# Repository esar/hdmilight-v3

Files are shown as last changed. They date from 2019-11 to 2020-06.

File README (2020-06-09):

This is a still-in-progress update to my hdmilight-v2 project.

Differences in this version:
 * Everything is on a standalone board, no longer needs a Papilio FPGA board
 * AVR CPU removed from FPGA design and replaced by a separate ARM Cortex MCU.
   The main reason for this change was to get more program memory. The FPGA
   had no more spare block RAMs. It also has the advantage of being a much
   more capable CPU and having live debugging via JTAG.
 * Power supply switching for the LEDs. This version can power down the 
   LED strips when not in use.
 * Extra pins added to each LED output port, now have +5V, DAT, GND, CLK
   Currently it still only support 3-wire LED strips, but in the future
   it should be able to support 4-wire clocked strips
 * Magical mystery connectors (vivepos / papix). The real reason I made
   this revision... a platform to experiment with my crazy ideas

Build instructions:

 1) Manufacture the HDMI receiver board that can be found in 
    the 'board' directory (KiCad format).
 2) Open the 'fpga/hdmilight.xise' project in Xilinx ISE and
    generate a bit file.
 3) Edit the files under the config directory to configure
    the LEDs.
 5) Run 'make' in the top level directory, which will do the following:
      * Build the firmware image
      * Convert the text config file to binary format
      * Append the config to the end of the FPGA bit file
      * Flash the ARM microcontroller with the firmware
      * Flash the FPGA config flash with the bit file
 8) Connect LED strips to output pins
 9) Open a serial terminal to the board 
    (running "dmesg" is useful to see names of recently added serial ports)
 10) Connect HDMI source to receiver board
 11) It should now be working. 

This version should now have feature parity with version 2, however
it has not been tested very well yet.

Useful build targets:
 * make firmware: build the firmware without flashing
 * make firmware_flash: flash the last build to the ARM
 * make fpga_program: reprogram FPGA without programming flash
                      will be lost on thxt power-cycle
 * make fpga_flash: reprogram the FPGA flash
 * make fpga_flash_config: reprogram just the configuration part of the FPGA flash

Debugging the firmware:
 1) start openocd: openocd -f hdmilight-v3-openocd.cfg
 2) start gdb: arm-none-eabi-gdb
 3) in gdb, load firmware: file firmware/main.elf
 4) in gdb, connect to board: target remote :3333

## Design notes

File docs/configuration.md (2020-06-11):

Configuration
=============

The configuration is controlled by the files in the config directory.
During the build these text files get converted to binary format by the python
scripts in the tools directory, and then they get merged together into one big
binary blob which is then written to the FPGA's flash chip.

There can be up to 64 different configurations and the HDMI Light can switch
between them automatically based on the incoming video resolution and aspect ratio.

Each of the configurations is controlled by the files in the `config/config_x`
directory, where _x_ is a number starting from 0. Each directory contains the
following config files:
* area.conf: Defines rectangular areas of the screen that should be averaged
             together to produce a colour.
* `output_x.conf`: One file for each LED output port. Defines which area and
                   colour correction data should be used to set the colour
                   of each LED connected to that port
* `colour_x.conf`: Defines each of the 8 colour correction matrices
* `gamma_r_x.conf`: Defines each of the 8 gamma curves for the red channel
* `gamma_g_x.conf`: Defines each of the 8 gamma curves for the green channel
* `gamma_b_x.conf`: Defines each of the 8 gamma curves for the blue channel
* delay.conf: Controls how much delay there is between the incoming video changing 
              and the LED colours changing

In addition to the files above, there are two global configuration files in the 
top level config directory:
* format.conf: Controls which configuration is loaded for a particular resolution
               and aspect ratio
* keys.conf: Defines the key mapping for CEC remote control actions.

The following sections describe each configuration file in detail. 

format.conf
-----------

The format configuration file contains one line for each known resolution and
aspect ratio. Each line has four columns:
* X Resolution
* Y Resolution
* Aspect ratio, which must be one of 1.33, 1.77, 2.44
* Index of the configuration to use for this resolution and aspect ratio

For example, this file defines three known formats for the three different aspect
ratios for 1920x1080
```
# width  height  ratio  config
  1920   1080    1.77   0
  1920   1080    2.40   1
  1920   1080    1.33   2
```

With this format config file the HDMI Light will use `config_0` for full screen
content, `config_1` for wide-screen content, and `config_2` for old narrow content.

When the incoming video format changes the HDMI Light will look for a matching
entry in the format config file and if it finds one then it will switch to the
specified configuration. If no matching entry is found then it will continue
to use the current configuration.

area.conf
---------

The area configuration file defines rectangular areas of the screen. The colour of
each pixel within the rectangles is averaged together to generate the colour to be
used for the LEDs.

Each line in the file contains five columns:
* xmin: The X coordinate of the left edge of the rectangle
* xmax: The X coordinate of the right edge of the rectangle
* ymin: The Y coordinate of the bottom of the rectangle
* ymax: The Y coordinate of the top of the rectangle
* divshift: How to divide the result after summing the pixels

The first four columns should be fairly self explanatory, they just define the 
coordinates of the rectangle. These coordinates use a reduced resolution compared
to the incoming video. The incoming video is scaled by 32, so for 1920x1080 the
coordinates in this are 0-59 for X, and 0-32 for Y.
The origin is the top left of the screen.

The last parameter is harder to explain. Especially if you're not familiar with how 
binary numbers operate. The averaging of the pixel colours in the rectangle is done
by summing all of the R, G and B values together and then dividing the result by the
number of pixels in the rectangle. However, a true division is a _very_ expensive
operation to perform in an FPGA, so instead we take advantage of the fact that each 
time we shift the digits of a binary number to the right, we divide the value by 2.
This last parameter defines how many places to shift the result to the right to 
perform the required division.

The following values are valid:
* 0: don't divide
* 1: divide by 2
* 2: divide by 4
* 3: divide by 8
* 4: divide by 16
* 5: divide by 32
* 6: divide by 64
* 7: divide by 128
* 8: divide by 256
* 9: divide by 512
* 10: divide by 1024
* 11: divide by 2048
* 12: divide by 4096
* 13: divide by 8192
* 14: divide by 16382
* 15: divide by 32768

As can be seen in this list, we can only divide by powers of two, so we are limited
to rectangles whose area is also a power of two, otherwise we can't get the correct 
result.

output.conf
-----------

There is one output configuration file for each of the eight LED strips that can be
connected. Each file contains one line for each LED that is connected to that port.
Each line contains five columns:
* index: The LED number. It's not actually used by anything, it's just there to make 
         life easier when manually editing the file
* area:  The index of the area to use for this LED
* colour: The index of the colour matrix that should be used for this LED
* gamma: The index of the gamma curve that should be used for this LED
* enable: Whether the LED is enabled (0=disabled, 1=enabled)

If colour correction is not being used then there are really only two important
columns: area and enable. For each LED, simply select which area from area.conf should
be used to select the colour for the LED. Then set enable to 1. 
The colour and gamma columns can be set to 0 (assuming the related config files have
been left on their default do-nothing values).

The first line in the file is the LED nearest the HDMI Light.

If colour correction is desired then the colour and gamma indices can be set to the 
relevant colour matrix and gamma curve that should be used for each LED.

One important thing to note is that the enable column cannot be used to disable individual
LEDs in the middle of a run, the column should be all 1's. If there are excess LEDs in the 
file then they can be set to 0, but there must be a continuous run of 1's followed by a 
continuous run of 0's. It is not valid to switch back and forth between 1 and 0.

If you want to switch off LEDs in the middle of a run, then a good way to do it is to
change one of the colour configurations to have brightness set to 0 for all channels.
Then simply select that colour matrix for the LEDs that you want disabled and they will
always be set to black and will not light up.

colour.conf
-----------

The colour configuration files define a colour matrix that can be used to colour correct
individual LEDs. A default do-nothing configuration file looks like this:

```
matrixR = 1.000 0.000 0.000
matrixG = 0.000 1.000 0.000
matrixB = 0.000 0.000 1.000
matrixC = 0.000 0.000 0.000

brightR = 1.0
brightG = 1.0
brightB = 1.0

contrast = 1.0

saturation = 1.0
```

The first section defines a raw matrix, in the example above it is the identity matrix
where the red output comes 100% from the red input, green 100% from green, and blue
100% from blue. The last line `matrixC` is for adding constant values to the channels
and in this case it is adding 0 to each channel.

The second section controls relative brightness of each channel. In the example above
it does nothing, each channel is 100%. This value can be increased as well as decreased.
For example setting a channel to 2.0 will multiply the brightness by 2, and setting a 
channel to 0.5 would cut the brightness in half.

Next is a contrast adjustment, and then a saturation adjustment.

The brightness, contrast, and saturation values are all converted to matrices. Then all
of these matrices are multiplied together and with the raw matrix at the top of the file
to produce a final colour correction matrix that is used to adjust the LED colours.

gamma.conf
----------

There can be 8 sets of gamma correction curves, and each set has a separate curves for 
each channel. The configuration file simply contains a single value which defines the
gamma curve. A default do-nothing file would contain the value 1.0 which defines a
straight line so that each input value results in the same value being output.

delay.conf
----------

The delay configuration file allows the output of the HDMI Light to be precisely
synchronised with the TV. By default the HDMI Light will update the LEDs immediately
when the incoming video frame ends, but modern TVs generally lag a few frames as they
do a lot of internal processing on the video.

The configuration file contains three values:
* frames: how many whole frames to delay
* ticks: how many extra microseconds to delay after the frame count
* smooth: temporal smoothing factor. 

The frames parameter should be self explanatory, it simply delays the output by the
specified number of frames. Valid values are from 0 to 8.

The ticks parameter should be ignored. There is no point in trying to set the delay
that accurately as it takes so long to clock the data out to the LED strips that the
accuracy is lost.

The final parameter is the temporal smoothing factor. It defines how much of the colour
for an LED comes from the new colour and how much comes from the previous colour.
Setting this to 0.0 will disable temporal smoothing and the colour of an LED will come
entirely from the new colour from the area on the screen.
Setting this to 0.5 will use 50% of the previous colour and 50% of the new colour.

My TV delays its output by 2 frames. I find that the following settings all give 
perfect synchronisation:
* frames = 2, smooth = 0.0
* frames = 1, smooth = 0.6
* frames = 0, smooth = 0.75

Personally I prefer the last option which makes it fade between sudden colour changes.

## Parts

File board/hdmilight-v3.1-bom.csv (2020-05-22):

Designator | Package | Quantity | Designation | Part # | Farnell # | Unit GBP | Total GBP
C116,C114,C112,C110,C108,C106,C104,C102,C100,C98,C72,C83,C82,C79 | C_0805_2012Metric | 14 | 4.7uF |  |  |  | 0
C117,C115,C113,C111,C109,C107,C105,C103,C101,C99,C86,C85,C84,C81,C80,C78,C77,C76,C75,C74,C73 | C_0402_1005Metric | 21 | 0.47uF |  |  |  | 0
C19,C20,C21 | C_0603_1608Metric | 3 | 1nF |  |  |  | 0
C22,C23,C24,C28,C29,C30 | C_0603_1608Metric | 6 | DNI |  |  |  | 0
C25,C26,C27 | C_0603_1608Metric | 3 | 0.047uF |  |  |  | 0
C3,C4 | C_0603_1608Metric | 2 | 12pF |  |  |  | 0
C36 | C_0603_1608Metric | 1 | 2.2uF |  |  |  | 0
C37 | C_0805_2012Metric | 1 | DNI |  |  |  | 0
C38,C39,C42,C44,C46,C48,C52,C54 | CP_EIA-3528-21_Kemet-B | 8 | 33uF | Kemet: T491B336K006AT | 2408593 | 0.396 | 3.168
C50,C2,C10,C11,C12,C13,C14,C15,C40,C41,C43,C45,C47,C49,C53,C55 | C_0603_1608Metric | 16 | 0.1uF |  |  |  | 0
C51,C16,C17,C18,C31,C32,C33,C34,C35 | C_0805_2012Metric | 9 | 22uF | TDK: C2012X5R1A226M085AC | 2526256 | 0.493 | 4.437
C57,C56 | C_0603_1608Metric | 2 | 18pF |  |  |  | 0
C58 | C_0603_1608Metric | 1 | 0.01uF |  |  |  | 0
C9,C118,C1,C97,C96,C95,C94,C8,C6,C93,C91,C7,C5,C92,C90,C89,C88,C87,C71,C70,C69,C68,C67,C66,C65,C64,C63,C62,C61,C60,C59 | C_0402_1005Metric | 31 | 0.1uF |  |  |  | 0
D2 | LED_0603_1608Metric | 1 | LED Green | Kingbright: KPH-1608SGC | 2426215 | 0.09 | 0.09
D5,D4 | D_SOD-323 | 2 | 2A | NXP: PMEG3020EJ,115 | 1757772 | 0.332 | 0.664
D6,D1 | LED_0603_1608Metric | 2 | LED Red | Kingbright: KPT-1608EC | 2099221 | 0.107 | 0.214
D7 | D_SOD-323 | 1 | 5V1 | On Semi: MM3Z5V1ST1G | 2317476 | 0.098 | 0.098
D8,D3 | LED_0603_1608Metric | 2 | LED Side Red | Kingbright: KPA-1606SURCK | 2290358 | 0.16 | 0.32
D9 | LED_0603_1608Metric | 1 | LED Side Green | Kingbright: KPA-1606CGCK | 2290360 | 0.17 | 0.17
F2,F1 | Fuse_1206_3216Metric | 2 | 1206L050 | Littelfuse: 1206L050YR | 1596993 | 0.285 | 0.57
FB7,FB1,FB2,FB3,FB4,FB5,FB6,FB8,FB9 | L_0805_2012Metric | 9 | 22ohm@100MHz | Murata: BLM21PG220SN1D | 1515659 | 0.055 | 0.495
J1 | USB_Micro-B_Amphenol_10103594-0001LF_Horizontal | 1 | USB_B_Micro | Amphenol: 10103594-0001LF | 2293752 | 0.44 | 0.44
J10,J6,J5,J4 | PinSocket_1x08_P2.54mm_Vertical | 4 | Conn_01x08 | Multicomp: 2212S-08SG-85 | 1593463 | 0.17 | 0.68
J11 | TerminalBlock_Phoenix_MKDS-1,5-2_1x02_P5.00mm_Horizontal | 1 | Screw_Terminal_01x02 | Phoenix: MKDS 1,5/2 | 3714240 | 1.05 | 1.05
J12,J3 | PinHeader_1x02_P2.54mm_Vertical | 2 | Conn_01x02_Male | Multicomp: MC34745 | 1593426 | 0.017 | 0.017
J13 | PinSocket_1x09_P2.54mm_Vertical | 1 | Conn_01x09 | Multicomp: 2212S-09SG-85 | 2847198 | 0.2 | 0.2
J14 | PinHeader_2x10_P2.54mm_Horizontal | 1 | Conn_02x10_Odd_Even | Amp: 1-826634-0 | 3418649 | 2.2 | 2.2
J2 | HDMI_SOCKET_FCI_10029449 | 1 | HDMI_A | Amphenol/FCI: 10029449-001RLF | 2112524 | 1.22 | 1.22
J7 | IDC-Header_2x05_P2.54mm_Horizontal | 1 | Conn_02x05_Odd_Even | Amp: 5103310-1 | 2452436 | 0.89 | 0.89
J8,J9 | RJ12_Amphenol_54601 | 2 | 6P6C | Amphenol: 54601-906WPLF | 2135977 | 0.265 | 0.53
L1,L2 | L_Bourns-SRN4018 | 2 | 4.7uH/2.1A | TDK: SPM4020T-4R7M-LR | 2564035 | 1.52 | 3.04
L3 | L_Bourns-SRN4018 | 1 | 2.2uH/3.5A | TDK: SPM4015T-2R2M-LR | 2564023 | 0.342 | 0.342
Q1 | TO-252-2 | 1 | IPD90P03P4L04 | Vishay: SUD50P04-08-GE3 | 1794811 | 1.38 | 1.38
Q5,Q2,Q4,Q3 | SOT-23 | 4 | BSS123 | On Semi: BSS123 | 9845321 | 0.254 | 0.762
R13 | R_0603_1608Metric | 1 | 27K |  |  |  | 0
R14,R15,R18,R19,R20,R48,R51 | R_0603_1608Metric | 7 | 47K |  |  |  | 0
R2,R3 | R_0603_1608Metric | 2 | 27R |  |  |  | 0
R39 | R_0603_1608Metric | 1 | 15K |  |  |  | 0
R40 | R_0603_1608Metric | 1 | 33K |  |  |  | 0
R42 | R_0603_1608Metric | 1 | 150R |  |  |  | 0
R43 | R_0603_1608Metric | 1 | 18K |  |  |  | 0
R49 | R_0603_1608Metric | 1 | 20K |  |  |  | 0
R5 | R_0603_1608Metric | 1 | 1K5 |  |  |  | 0
R55,R54,R53 | R_0603_1608Metric | 3 | 4K7 |  |  |  | 0
R57,R56,R69,R44,R41,R4,R16,R45,R46,R47,R50,R22 | R_0603_1608Metric | 12 | 10K |  |  |  | 0
R58,R60,R21,R1,R52 | R_0603_1608Metric | 5 | 2K2 |  |  |  | 0
R59,R17 | R_0603_1608Metric | 2 | 100K |  |  |  | 0
R6 | R_0603_1608Metric | 1 | 470R |  |  |  | 0
R68,R67,R66,R65,R64,R63,R62,R61,R23,R24,R25,R26,R27,R28,R29,R30,R31,R32,R33,R34,R35,R36,R37,R38 | R_0603_1608Metric | 24 | 82R |  |  |  | 0
R7,R8,R9 | R_0603_1608Metric | 3 | 68R |  |  |  | 0
R70 | R_0603_1608Metric | 1 | 330R |  |  |  | 0
R71,R10,R11,R12 | R_0603_1608Metric | 4 | 1K |  |  |  | 0
RV1 | R_0603_1608Metric | 1 | V5.5MLA0603H | Littelfuse: V5.5MLA0603H | 1757273 | 0.36 | 0.36
SW1 | SW_SPST_EVQP0 | 1 | SW_Push |  |  |  | 0
SW2 | SW_Tactile_SPST_Angled_PTS645Vx31-2LFS | 1 | SW_Push | C&K: PTS645VH58-2LFS | 2320088 | 0.201 | 0.201
U1 | LQFP-64_10x10mm_P0.5mm | 1 | STM32F303RETx | ST Micro: STM32F303RET6 | 2466939 | 6.56 | 6.56
U12 | QFN-32-1EP_5x5mm_P0.5mm_EP3.1x3.1mm_ThermalVias | 1 | TPS65266 | Texas: TPS65266RHBT | 2471151 | 3.92 | 3.92
U2 | SOIC-8_3.9x4.9mm_P1.27mm | 1 | DNI | Microchip: 93C46BT-I/SN | 1607557 | 0.18 | 0.18
U3 | LQFP-48_7x7mm_P0.5mm | 1 | FT2232D | FTDI: FT2232D | 1615843 | 5.7 | 5.7
U4 | LQFP-64-1EP_10x10mm_P0.5mm_EP6.5x6.5mm_ThermalVias | 1 | ADV7611 | Analog: ADV7611 |  | 6.5 | 6.5
U5 | TQFP-144_20x20mm_P0.5mm | 1 | XC6SLX9-TQG144 | Xilinx: XC6SLX9-2TQG144C | 2763358 | 14.91 | 14.91
U6 | TSSOP-38_4.4x9.7mm_P0.5mm | 1 | TPD12S520 | Texas: TPD12S520DBTR | 3116492 | 1.19 | 1.19
U7 | SOIC-8_5.23x5.23mm_P1.27mm | 1 | S25FL064L | Cypress: S25FL064LABMFI010 | 2768034 | 1.68 | 1.68
U8,U9,U10,U11 | TSSOP-20_4.4x6.5mm_P0.65mm | 4 | 74LVC245 | Texas: SN74LVC245APW | 2342392 | 0.626 | 2.504
X1 | Oscillator_SMD_Abracon_ASE-4Pin_3.2x2.5mm | 1 | SG-310SCF-32MHz | Multicomp: MCSJK-3N-32.00-3.3-25-B | 2425493 | 0.639 | 0.639
Y1 | Crystal_SMD_7050-4Pin_7.0x5.0mm | 1 | 6MHz / 12pF | Euroquartz: 6.000MHZ MQ/30/30/-40+90/12PF | 1640909 | 1.73 | 1.73
Y2 | Crystal_SMD_5032-2Pin_5.0x3.2mm | 1 | 28.63636MHz / 18pF | TXC: 7A-28.63636MAAJ-T | 1841958 | 0.665 | 0.665
TOTAL |  | 249 |  |  |  |  | 69.716

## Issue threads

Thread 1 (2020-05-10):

Need some readme file like hdmilight-v2

xfce, 2020-05-10:
Hi @esar ,
    So i think I can fellow the v3 hdmilight.
Now for FPGA I can use xilinx ise got the fpga/HdmilightTop.bit
and what is the next steps?
When got the v3 hardware, Plug into  PC usb and In the top level directory, type
make fpga_program
fpga_flash
make v2_all

esar, 2020-05-10:
I've updated the makefiles to make them a bit more user friendly and updated the README with the current instructions.

xfce, 2020-05-11:
@esar OK, Thanks.
I will use your board, Does the v3.1 gerber file good for manufacture.

esar, 2020-05-11:
I don't know yet, I'm waiting for boards to arrive so that I can test it. Hopefully they won't take too long to arrive.

xfce, 2020-05-14:
OK, thanks. I have order 5pcs boards use v3.1 gerber, and will fellow with you^-^

esar, 2020-05-19:
@xfce My boards arrived and I spent the weekend populating and testing one. It looks like the PCB design is ok, I've not found any issues with that yet.
In case you find it useful, I've added a wiki page detailing the steps that I took to test the board:
https://github.com/esar/hdmilight-v3/wiki/V3.1-Board-Testing-Notes

xfce, 2020-05-20:
@esar  OK , Thanks. Actually , My have also arrived, and waiting for your wiki ^-^
Bellow is the PCB, left is HDMILIGHT V3.1, right is my other PCB
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

xfce, 2020-05-27:
@esar Hi, I have solder most of the components.
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

And also I still want to try the HDMILIGHT V2.0, as it seems much simple , so I have draw the schematics , could you please help me to review it, thanks. bellow is the schematic file.

https://www.dropbox.com/s/ve5g6pb5ufv5kbx/HDMILIGHT_V2.pdf?dl=0

esar, 2020-05-27:
@xfce Cool, looking good!

I've only had time to take a quick look at your schematic, so I've not checked all the connections, but what I have checked looks good. I just have a couple of things to mention:
1) Xilinx recommend a strong pull up on the DONE pin. I can't remember for sure and don't have the Papilio Pro schematic to hand, but I'm guessing that you're copying what was done there, in which case it should be fine. I had no problem using the Papilio board. Here's where Xilinx recommend it: https://www.xilinx.com/support/answers/35002.html

2) The data and clock pairs on the in and out side of the ESD protection chip need to be connected together. There needs to be traces under the chip as the chip doesn't pass them through, it just clamps them. Maybe the software you're using allows you to route them without them connected in the schematic?

3) You don't need the eeprom attached to the FTDI chip. At least JTAG and serial both work without it when using openocd. I've not tried without it when using the Papilio loader software that I used with v2 though.

4) I don't know how familiar you are with FPGAs... keep in mind that you can be quite flexible with the FPGA pins used to connect to the ADV7611. You can change the mapping in the .ucf file in the fpga directory. It's nice to be able to swap them around sometimes when it makes routing the board easier. The only pin that is really restricted is the LLC pin from the ADV7611. This is the video clock and it should be kept on one of the FPGA pins that is connected to a global clock network within the FPGA (the ones with GCLK in their pin name).

Closed 2020-05-14.

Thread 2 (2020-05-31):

make error

xfce, 2020-05-31:
Hi @esar,
    I have finished the V3 board, seems STM32F303 and FTDI are OK, spart6 partly OK .
When I type make, got some error, as bellow, please give some advise, thanks

bi4wms@bi4wms-ThinkPad-X230:~/projects/hdmilight-v3$  make
make -C firmware size
make[1]: Entering directory '/home/bi4wms/projects/hdmilight-v3/firmware'
arm-none-eabi-gcc -c -fno-common -Os -g3 -mcpu=cortex-m4 -mthumb -mfpu=fpv4-sp-d16 -mfloat-abi=hard -std=gnu99 -Wall -ffunction-sections -fdata-sections -fno-builtin -Wno-unused-function -ffreestanding -DSTM32F303xE -I../../STM32Cube_FW_F3_V1.10.0/Drivers/CMSIS//Include/ -I../../STM32Cube_FW_F3_V1.10.0/Drivers/CMSIS//Device/ST/STM32F3xx/Include/ -I./   -c -o main.o main.c
arm-none-eabi-gcc -c -fno-common -Os -g3 -mcpu=cortex-m4 -mthumb -mfpu=fpv4-sp-d16 -mfloat-abi=hard -std=gnu99 -Wall -ffunction-sections -fdata-sections -fno-builtin -Wno-unused-function -ffreestanding -DSTM32F303xE -I../../STM32Cube_FW_F3_V1.10.0/Drivers/CMSIS//Include/ -I../../STM32Cube_FW_F3_V1.10.0/Drivers/CMSIS//Device/ST/STM32F3xx/Include/ -I./   -c -o clock.o clock.c
arm-none-eabi-gcc -c -fno-common -Os -g3 -mcpu=cortex-m4 -mthumb -mfpu=fpv4-sp-d16 -mfloat-abi=hard -std=gnu99 -Wall -ffunction-sections -fdata-sections -fno-builtin -Wno-unused-function -ffreestanding -DSTM32F303xE -I../../STM32Cube_FW_F3_V1.10.0/Drivers/CMSIS//Include/ -I../../STM32Cube_FW_F3_V1.10.0/Drivers/CMSIS//Device/ST/STM32F3xx/Include/ -I./   -c -o power.o power.c
arm-none-eabi-gcc -c -fno-common -Os -g3 -mcpu=cortex-m4 -mthumb -mfpu=fpv4-sp-d16 -mfloat-abi=hard -std=gnu99 -Wall -ffunction-sections -fdata-sections -fno-builtin -Wno-unused-function -ffreestanding -DSTM32F303xE -I../../STM32Cube_FW_F3_V1.10.0/Drivers/CMSIS//Include/ -I../../STM32Cube_FW_F3_V1.10.0/Drivers/CMSIS//Device/ST/STM32F3xx/Include/ -I./   -c -o standby.o standby.c
arm-none-eabi-gcc -c -fno-common -Os -g3 -mcpu=cortex-m4 -mthumb -mfpu=fpv4-sp-d16 -mfloat-abi=hard -std=gnu99 -Wall -ffunction-sections -fdata-sections -fno-builtin -Wno-unused-function -ffreestanding -DSTM32F303xE -I../../STM32Cube_FW_F3_V1.10.0/Drivers/CMSIS//Include/ -I../../STM32Cube_FW_F3_V1.10.0/Drivers/CMSIS//Device/ST/STM32F3xx/Include/ -I./   -c -o uart.o uart.c
arm-none-eabi-gcc -c -fno-common -Os -g3 -mcpu=cortex-m4 -mthumb -mfpu=fpv4-sp-d16 -mfloat-abi=hard -std=gnu99 -Wall -ffunction-sections -fdata-sections -fno-builtin -Wno-unused-function -ffreestanding -DSTM32F303xE -I../../STM32Cube_FW_F3_V1.10.0/Drivers/CMSIS//Include/ -I../../STM32Cube_FW_F3_V1.10.0/Drivers/CMSIS//Device/ST/STM32F3xx/Include/ -I./   -c -o printf.o printf.c
arm-none-eabi-gcc -c -fno-common -Os -g3 -mcpu=cortex-m4 -mthumb -mfpu=fpv4-sp-d16 -mfloat-abi=hard -std=gnu99 -Wall -ffunction-sections -fdata-sections -fno-builtin -Wno-unused-function -ffreestanding -DSTM32F303xE -I../../STM32Cube_FW_F3_V1.10.0/Drivers/CMSIS//Include/ -I../../STM32Cube_FW_F3_V1.10.0/Drivers/CMSIS//Device/ST/STM32F3xx/Include/ -I./   -c -o adv7611.o adv7611.c
arm-none-eabi-gcc -c -fno-common -Os -g3 -mcpu=cortex-m4 -mthumb -mfpu=fpv4-sp-d16 -mfloat-abi=hard -std=gnu99 -Wall -ffunction-sections -fdata-sections -fno-builtin -Wno-unused-function -ffreestanding -DSTM32F303xE -I../../STM32Cube_FW_F3_V1.10.0/Drivers/CMSIS//Include/ -I../../STM32Cube_FW_F3_V1.10.0/Drivers/CMSIS//Device/ST/STM32F3xx/Include/ -I./   -c -o fpga.o fpga.c
arm-none-eabi-gcc -c -fno-common -Os -g3 -mcpu=cortex-m4 -mthumb -mfpu=fpv4-sp-d16 -mfloat-abi=hard -std=gnu99 -Wall -ffunction-sections -fdata-sections -fno-builtin -Wno-unused-function -ffreestanding -DSTM32F303xE -I../../STM32Cube_FW_F3_V1.10.0/Drivers/CMSIS//Include/ -I../../STM32Cube_FW_F3_V1.10.0/Drivers/CMSIS//Device/ST/STM32F3xx/Include/ -I./   -c -o fixed_point.o fixed_point.c
arm-none-eabi-gcc -c -fno-common -Os -g3 -mcpu=cortex-m4 -mthumb -mfpu=fpv4-sp-d16 -mfloat-abi=hard -std=gnu99 -Wall -ffunction-sections -fdata-sections -fno-builtin -Wno-unused-function -ffreestanding -DSTM32F303xE -I../../STM32Cube_FW_F3_V1.10.0/Drivers/CMSIS//Include/ -I../../STM32Cube_FW_F3_V1.10.0/Drivers/CMSIS//Device/ST/STM32F3xx/Include/ -I./   -c -o format.o format.c
arm-none-eabi-gcc -c -fno-common -Os -g3 -mcpu=cortex-m4 -mthumb -mfpu=fpv4-sp-d16 -mfloat-abi=hard -std=gnu99 -Wall -ffunction-sections -fdata-sections -fno-builtin -Wno-unused-function -ffreestanding -DSTM32F303xE -I../../STM32Cube_FW_F3_V1.10.0/Drivers/CMSIS//Include/ -I../../STM32Cube_FW_F3_V1.10.0/Drivers/CMSIS//Device/ST/STM32F3xx/Include/ -I./   -c -o cmd_area.o cmd_area.c
arm-none-eabi-gcc -c -fno-common -Os -g3 -mcpu=cortex-m4 -mthumb -mfpu=fpv4-sp-d16 -mfloat-abi=hard -std=gnu99 -Wall -ffunction-sections -fdata-sections -fno-builtin -Wno-unused-function -ffreestanding -DSTM32F303xE -I../../STM32Cube_FW_F3_V1.10.0/Drivers/CMSIS//Include/ -I../../STM32Cube_FW_F3_V1.10.0/Drivers/CMSIS//Device/ST/STM32F3xx/Include/ -I./   -c -o cmd_colour.o cmd_colour.c
arm-none-eabi-gcc -c -fno-common -Os -g3 -mcpu=cortex-m4 -mthumb -mfpu=fpv4-sp-d16 -mfloat-abi=hard -std=gnu99 -Wall -ffunction-sections -fdata-sections -fno-builtin -Wno-unused-function -ffreestanding -DSTM32F303xE -I../../STM32Cube_FW_F3_V1.10.0/Drivers/CMSIS//Include/ -I../../STM32Cube_FW_F3_V1.10.0/Drivers/CMSIS//Device/ST/STM32F3xx/Include/ -I./   -c -o cmd_delay.o cmd_delay.c
arm-none-eabi-gcc -c -fno-common -Os -g3 -mcpu=cortex-m4 -mthumb -mfpu=fpv4-sp-d16 -mfloat-abi=hard -std=gnu99 -Wall -ffunction-sections -fdata-sections -fno-builtin -Wno-unused-function -ffreestanding -DSTM32F303xE -I../../STM32Cube_FW_F3_V1.10.0/Drivers/CMSIS//Include/ -I../../STM32Cube_FW_F3_V1.10.0/Drivers/CMSIS//Device/ST/STM32F3xx/Include/ -I./   -c -o cmd_format.o cmd_format.c
arm-none-eabi-gcc -c -fno-common -Os -g3 -mcpu=cortex-m4 -mthumb -mfpu=fpv4-sp-d16 -mfloat-abi=hard -std=gnu99 -Wall -ffunction-sections -fdata-sections -fno-builtin -Wno-unused-function -ffreestanding -DSTM32F303xE -I../../STM32Cube_FW_F3_V1.10.0/Drivers/CMSIS//Include/ -I../../STM32Cube_FW_F3_V1.10.0/Drivers/CMSIS//Device/ST/STM32F3xx/Include/ -I./   -c -o cmd_gamma.o cmd_gamma.c
arm-none-eabi-gcc -c -fno-common -Os -g3 -mcpu=cortex-m4 -mthumb -mfpu=fpv4-sp-d16 -mfloat-abi=hard -std=gnu99 -Wall -ffunction-sections -fdata-sections -fno-builtin -Wno-unused-function -ffreestanding -DSTM32F303xE -I../../STM32Cube_FW_F3_V1.10.0/Drivers/CMSIS//Include/ -I../../STM32Cube_FW_F3_V1.10.0/Drivers/CMSIS//Device/ST/STM32F3xx/Include/ -I./   -c -o cmd_i2c.o cmd_i2c.c
arm-none-eabi-gcc -c -fno-common -Os -g3 -mcpu=cortex-m4 -mthumb -mfpu=fpv4-sp-d16 -mfloat-abi=hard -std=gnu99 -Wall -ffunction-sections -fdata-sections -fno-builtin -Wno-unused-function -ffreestanding -DSTM32F303xE -I../../STM32Cube_FW_F3_V1.10.0/Drivers/CMSIS//Include/ -I../../STM32Cube_FW_F3_V1.10.0/Drivers/CMSIS//Device/ST/STM32F3xx/Include/ -I./   -c -o cmd_keys.o cmd_keys.c
arm-none-eabi-gcc -c -fno-common -Os -g3 -mcpu=cortex-m4 -mthumb -mfpu=fpv4-sp-d16 -mfloat-abi=hard -std=gnu99 -Wall -ffunction-sections -fdata-sections -fno-builtin -Wno-unused-function -ffreestanding -DSTM32F303xE -I../../STM32Cube_FW_F3_V1.10.0/Drivers/CMSIS//Include/ -I../../STM32Cube_FW_F3_V1.10.0/Drivers/CMSIS//Device/ST/STM32F3xx/Include/ -I./   -c -o cmd_output.o cmd_output.c
arm-none-eabi-gcc -c -fno-common -Os -g3 -mcpu=cortex-m4 -mthumb -mfpu=fpv4-sp-d16 -mfloat-abi=hard -std=gnu99 -Wall -ffunction-sections -fdata-sections -fno-builtin -Wno-unused-function -ffreestanding -DSTM32F303xE -I../../STM32Cube_FW_F3_V1.10.0/Drivers/CMSIS//Include/ -I../../STM32Cube_FW_F3_V1.10.0/Drivers/CMSIS//Device/ST/STM32F3xx/Include/ -I./   -c -o cmd_mem.o cmd_mem.c
arm-none-eabi-gcc -c -fno-common -Os -g3 -mcpu=cortex-m4 -mthumb -mfpu=fpv4-sp-d16 -mfloat-abi=hard -std=gnu99 -Wall -ffunction-sections -fdata-sections -fno-builtin -Wno-unused-function -ffreestanding -DSTM32F303xE -I../../STM32Cube_FW_F3_V1.10.0/Drivers/CMSIS//Include/ -I../../STM32Cube_FW_F3_V1.10.0/Drivers/CMSIS//Device/ST/STM32F3xx/Include/ -I./   -c -o cmd_addr.o cmd_addr.c
arm-none-eabi-gcc -c -fno-common -Os -g3 -mcpu=cortex-m4 -mthumb -mfpu=fpv4-sp-d16 -mfloat-abi=hard -std=gnu99 -Wall -ffunction-sections -fdata-sections -fno-builtin -Wno-unused-function -ffreestanding -DSTM32F303xE -I../../STM32Cube_FW_F3_V1.10.0/Drivers/CMSIS//Include/ -I../../STM32Cube_FW_F3_V1.10.0/Drivers/CMSIS//Device/ST/STM32F3xx/Include/ -I./   -c -o cmd_result.o cmd_result.c
arm-none-eabi-gcc -c -fno-common -Os -g3 -mcpu=cortex-m4 -mthumb -mfpu=fpv4-sp-d16 -mfloat-abi=hard -std=gnu99 -Wall -ffunction-sections -fdata-sections -fno-builtin -Wno-unused-function -ffreestanding -DSTM32F303xE -I../../STM32Cube_FW_F3_V1.10.0/Drivers/CMSIS//Include/ -I../../STM32Cube_FW_F3_V1.10.0/Drivers/CMSIS//Device/ST/STM32F3xx/Include/ -I./   -c -o cmd_status.o cmd_status.c
arm-none-eabi-gcc -c -fno-common -Os -g3 -mcpu=cortex-m4 -mthumb -mfpu=fpv4-sp-d16 -mfloat-abi=hard -std=gnu99 -Wall -ffunction-sections -fdata-sections -fno-builtin -Wno-unused-function -ffreestanding -DSTM32F303xE -I../../STM32Cube_FW_F3_V1.10.0/Drivers/CMSIS//Include/ -I../../STM32Cube_FW_F3_V1.10.0/Drivers/CMSIS//Device/ST/STM32F3xx/Include/ -I./   -c -o papix/pos_sensors.o papix/pos_sensors.c
papix/pos_sensors.c: In function 'sensorIrqHandler':
papix/pos_sensors.c:185:14: warning: passing argument 1 of 'ootxAddBit' discards 'volatile' qualifier from pointer target type [-Wdiscarded-qualifiers]
   ootxAddBit(&sensor->ootx[lighthouse], PULSE_DATA_DATA(data));
              ^
papix/pos_sensors.c:76:6: note: expected 'ootx_t * {aka struct <anonymous> *}' but argument is of type 'volatile ootx_t * {aka volatile struct <anonymous> *}'
 void ootxAddBit(ootx_t* ootx, uint8_t bit)
      ^~~~~~~~~~
papix/pos_sensors.c: In function 'posSensorsPoll':
papix/pos_sensors.c:237:19: warning: initialization discards 'volatile' qualifier from pointer target type [-Wdiscarded-qualifiers]
    ootx_t* ootx = &g_sensors[sensorIndex].ootx[lighthouseIndex];
                   ^
papix/pos_sensors.c:242:5: warning: implicit declaration of function 'memcpy' [-Wimplicit-function-declaration]
     memcpy(g_lighthouseOotx[lighthouseIndex].data,
     ^~~~~~
papix/pos_sensors.c:216:13: warning: unused variable 'call' [-Wunused-variable]
  static int call = 0;
             ^~~~
At top level:
papix/pos_sensors.c:216:13: warning: 'call' defined but not used [-Wunused-variable]
arm-none-eabi-gcc -c -fno-common -Os -g3 -mcpu=cortex-m4 -mthumb -mfpu=fpv4-sp-d16 -mfloat-abi=hard -std=gnu99 -Wall -ffunction-sections -fdata-sections -fno-builtin -Wno-unused-function -ffreestanding -DSTM32F303xE -I../../STM32Cube_FW_F3_V1.10.0/Drivers/CMSIS//Include/ -I../../STM32Cube_FW_F3_V1.10.0/Drivers/CMSIS//Device/ST/STM32F3xx/Include/ -I./   -c -o papix/position.o papix/position.c
arm-none-eabi-gcc -c -fno-common -Os -g3 -mcpu=cortex-m4 -mthumb -mfpu=fpv4-sp-d16 -mfloat-abi=hard -std=gnu99 -Wall -ffunction-sections -fdata-sections -fno-builtin -Wno-unused-function -ffreestanding -DSTM32F303xE -I../../STM32Cube_FW_F3_V1.10.0/Drivers/CMSIS//Include/ -I../../STM32Cube_FW_F3_V1.10.0/Drivers/CMSIS//Device/ST/STM32F3xx/Include/ -I./   -c -o system_stm32f3xx.o system_stm32f3xx.c
arm-none-eabi-as   -o startup_stm32f303xe.o startup_stm32f303xe.s
arm-none-eabi-gcc -Tstm32f303ret.ld -Wl,--gc-sections -mcpu=cortex-m4 -mthumb -mfpu=fpv4-sp-d16 -mfloat-abi=hard -o main.elf main.o clock.o power.o standby.o uart.o printf.o adv7611.o fpga.o fixed_point.o format.o cmd_area.o cmd_colour.o cmd_delay.o cmd_format.o cmd_gamma.o cmd_i2c.o cmd_keys.o cmd_output.o cmd_mem.o cmd_addr.o cmd_result.o cmd_status.o papix/pos_sensors.o papix/position.o system_stm32f3xx.o startup_stm32f303xe.o
arm-none-eabi-size main.elf
   text	   data	    bss	    dec	    hex	filename
  20976	   1132	   3664	  25772	   64ac	main.elf
make[1]: Leaving directory '/home/bi4wms/projects/hdmilight-v3/firmware'
make -C config
make[1]: Entering directory '/home/bi4wms/projects/hdmilight-v3/config'
../tools/format2bin.py format.conf > format.bin
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

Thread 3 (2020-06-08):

LED strips connection order

xfce, 2020-06-08:
Hi @esar
    If I want to change the LED strips connection order, for example from left(bottom to top)->top(left to right)->right(top to bottom)->bottom(right to left), how can I use the configgenerate? Thanks

esar, 2020-06-08:
@xfce I've never used the ConfigGenerate script. It was written by someone else and I added it to the repo in case anyone else found it useful.

I've always written the config files by hand. I can describe how the configuration files work if that would be useful.

xfce, 2020-06-09:
OK, right now， I am use the ConfigGenerate script, it works well, but I can't understand the detail, also it says the script can't handle LEDs more than 512, and have the fixed connect order.
So, could you please explain how to write arer.conf and output_n.conf, thanks @esar

esar, 2020-06-09:
@xfce I've added a new file describing how the configuration files work:
https://github.com/esar/hdmilight-v3/blob/master/docs/configuration.md

Let me know if anything doesn't make sense or needs clarifying

xfce, 2020-06-11:
Hi @esar ,
 I have read the configuration.md, and write my area.conf and output, please help to review, thanks
LED strip from top(left-right:32 LED)-right(top-bottom:19 LED)-bottom(right-left:32 LED)-left(bottom-top:19 LED)

### **area.conf**
# LED strip start：Top Row running left to right： 32 LEDs
# xmin  xmax  ymin  ymax  divshift
  0     0     27    34    3
  0     1     27    34    3 
  2     3     27    34    3
  4     5     27    34    3
  6     7     27    34    3
  8     9     27    34    3
  10    11    27    34    3
  12    13    27    34    3
  14    15    27    34    3
  16    17    27    34    3
  18    19    27    34    3
  20    21    27    34    3
  22    23    27    34    3
  24    25    27    34    3
  26    27    27    34    3
  28    29    27    34    3
  30    31    27    34    3
  32    33    27    34    3
  34    35    27    34    3
  36    37    27    34    3
  38    39    27    34    3
  40    41    27    34    3
  42    43    27    34    3
  44    45    27    34    3
  46    47    27    34    3
  48    49    27    34    3
  50    51    27    34    3
  52    53    27    34    3
  54    55    27    34    3
  56    57    27    34    3
  58    58    27    34    3
  59    59    27    34    3
# Right Column running top to bottom ： 19 LEDS
# xmin  xmax  ymin  ymax  divshift
  52    59    33    33    3
  52    59    32    33    3
  52    59    30    31    3
  52    59    28    29    3
  52    59    26    27    3
  52    59    24    25    3
  52    59    22    23    3
  52    59    20    21    3
  52    59    18    19    3
  52    59    16    17    3
  52    59    14    15    3
  52    59    12    13    3
  52    59    10    11    3
  52    59    8     9     3
  52    59    6     7     3
  52    59    4     5     3
  52    59    2     3     3
  52    59    0     1     3
  52    59    0     0     3
# Bottom Row running right to left : 32 LEDS
# xmin  xmax  ymin  ymax  divshift
  59    59    27    34    3
  58    59    27    34    3
  56    57    27    34    3
  54    55    27    34    3
  52    53    27    34    3
  50    51    27    34    3
  48    49    27    34    3
  46    47    27    34    3
  44    45    27    34    3
  42    43    27    34    3
  40    41    27    34    3
  38    39    27    34    3
  36    37    27    34    3
  34    35    27    34    3
  32    33    27    34    3
  30    31    27    34    3
  28    29    27    34    3
  26    27    27    34    3
  24    25    27    34    3
  22    23    27    34    3
  20    21    27    34    3
  18    19    27    34    3
  16    17    27    34    3
  14    15    27    34    3
  12    13    27    34    3
  10    11    27    34    3
  8     9     27    34    3
  6     7     27    34    3
  4     5     27    34    3
  2     3     27    34    3
  0     1     27    34    3
  0     0     27    34    3
# Left Column running bottom to top :19 LEDS
# xmin  xmax  ymin  ymax  divshift
  0     7     0     0     3
  0     7     0     1     3
  0     7     2     3     3
  0     7     4     5     3
  0     7     6     7     3
  0     7     8     9     3
  0     7     10    11    3
  0     7     12    13    3
  0     7     14    15    3
  0     7     16    17    3
  0     7     18    19    3
  0     7     20    21    3
  0     7     22    23    3
  0     7     24    25    3
  0     7     26    27    3
  0     7     28    29    3
  0     7     30    31    3
  0     7     32    33    3
  0     7     34    34    3

###    **output.conf**
# index    area    colour    gamma    enable
      0       0         1        1         1
      1       1         1        1         1
      2       2         1        1         1
      3       3         1        1         1
      4       4         1        1         1
      5       5         1        1         1
      6       6         1        1         1
      7       7         1        1         1
      8       8         1        1         1
      9       9         1        1         1
     10      10         1        1         1
     11      11         1        1         1
     12      12         1        1         1
     13      13         1        1         1
     14      14         1        1         1
     15      15         1        1         1
     16      16         1        1         1
     17      17         1        1         1
     18      18         1        1         1
     19      19         1        1         1
     20      20         1        1         1
     21      21         1        1         1
     22      22         1        1         1
     23      23         1        1         1
     24      24         1        1         1
     25      25         1        1         1
     26      26         1        1         1
     27      27         1        1         1
     28      28         1        1         1
     29      29         1        1         1
     30      30         1        1         1
     31      31         1        1         1
     32      32         1        1         1
     33      33         1        1         1
     34      34         1        1         1
     35      35         1        1         1
     36      36         1        1         1
     37      37         1        1         1
     38      38         1        1         1
     39      39         1        1         1
     40      40         1        1         1
     41      41         1        1         1
     42      42         1        1         1
     43      43         1        1         1
     44      44         1        1         1
     45      45         1        1         1
     46      46         1        1         1
     47      47         1        1         1
     48      48         1        1         1
     49      49         1        1         1
     50      50         1        1         1
     51      51         1        1         1
     52      52         1        1         1
     53      53         1        1         1
     54      54         1        1         1
     55      55         1        1         1
     56      56         1        1         1
     57      57         1        1         1
     58      58         1        1         1
     59      59         1        1         1
     60      60         1        1         1
     61      61         1        1         1
     62      62         1        1         1
     63      63         1        1         1
     64      64         1        1         1
     65      65         1        1         1
     66      66         1        1         1
     67      67         1        1         1
     68      68         1        1         1
     69      69         1        1         1
     70      70         1        1         1
     71      71         1        1         1
     72      72         1        1         1
     73      73         1        1         1
     74      74         1        1         1
     75      75         1        1         1
     76      76         1        1         1
     77      77         1        1         1
     78      78         1        1         1
     79      79         1        1         1
     80      80         1        1         1
     81      81         1        1         1
     82      82         1        1         1
     83      83         1        1         1
     84      84         1        1         1
     85      85         1        1         1
     86      86         1        1         1
     87      87         1        1         1
     88      88         1        1         1
     89      89         1        1         1
     90      90         1        1         1
     91      91         1        1         1
     92      92         1        1         1
     93      93         1        1         1
     94      94         1        1         1
     95      95         1        1         1
     96      96         1        1         1
     97      97         1        1         1
     98      98         1        1         1
     99      99         1        1         1
    100     100         1        1         1
    101     101         1        1         1
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
esar, 2020-06-11:
@xfce I made a mistake in the doc, the origin is at the top left of the screen, not at the bottom left as I wrote in the doc.

Other than the coordinates being wrong because of the bad doc, I can see a couple of minor issues:
1) With the rectangles that you have defined in area.conf you need to increase the divshift parameter from 3 to 4. For example, you have this rectangle:
0 1 27 34 3
This rectangle contains 16 scaled pixels, so you need divshift set to 4 so that it divides the summed pixel values by 16.

2) You can leave out the extra unused pixels from the output.conf file. This would be the same as setting the enabled column to 0 and the HDMI Light will not try to send data for them.
How you have it now will still work, but it will be sending more data than it needs to.

When I created my config I found it useful to switch between 2 test images, one with horizontal coloured
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

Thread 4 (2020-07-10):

4K support

xfce, 2020-07-10:
Hi @esar ,do you have the plan to support 4K signal, If you have the plan, i would like to help with the PCBA design，and give the demo hardware for you😊

esar, 2020-07-11:
Hi @xfce, no I don't currently have any plans to support 4k. I don't have a 4k TV. Maybe I might add support if I get a new TV in the future, but it won't be any time soon.

wyntrblue, 2023-11-30:
Hi @xfce  this is a truely brilliant project. Don’t suppose you have moved to 4K since 2020?

Closed 2021-09-21.

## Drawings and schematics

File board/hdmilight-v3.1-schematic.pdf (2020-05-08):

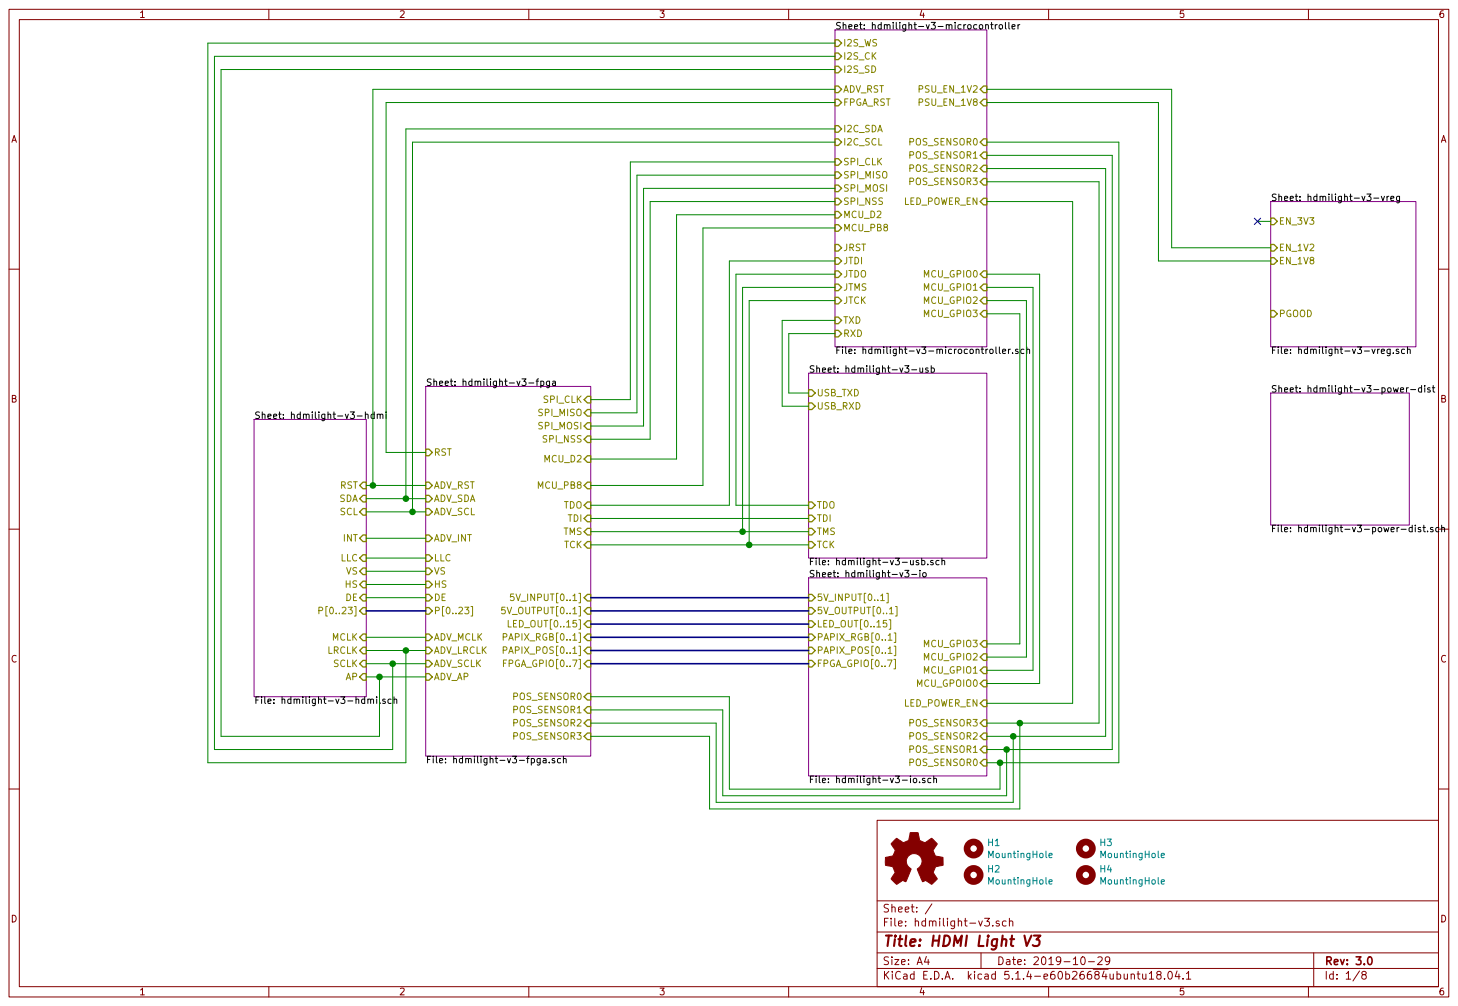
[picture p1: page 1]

File: hdmilight-v3-vreg.sch EN_1V2 PGOOD

USB_TXD
File: hdmilight-v3-usb.sch USB_RXD

File: hdmilight-v3-power-dist.sch

File: hdmilight-v3-hdmi.sch

File: hdmilight-v3-fpga.sch

File: hdmilight-v3-io.sch

File: hdmilight-v3.sch Sheet: /
Id: 1/8 Title: HDMI Light V3

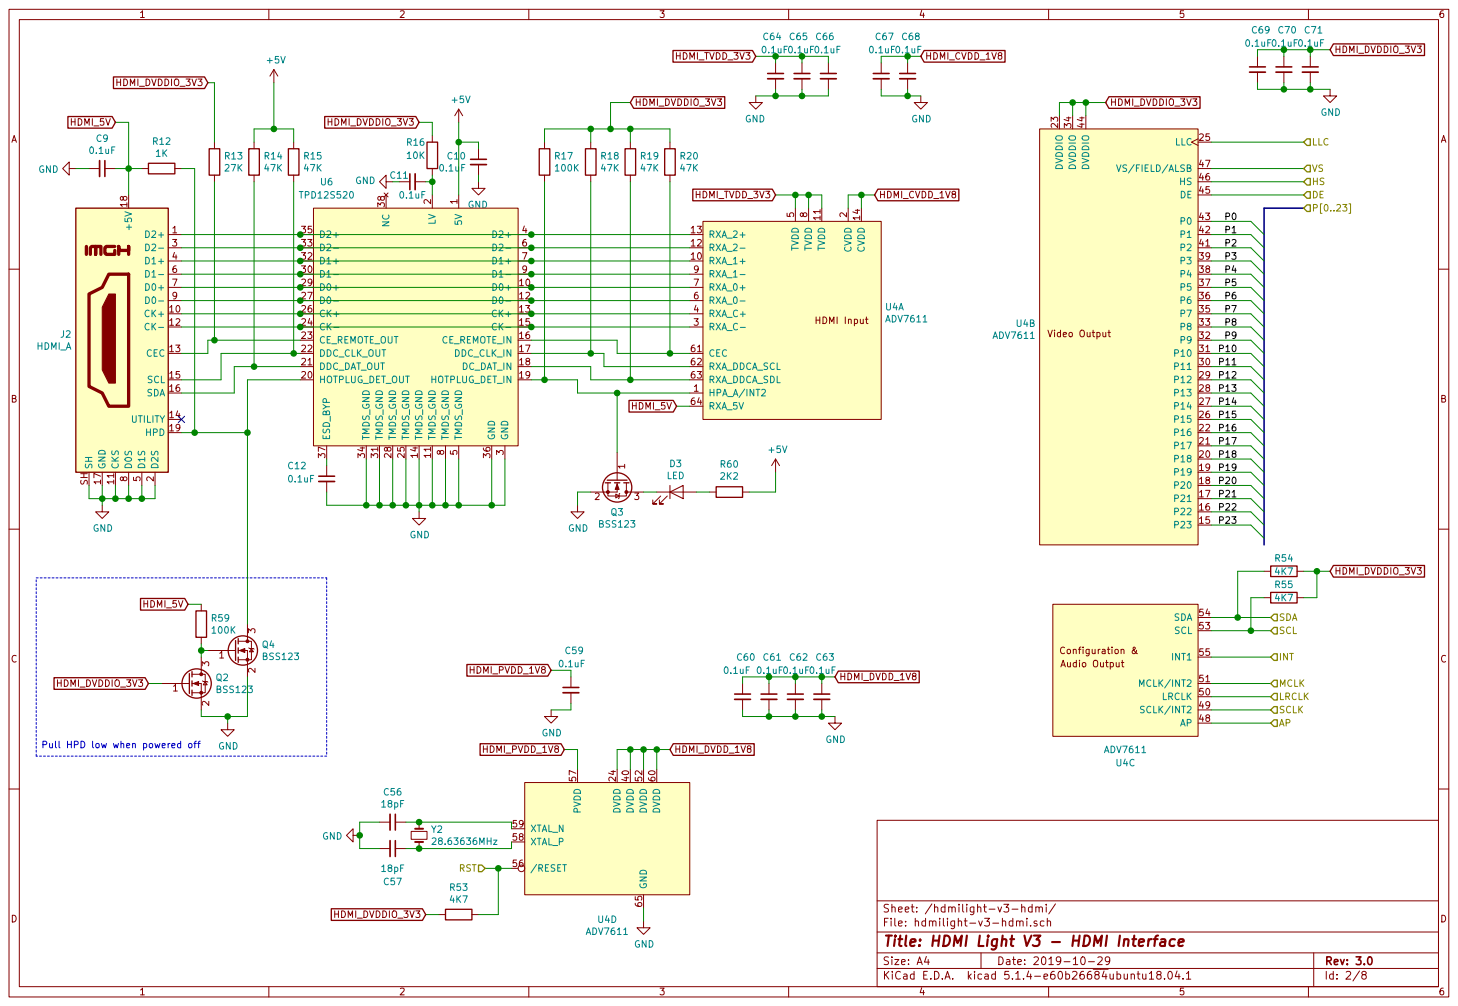
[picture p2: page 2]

Sheet: /hdmilight-v3-hdmi/ GND

File: hdmilight-v3-hdmi.sch
Id: 2/8 Title: HDMI Light V3 - HDMI Interface

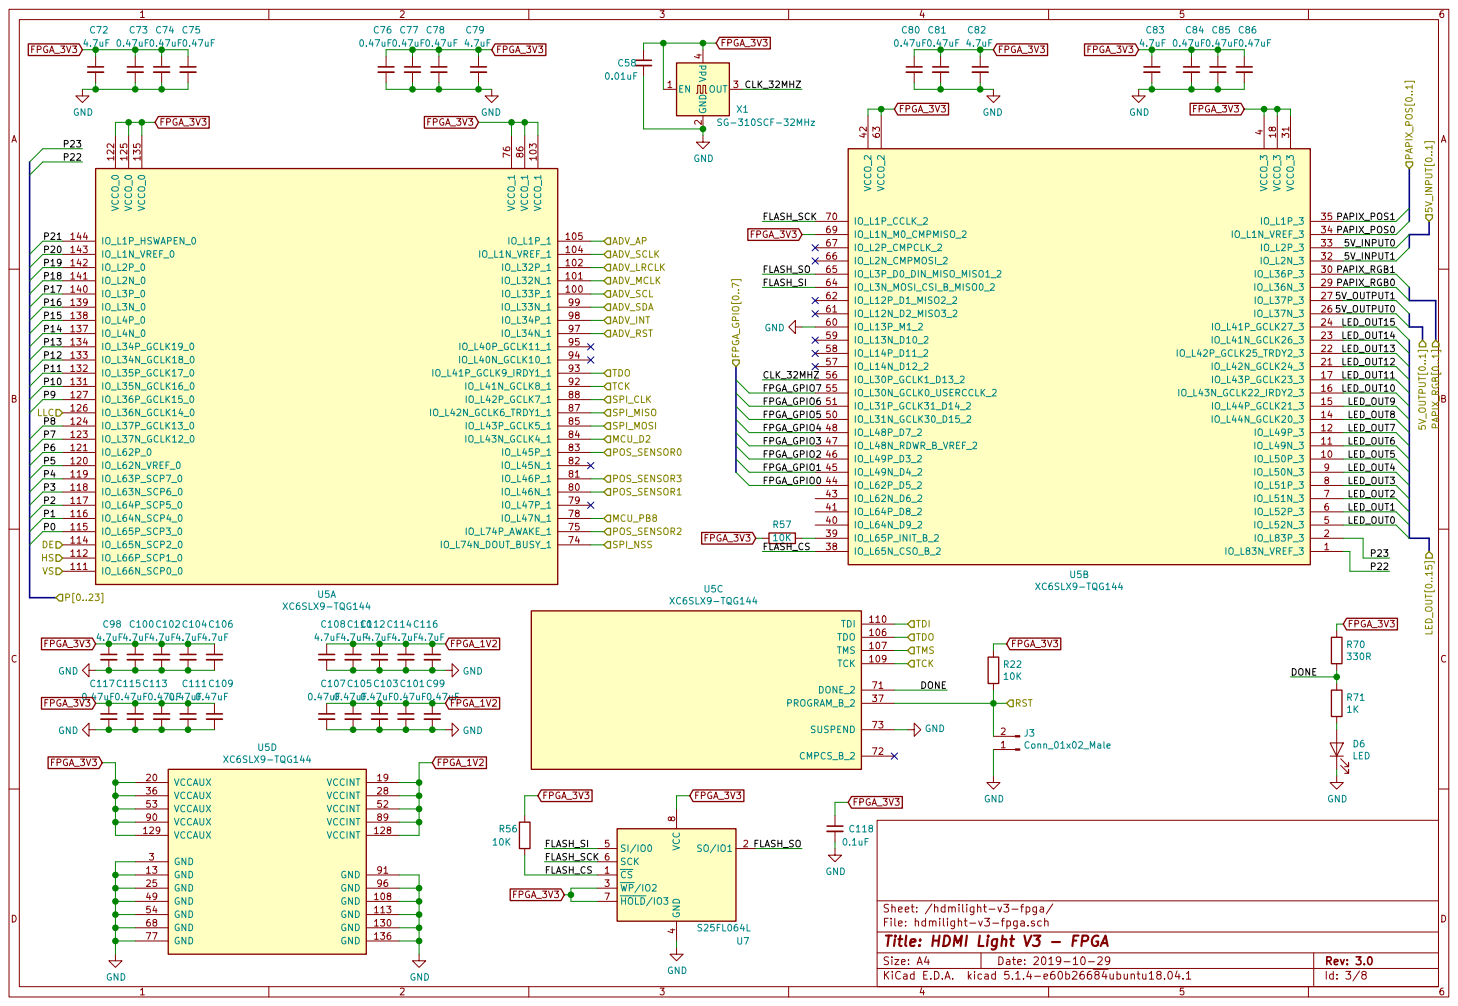
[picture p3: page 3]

4 SI/IO0 5 SCK 6 HOLD/IO3 7 VCC

Sheet: /hdmilight-v3-fpga/
File: hdmilight-v3-fpga.sch
Id: 3/8 Title: HDMI Light V3 - FPGA

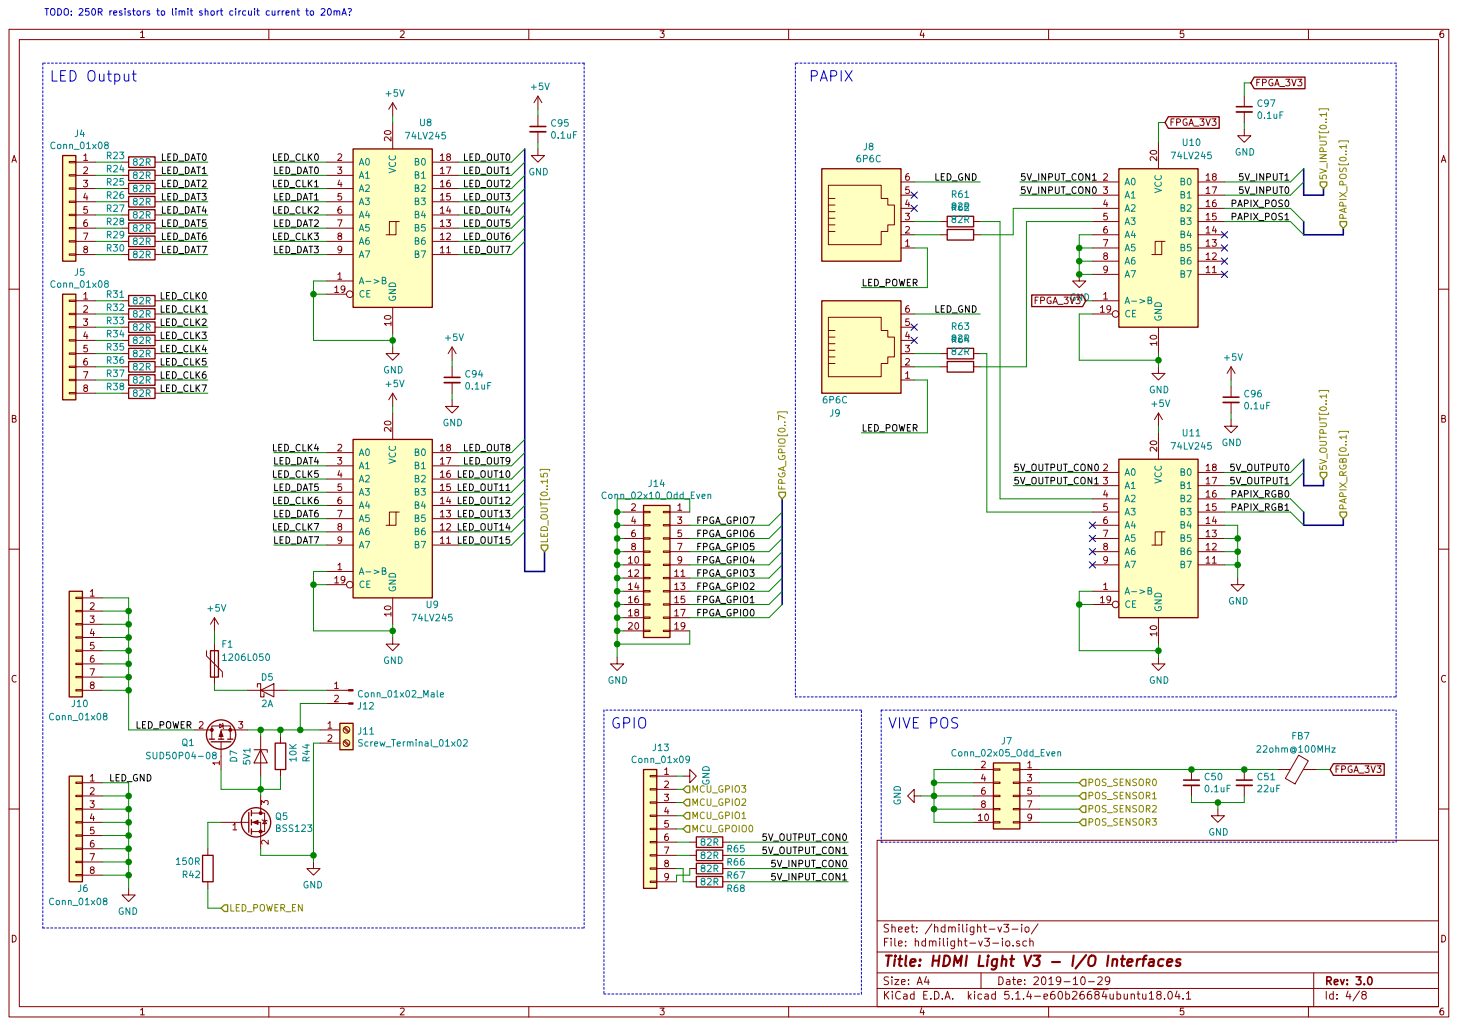
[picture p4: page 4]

TODO: 250R resistors to limit short circuit current to 20mA?

File: hdmilight-v3-io.sch
Id: 4/8 Title: HDMI Light V3 - I/O Interfaces

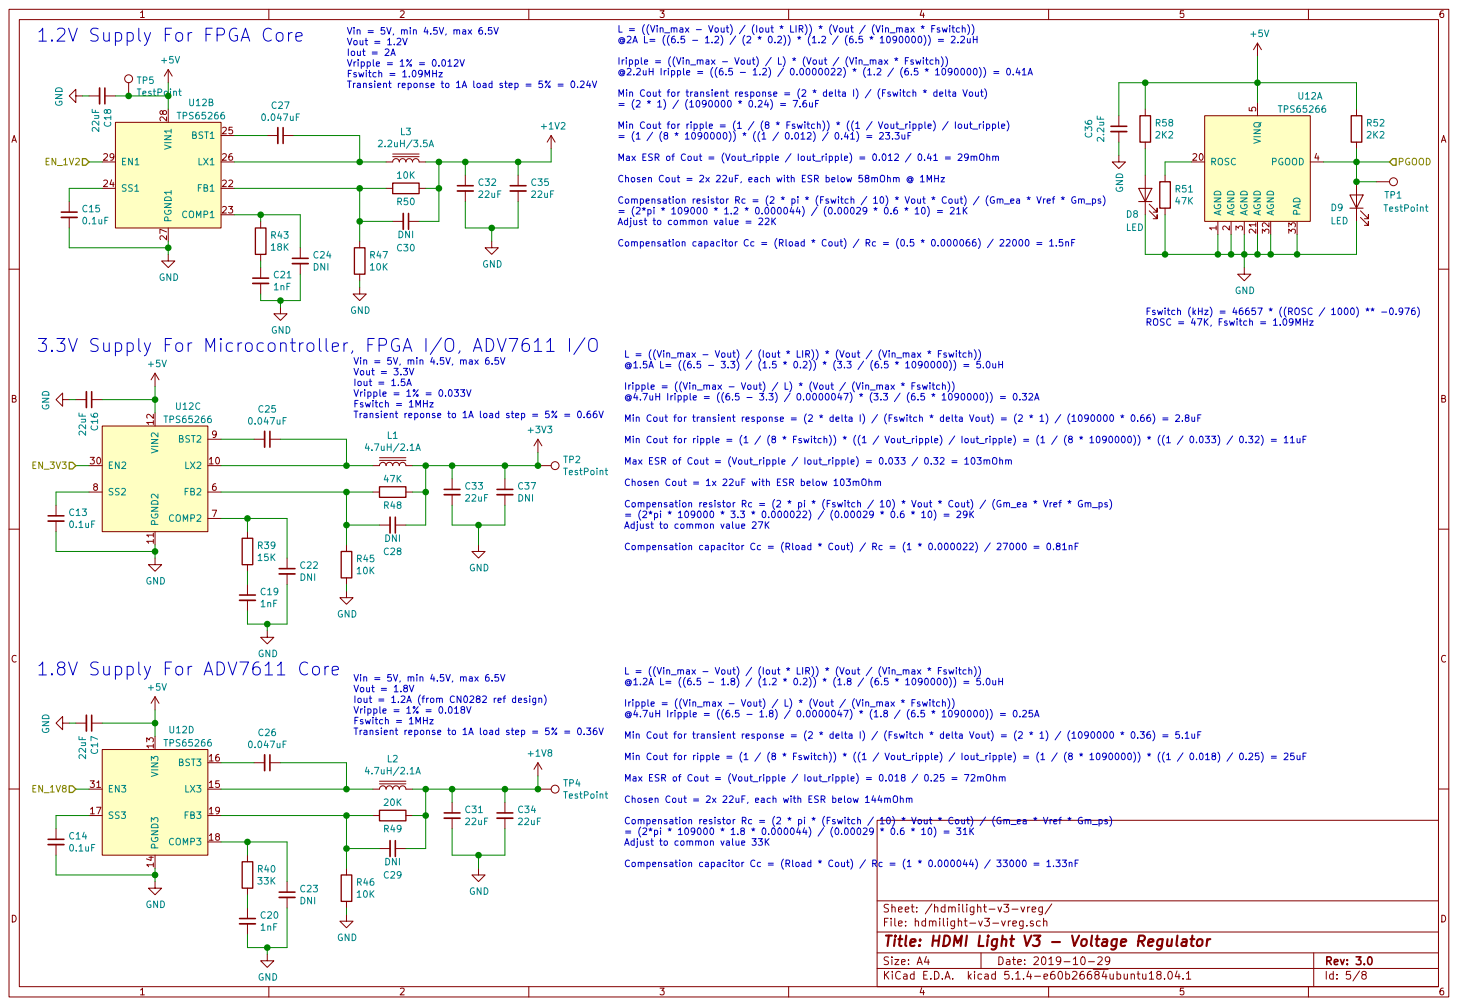
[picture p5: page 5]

1.2V Supply For FPGA Core

Vin = 5V, min 4.5V, max 6.5V
Vout = 1.2V
Iout = 2A
Vripple = 1% = 0.012V
Fswitch = 1.09MHz Transient reponse to 1A load step = 5% = 0.24V

L = ((Vin_max - Vout) / (Iout * LIR)) * (Vout / (Vin_max * Fswitch))

Iripple = ((Vin_max - Vout) / L) * (Vout / (Vin_max * Fswitch))
@2.2uH Iripple = ((6.5 - 1.2) / 0.0000022) * (1.2 / (6.5 * 1090000)) = 0.41A

Min Cout for transient response = (2 * delta I) / (Fswitch * delta Vout)

Min Cout for ripple = (1 / (8 * Fswitch)) * ((1 / Vout_ripple) / Iout_ripple)

3 AGND 32 PAD 33 PGOOD 4 VINQ

Max ESR of Cout = (Vout_ripple / Iout_ripple) = 0.012 / 0.41 = 29mOhm

Chosen Cout = 2x 22uF, each with ESR below 58mOhm @ 1MHz

Compensation resistor Rc = (2 * pi * (Fswitch / 10) * Vout * Cout) / (Gm_ea * Vref * Gm_ps)
Adjust to common value = 22K

Compensation capacitor Cc = (Rload * Cout) / Rc = (0.5 * 0.000066) / 22000 = 1.5nF

Fswitch (kHz) = 46657 * ((ROSC / 1000) ** -0.976) ROSC = 47K, Fswitch = 1.09MHz L = ((Vin_max - Vout) / (Iout * LIR)) * (Vout / (Vin_max * Fswitch))

3.3V Supply For Microcontroller, FPGA I/O, ADV7611 I/O

Compensation capacitor Cc = (Rload * Cout) / Rc = (1 * 0.000022) / 27000 = 0.81nF Vin = 5V, min 4.5V, max 6.5V
Vout = 3.3V
Iout = 1.5A
Vripple = 1% = 0.033V
Fswitch = 1MHz Transient reponse to 1A load step = 5% = 0.66V

@4.7uH Iripple = ((6.5 - 3.3) / 0.0000047) * (3.3 / (6.5 * 1090000)) = 0.32A

Min Cout for transient response = (2 * delta I) / (Fswitch * delta Vout) = (2 * 1) / (1090000 * 0.66) = 2.8uF

Min Cout for ripple = (1 / (8 * Fswitch)) * ((1 / Vout_ripple) / Iout_ripple) = (1 / (8 * 1090000)) * ((1 / 0.033) / 0.32) = 11uF

Max ESR of Cout = (Vout_ripple / Iout_ripple) = 0.033 / 0.32 = 103mOhm

Chosen Cout = 1x 22uF with ESR below 103mOhm

Adjust to common value 27K

Compensation capacitor Cc = (Rload * Cout) / Rc = (1 * 0.000044) / 33000 = 1.33nF Vin = 5V, min 4.5V, max 6.5V
Vout = 1.8V
Iout = 1.2A (from CN0282 ref design)
Vripple = 1% = 0.018V
Fswitch = 1MHz Transient reponse to 1A load step = 5% = 0.36V

@4.7uH Iripple = ((6.5 - 1.8) / 0.0000047) * (1.8 / (6.5 * 1090000)) = 0.25A

Min Cout for transient response = (2 * delta I) / (Fswitch * delta Vout) = (2 * 1) / (1090000 * 0.36) = 5.1uF

Min Cout for ripple = (1 / (8 * Fswitch)) * ((1 / Vout_ripple) / Iout_ripple) = (1 / (8 * 1090000)) * ((1 / 0.018) / 0.25) = 25uF

Max ESR of Cout = (Vout_ripple / Iout_ripple) = 0.018 / 0.25 = 72mOhm

Chosen Cout = 2x 22uF, each with ESR below 144mOhm

Adjust to common value 33K

File: hdmilight-v3-vreg.sch
Id: 5/8 Title: HDMI Light V3 - Voltage Regulator

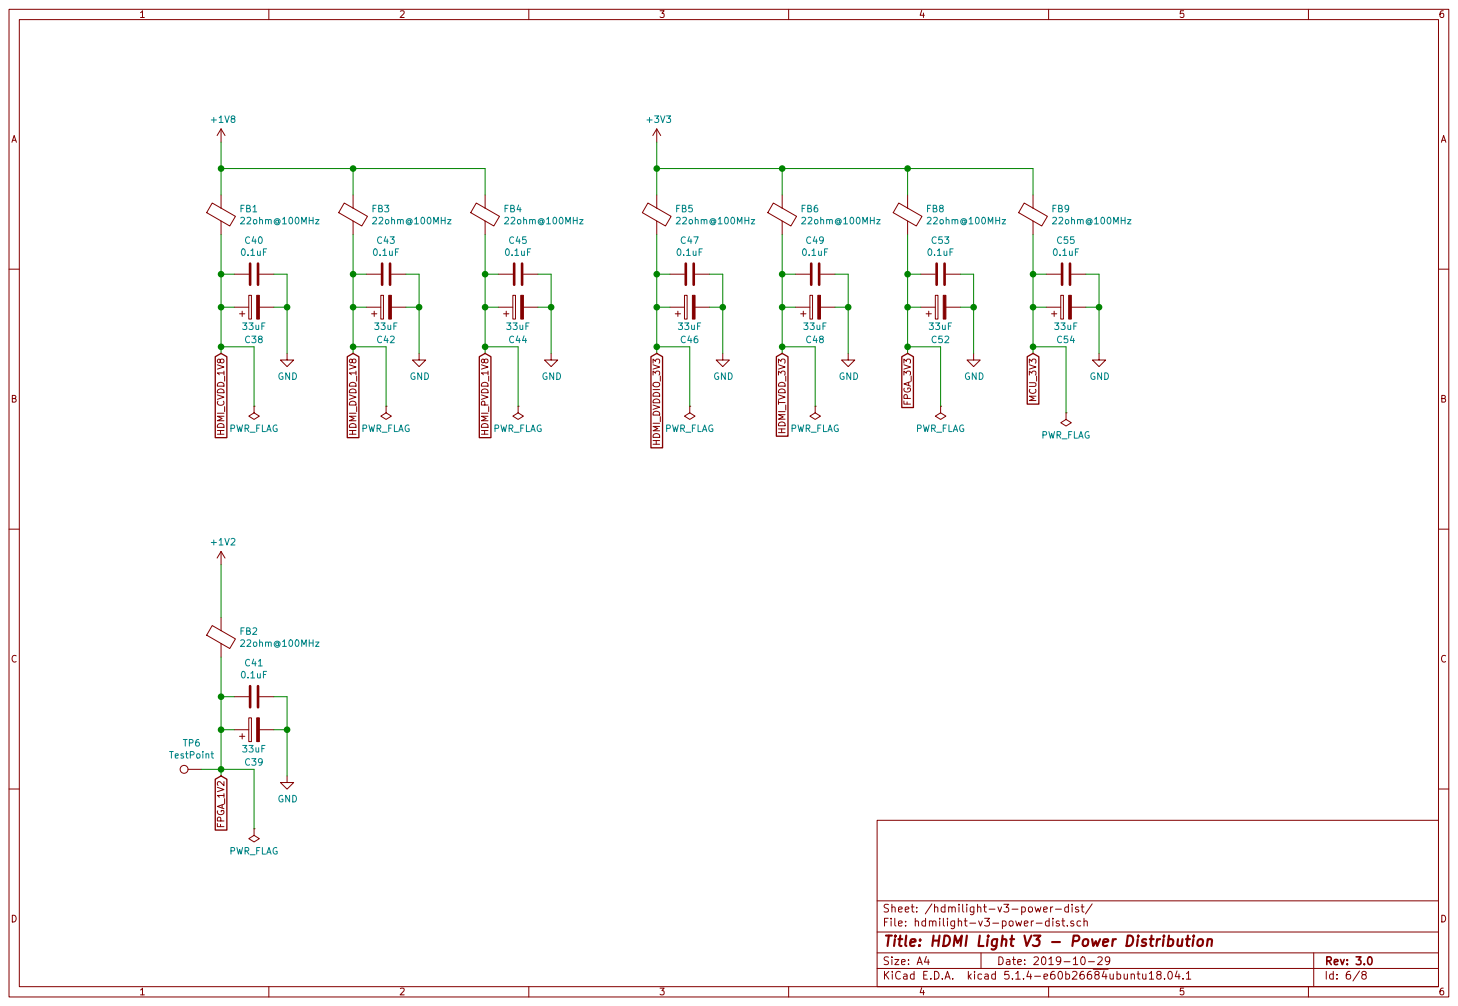
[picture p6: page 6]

Sheet: /hdmilight-v3-power-dist/
File: hdmilight-v3-power-dist.sch
Id: 6/8 Title: HDMI Light V3 - Power Distribution

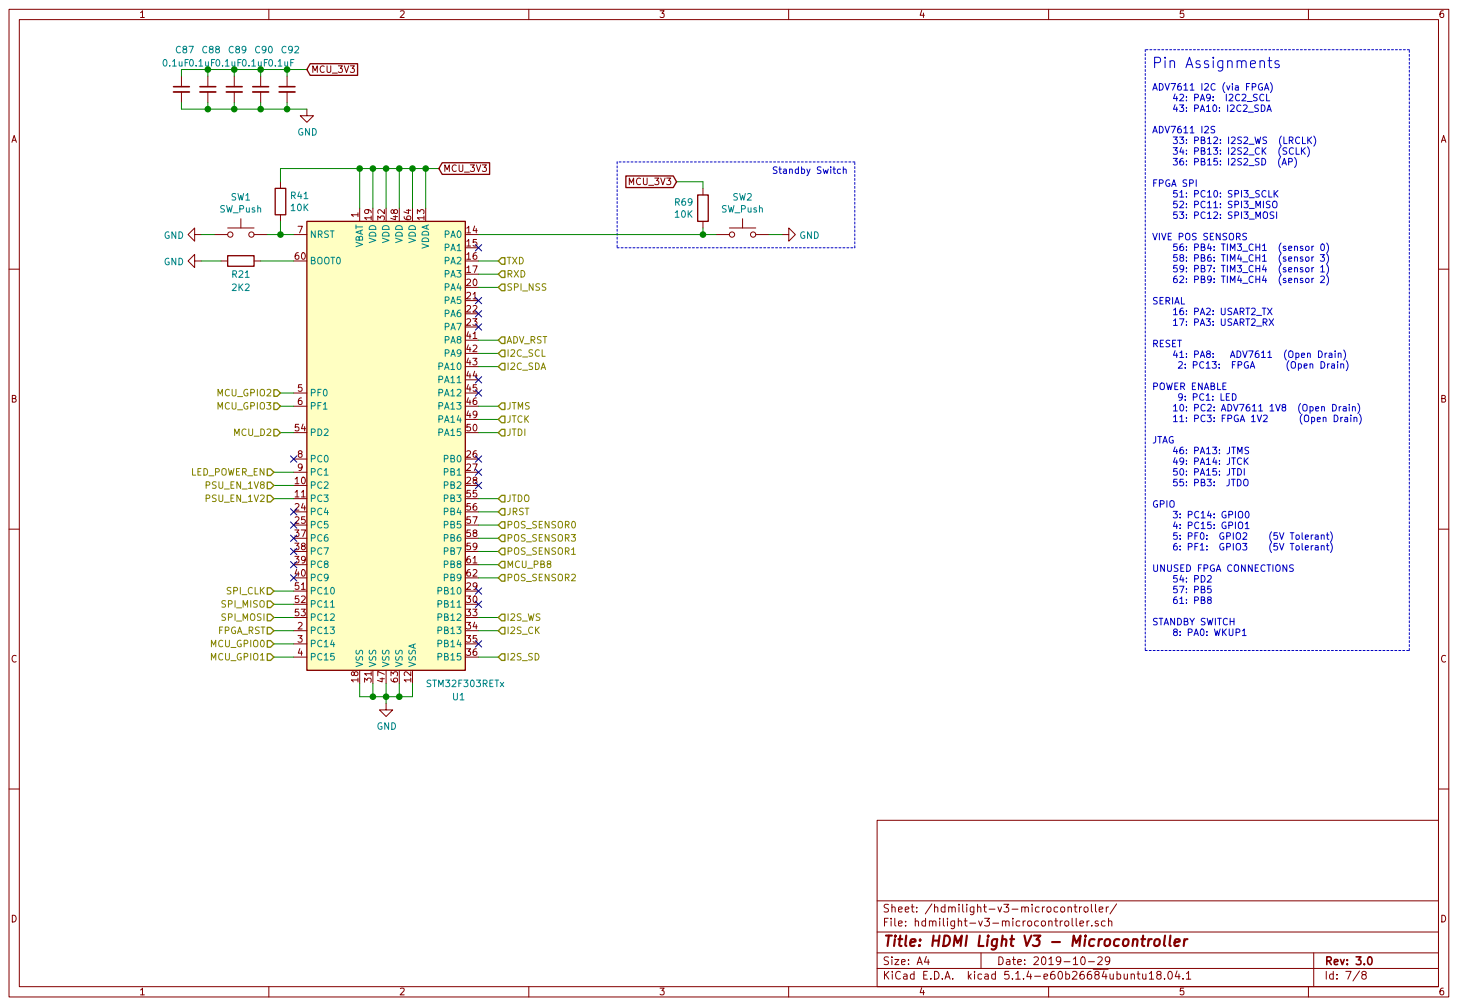
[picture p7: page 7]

1 VDD 19 VDD 32 VDD 48 VDD 64 VDDA 13 VSS 18 VSS 31 VSS 47 VSS 63 VSSA 12 U1 STM32F303RETx R21

Sheet: /hdmilight-v3-microcontroller/ GND

File: hdmilight-v3-microcontroller.sch
Id: 7/8 Title: HDMI Light V3 - Microcontroller

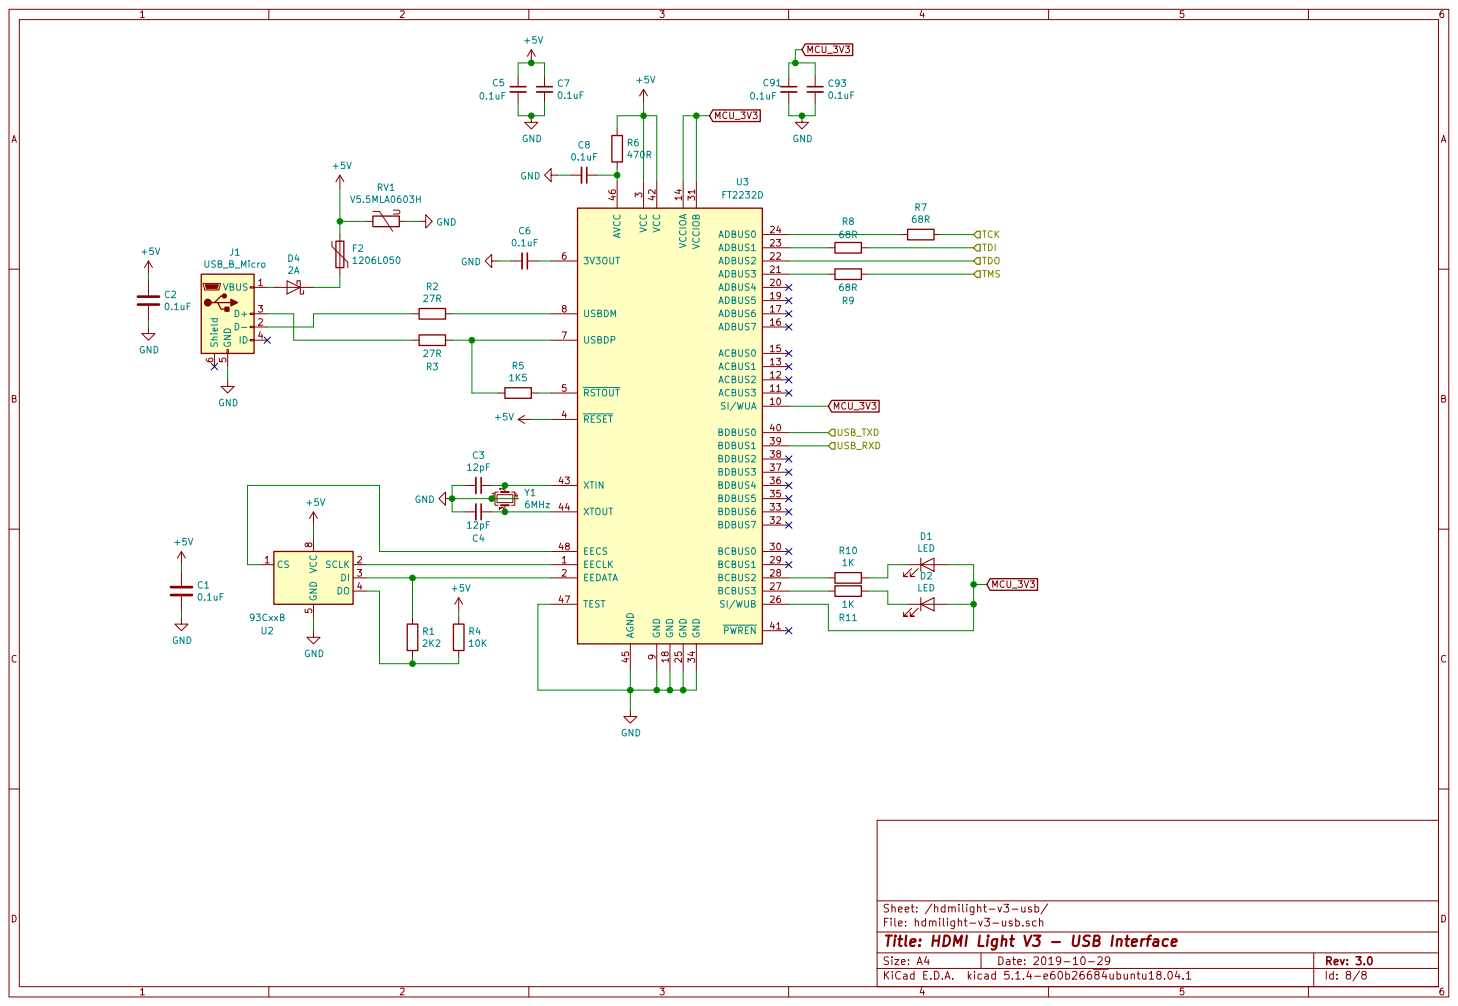
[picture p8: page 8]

3 BCBUS0 30 VCCIOB 31 BDBUS7 32 BDBUS6 33 GND 34 BDBUS5 35 BDBUS4 36 BDBUS3 37 BDBUS2 38 BDBUS1 39 RESET 4 BDBUS0 40 PWREN 41 VCC 42 XTIN 43 XTOUT 44 AGND 45 AVCC 46 TEST 47 EECS 48 RSTOUT 5

Sheet: /hdmilight-v3-usb/
File: hdmilight-v3-usb.sch
Id: 8/8 Title: HDMI Light V3 - USB Interface

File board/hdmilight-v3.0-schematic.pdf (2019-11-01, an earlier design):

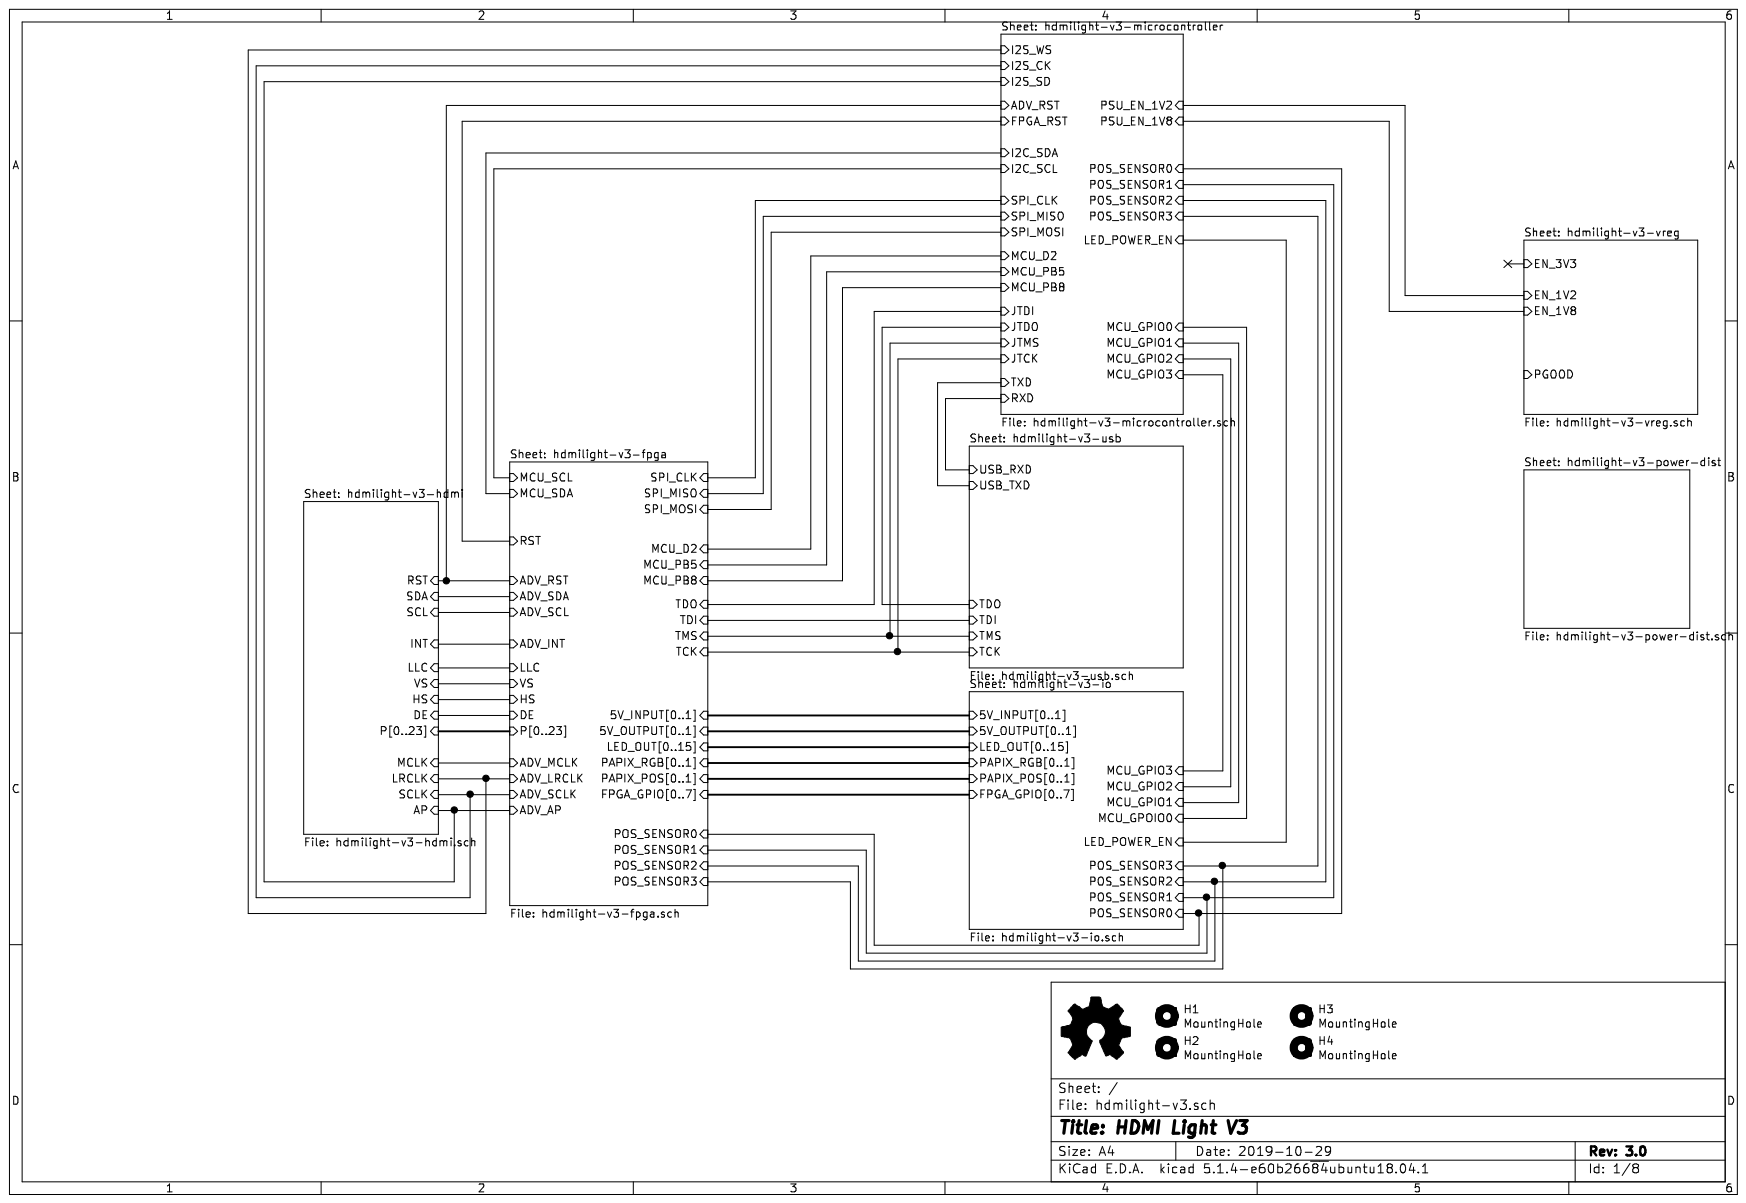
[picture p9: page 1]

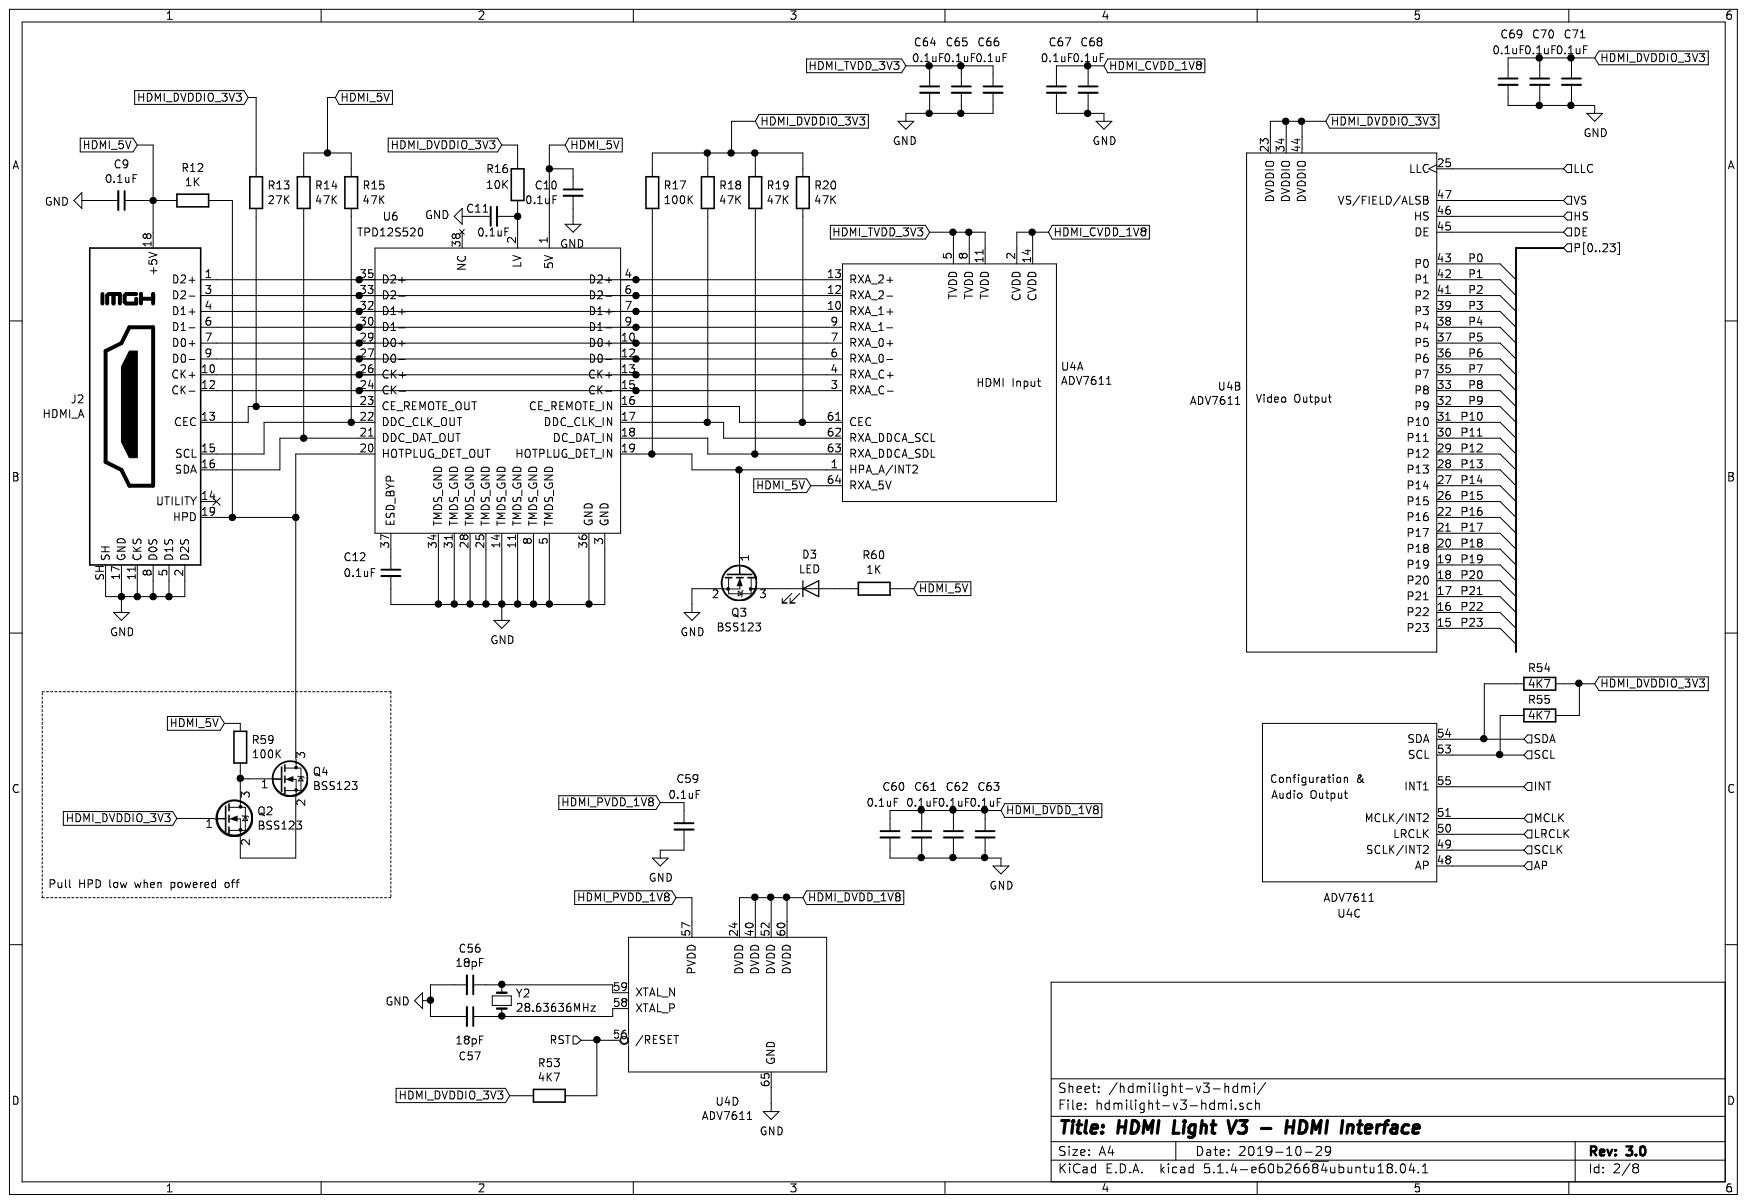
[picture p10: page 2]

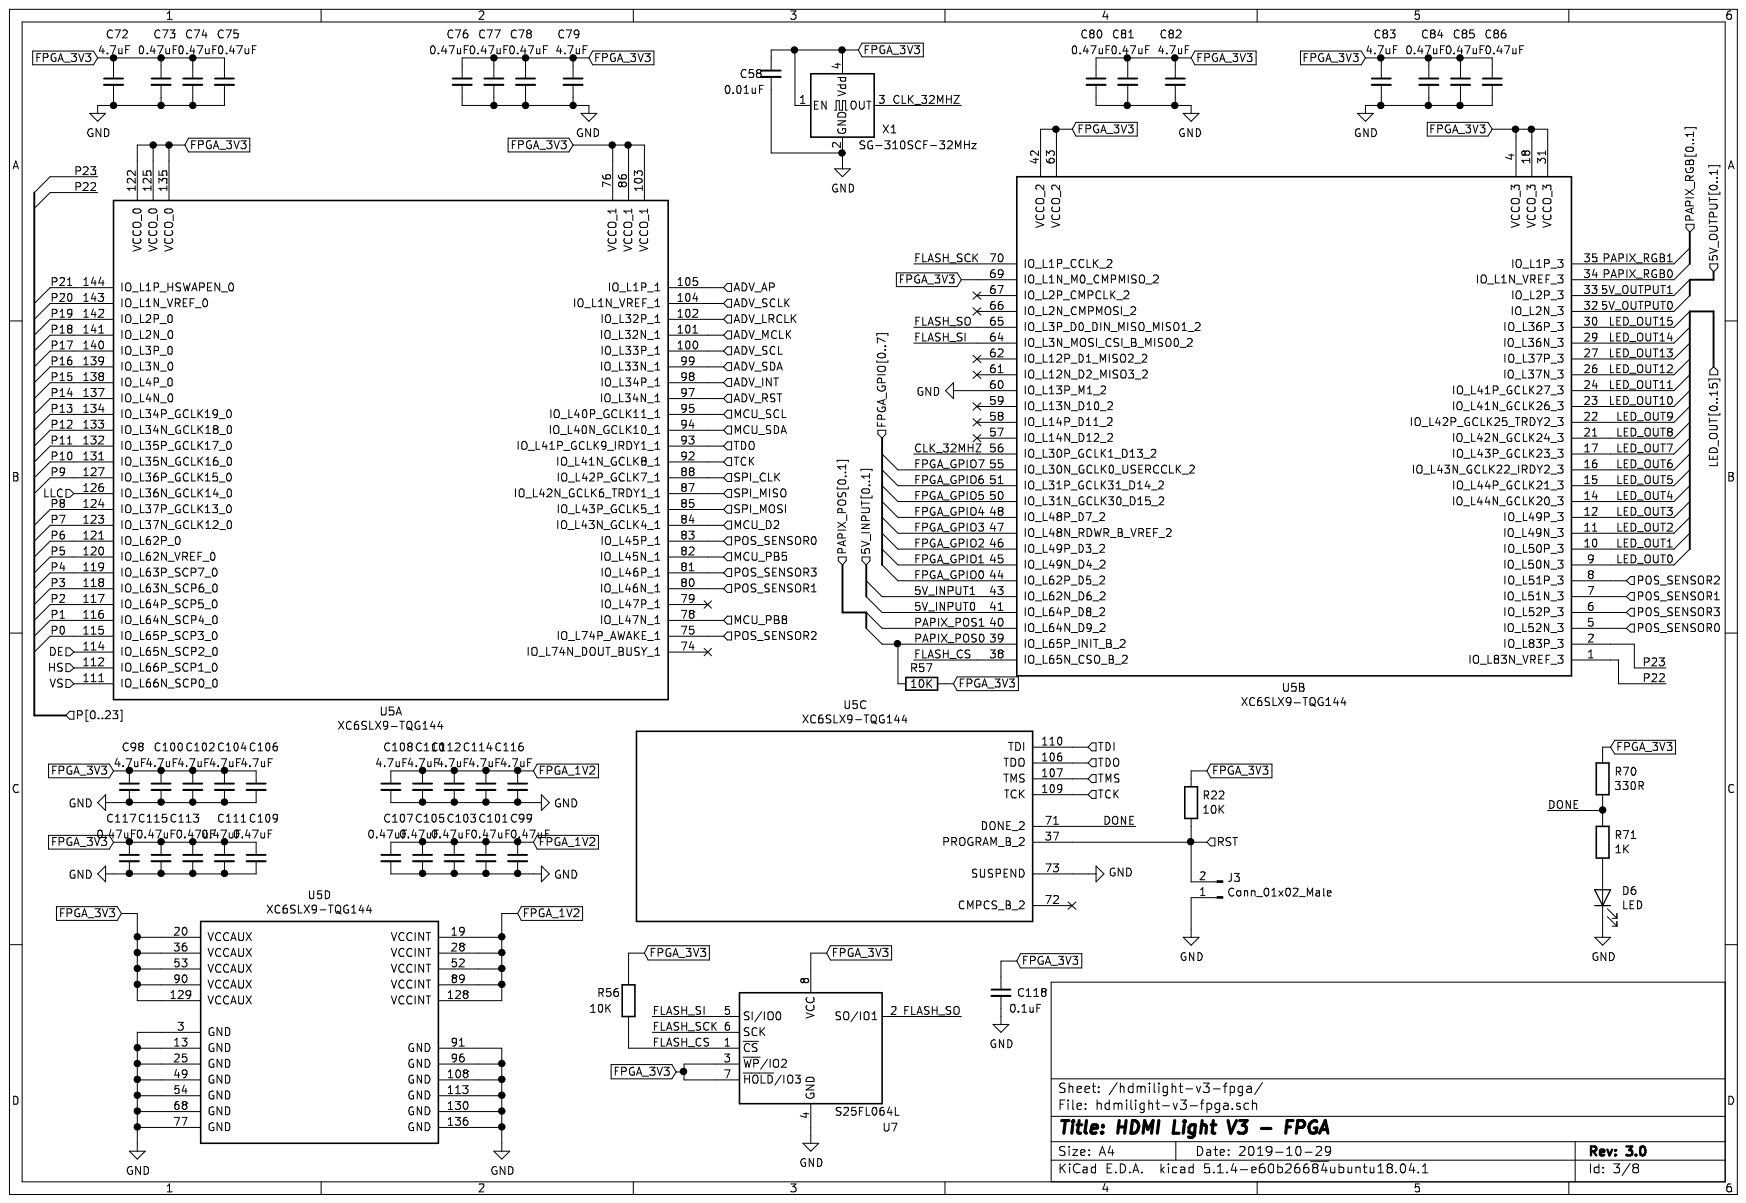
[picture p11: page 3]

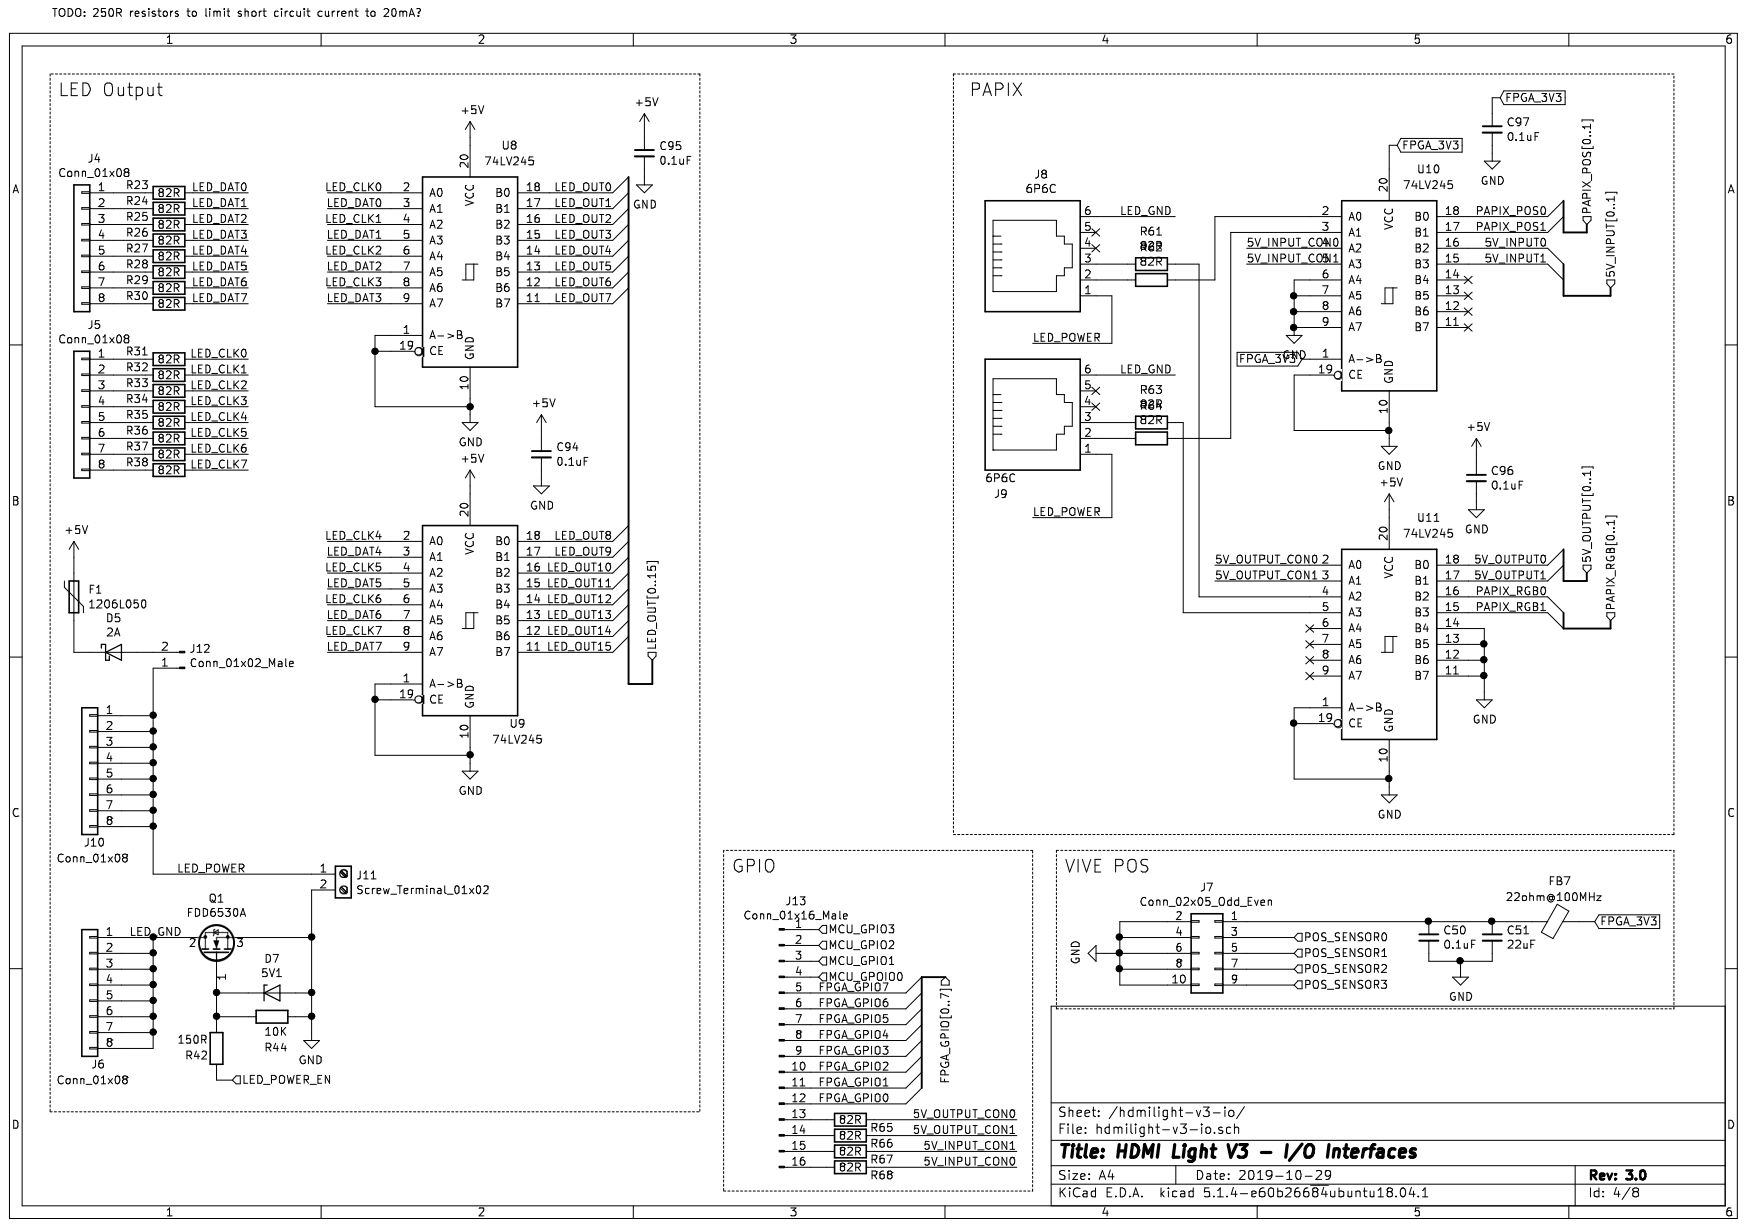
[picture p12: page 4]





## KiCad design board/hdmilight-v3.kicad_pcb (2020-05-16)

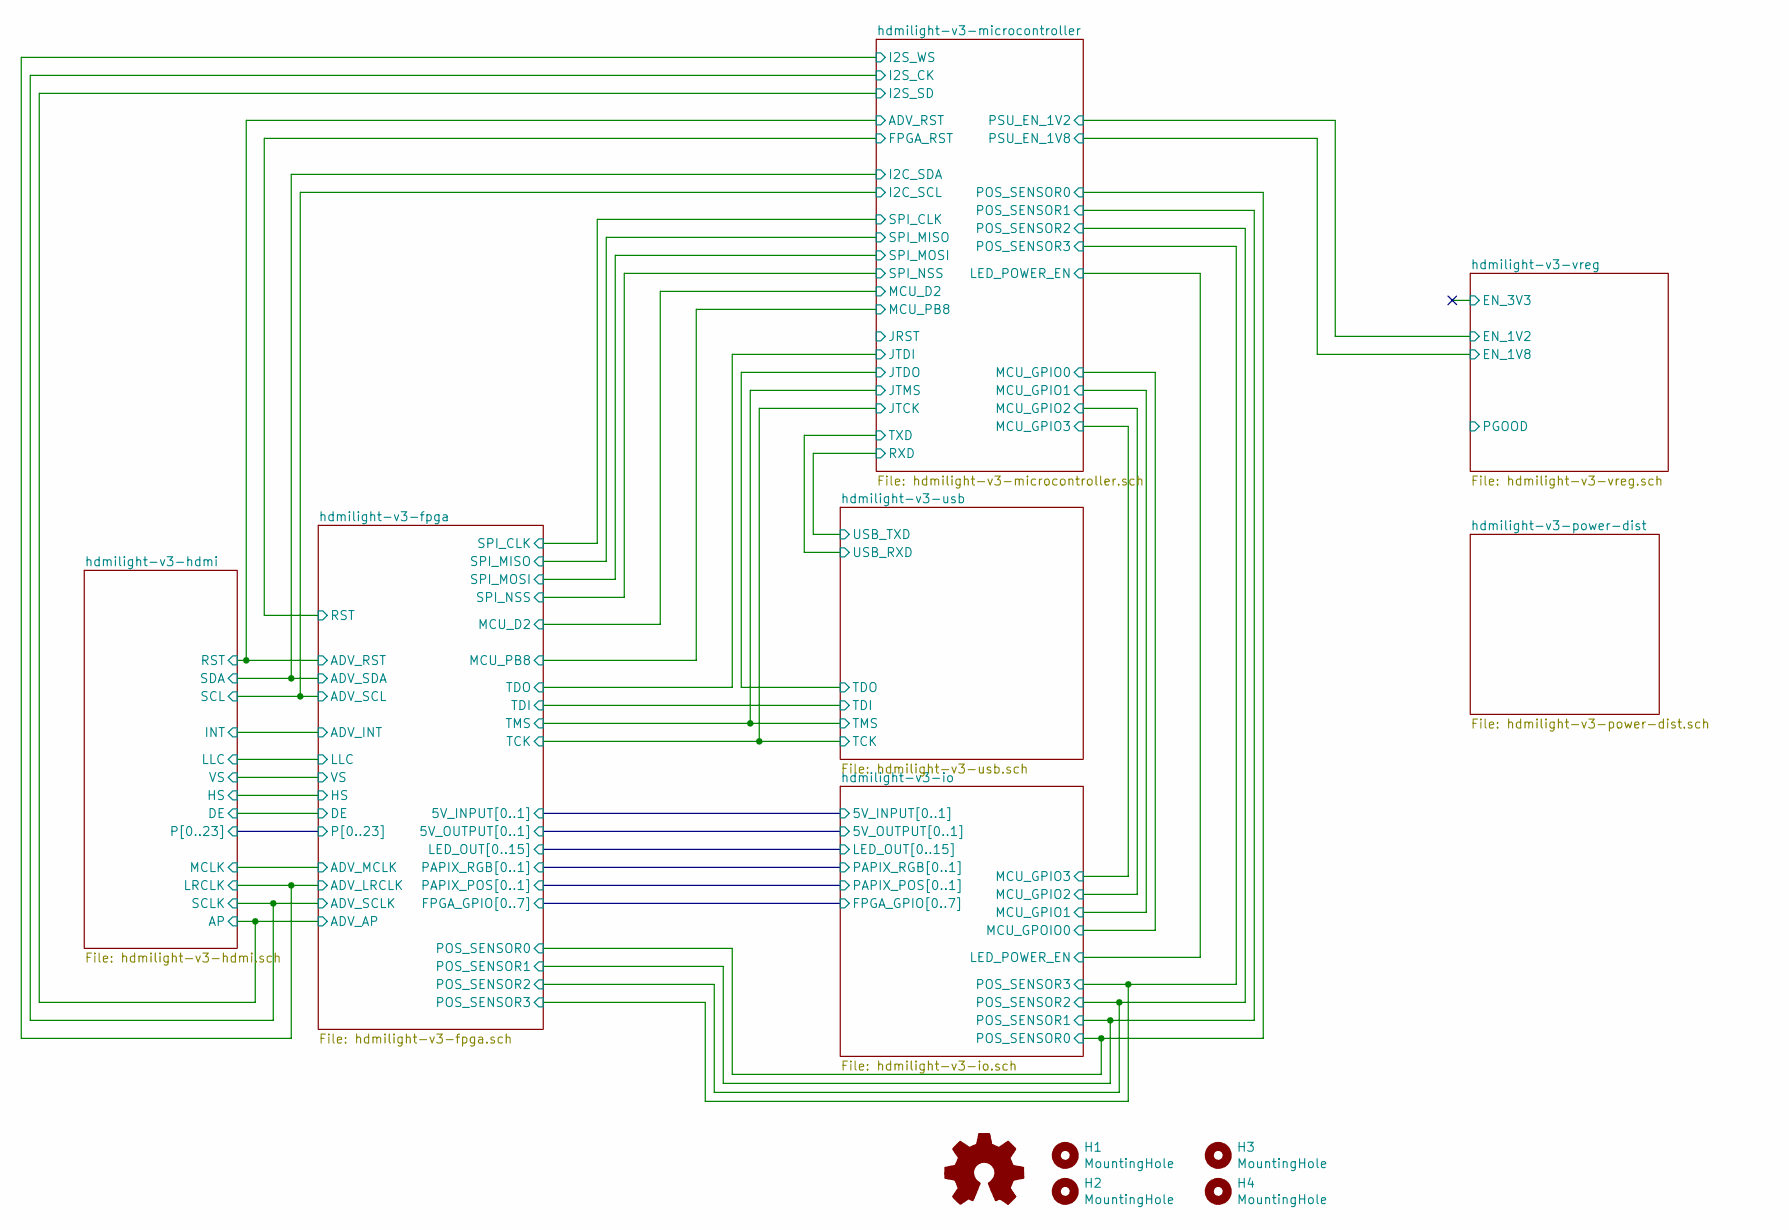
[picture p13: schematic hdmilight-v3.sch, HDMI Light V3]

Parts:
H1, H2, H3, H4: MountingHole; MountingHole_3.2mm_M3
LOGO1: Logo_Open_Hardware_Small; OSHW-Logo2_9.8x8mm_SilkScreen

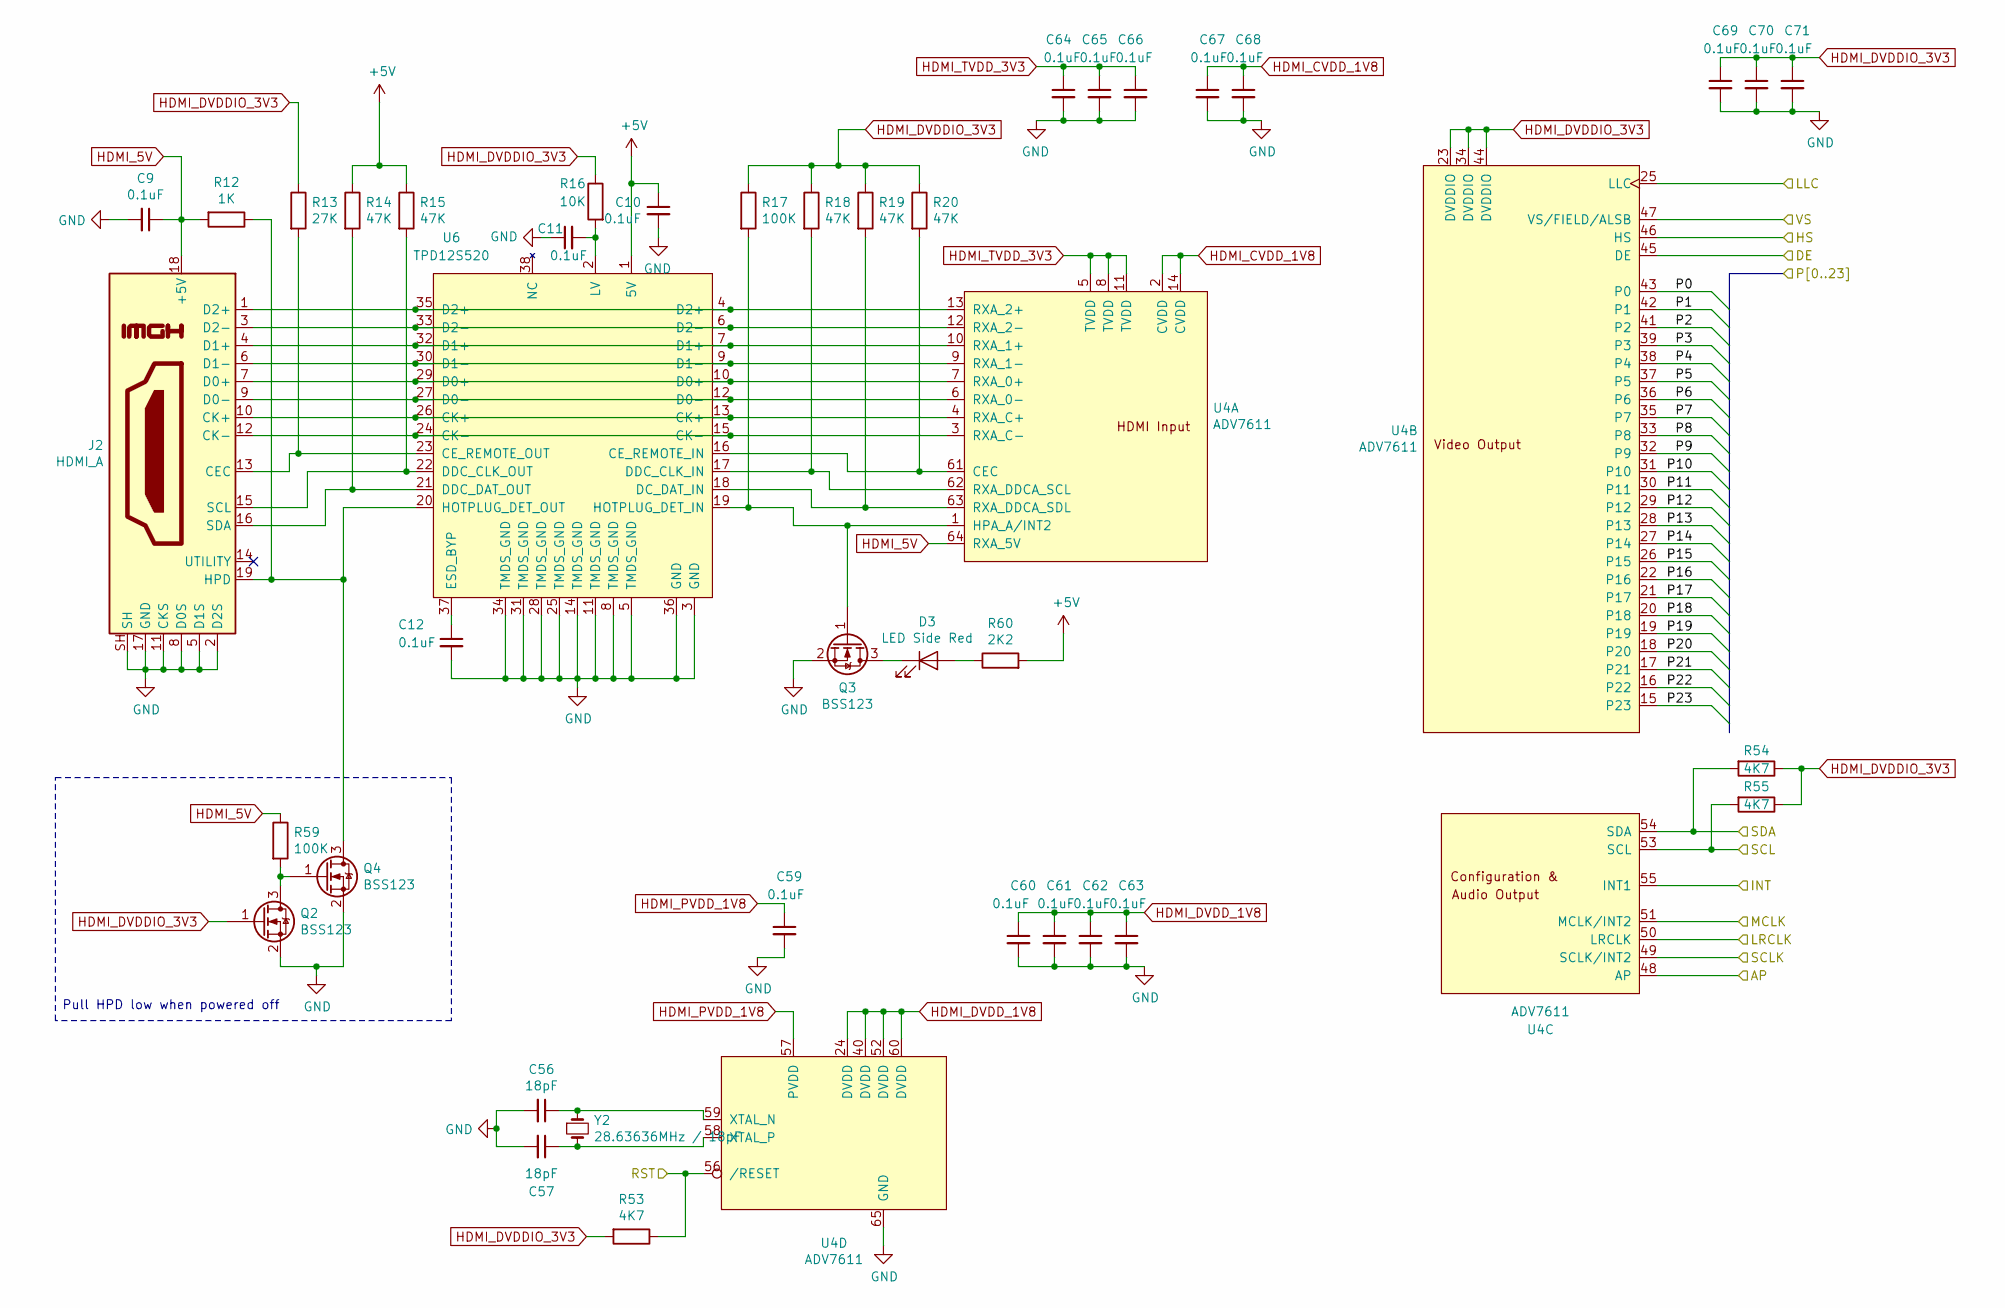
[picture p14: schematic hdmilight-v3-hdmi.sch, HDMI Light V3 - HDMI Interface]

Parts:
C9, C59, C60, C61, C62, C63, C64, C65, C66, C67, C68, C69, C70, C71: 0.1uF; C_0402_1005Metric
C10, C11, C12: 0.1uF; C_0603_1608Metric
C56, C57: 18pF; C_0603_1608Metric
D3: LED Side Red; LED_0603_1608Metric
J2: HDMI_A; HDMI_SOCKET_FCI_10029449
Q2, Q3, Q4: BSS123; SOT-23
R12: 1K; R_0603_1608Metric
R13: 27K; R_0603_1608Metric
R14, R15, R18, R19, R20: 47K; R_0603_1608Metric
R16: 10K; R_0603_1608Metric
R17, R59: 100K; R_0603_1608Metric
R53, R54, R55: 4K7; R_0603_1608Metric
R60: 2K2; R_0603_1608Metric
U4: ADV7611; LQFP-64-1EP_10x10mm_P0.5mm_EP6.5x6.5mm_ThermalVias
U6: TPD12S520; TSSOP-38_4.4x9.7mm_P0.5mm
Y2: 28.63636MHz / 18pF; Crystal_SMD_5032-2Pin_5.0x3.2mm

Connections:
+5V: C10.1, R14.1, R15.1, R60.2, U6.1 (5V); also elsewhere on the board
/hdmilight-v3-fpga/ADV_AP: U4.48 (AP); also elsewhere on the board
/hdmilight-v3-fpga/ADV_INT: U4.55 (INT1); also elsewhere on the board
/hdmilight-v3-fpga/ADV_LRCLK: U4.50 (LRCLK); also elsewhere on the board
/hdmilight-v3-fpga/ADV_MCLK: U4.51 (MCLK/INT2); also elsewhere on the board
/hdmilight-v3-fpga/ADV_RST: R53.1, U4.56 (/RESET); also elsewhere on the board
/hdmilight-v3-fpga/ADV_SCL: R55.2, U4.53 (SCL); also elsewhere on the board
/hdmilight-v3-fpga/ADV_SCLK: U4.49 (SCLK/INT2); also elsewhere on the board
/hdmilight-v3-fpga/ADV_SDA: R54.2, U4.54 (SDA); also elsewhere on the board
/hdmilight-v3-fpga/DE: U4.45 (DE); also elsewhere on the board
/hdmilight-v3-fpga/HS: U4.46 (HS); also elsewhere on the board
/hdmilight-v3-fpga/LLC: U4.25 (LLC); also elsewhere on the board
/hdmilight-v3-fpga/P0: U4.43 (P0); also elsewhere on the board
/hdmilight-v3-fpga/P1: U4.42 (P1); also elsewhere on the board
/hdmilight-v3-fpga/P2: U4.41 (P2); also elsewhere on the board
/hdmilight-v3-fpga/P3: U4.39 (P3); also elsewhere on the board
/hdmilight-v3-fpga/P4: U4.38 (P4); also elsewhere on the board
/hdmilight-v3-fpga/P5: U4.37 (P5); also elsewhere on the board
/hdmilight-v3-fpga/P6: U4.36 (P6); also elsewhere on the board
/hdmilight-v3-fpga/P7: U4.35 (P7); also elsewhere on the board
/hdmilight-v3-fpga/P8: U4.33 (P8); also elsewhere on the board
/hdmilight-v3-fpga/P9: U4.32 (P9); also elsewhere on the board
/hdmilight-v3-fpga/P10: U4.31 (P10); also elsewhere on the board
/hdmilight-v3-fpga/P11: U4.30 (P11); also elsewhere on the board
/hdmilight-v3-fpga/P12: U4.29 (P12); also elsewhere on the board
/hdmilight-v3-fpga/P13: U4.28 (P13); also elsewhere on the board
/hdmilight-v3-fpga/P14: U4.27 (P14); also elsewhere on the board
/hdmilight-v3-fpga/P15: U4.26 (P15); also elsewhere on the board
/hdmilight-v3-fpga/P16: U4.22 (P16); also elsewhere on the board
/hdmilight-v3-fpga/P17: U4.21 (P17); also elsewhere on the board
/hdmilight-v3-fpga/P18: U4.20 (P18); also elsewhere on the board
/hdmilight-v3-fpga/P19: U4.19; also elsewhere on the board
/hdmilight-v3-fpga/P20: U4.18 (P20); also elsewhere on the board
/hdmilight-v3-fpga/P21: U4.17 (P21); also elsewhere on the board
/hdmilight-v3-fpga/P22: U4.16 (P22); also elsewhere on the board
/hdmilight-v3-fpga/P23: U4.15 (P23); also elsewhere on the board
/hdmilight-v3-fpga/VS: U4.47 (VS/FIELD/ALSB); also elsewhere on the board
GND: C9.2, C10.2, C11.1, C12.2, C56.2, C57.2, C59.2, C60.2, C61.2, C62.2, C63.2, C64.2, C65.2, C66.2, C67.2, C68.2, C69.2, C70.2, C71.2, J2.2 (D2S), J2.5 (D1S), J2.8 (D0S), J2.11 (CKS), J2.17 (GND), J2.SH, Q2.2 (S), Q3.2 (S), Q4.2 (S), U4.65 (GND), U6.3 (GND), U6.5 (TMDS_GND), U6.8 (TMDS_GND), U6.11 (TMDS_GND), U6.14 (TMDS_GND), U6.25 (TMDS_GND), U6.28 (TMDS_GND), U6.31 (TMDS_GND), U6.34 (TMDS_GND), U6.36 (GND); also elsewhere on the board
HDMI_5V: C9.1, J2.18 (+5V), R12.2, R59.1, U4.64 (RXA_5V)
HDMI_CVDD_1V8: C67.1, C68.1, U4.2 (CVDD), U4.14 (CVDD); also elsewhere on the board
HDMI_DVDDIO_3V3: C69.1, C70.1, C71.1, Q2.1 (G), R13.1, R16.1, R17.1, R18.1, R19.1, R20.1, R53.2, R54.1, R55.1, U4.23 (DVDDIO), U4.34 (DVDDIO), U4.44 (DVDDIO); also elsewhere on the board
HDMI_DVDD_1V8: C60.1, C61.1, C62.1, C63.1, U4.24 (DVDD), U4.40 (DVDD), U4.52 (DVDD), U4.60 (DVDD); also elsewhere on the board
HDMI_PVDD_1V8: C59.1, U4.57 (PVDD); also elsewhere on the board
HDMI_TVDD_3V3: C64.1, C65.1, C66.1, U4.5 (TVDD), U4.8 (TVDD), U4.11 (TVDD); also elsewhere on the board
unnamed: C11.2, R16.2, U6.2 (LV)
unnamed: C12.1, U6.37 (ESD_BYP)
unnamed: C56.1, U4.59 (XTAL_N), Y2.1
unnamed: C57.1, U4.58 (XTAL_P), Y2.2
unnamed: D3.1 (K), Q3.3 (D)
unnamed: D3.2 (A), R60.1
unnamed: J2.1 (D2+), U4.13 (RXA_2+), U6.4 (D2+), U6.35 (D2+)
unnamed: J2.3 (D2-), U4.12 (RXA_2-), U6.6 (D2-), U6.33 (D2-)
unnamed: J2.4 (D1+), U4.10 (RXA_1+), U6.7 (D1+), U6.32 (D1+)
unnamed: J2.6 (D1-), U4.9 (RXA_1-), U6.9 (D1-), U6.30 (D1-)
unnamed: J2.7 (D0+), U4.7 (RXA_0+), U6.10 (D0+), U6.29 (D0+)
unnamed: J2.9 (D0-), U4.6 (RXA_0-), U6.12 (D0-), U6.27 (D0-)
unnamed: J2.10 (CK+), U4.4 (RXA_C+), U6.13 (CK+), U6.26 (CK+)
unnamed: J2.12 (CK-), U4.3 (RXA_C-), U6.15 (CK-), U6.24 (CK-)
unnamed: J2.13 (CEC), R13.2, U6.23 (CE_REMOTE_OUT)
unnamed: J2.15 (SCL), R15.2, U6.22 (DDC_CLK_OUT)
unnamed: J2.16 (SDA), R14.2, U6.21 (DDC_DAT_OUT)
unnamed: J2.19 (HPD), Q4.3 (D), R12.1, U6.20 (HOTPLUG_DET_OUT)
unnamed: Q2.3 (D), Q4.1 (G), R59.2
unnamed: Q3.1 (G), R17.2, U4.1 (HPA_A/INT2), U6.19 (HOTPLUG_DET_IN)
unnamed: R18.2, U4.62 (RXA_DDCA_SCL), U6.17 (DDC_CLK_IN)
unnamed: R19.2, U4.63 (RXA_DDCA_SDL), U6.18 (DC_DAT_IN)
unnamed: R20.2, U4.61 (CEC), U6.16 (CE_REMOTE_IN)

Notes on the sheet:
Pull HPD low when powered off

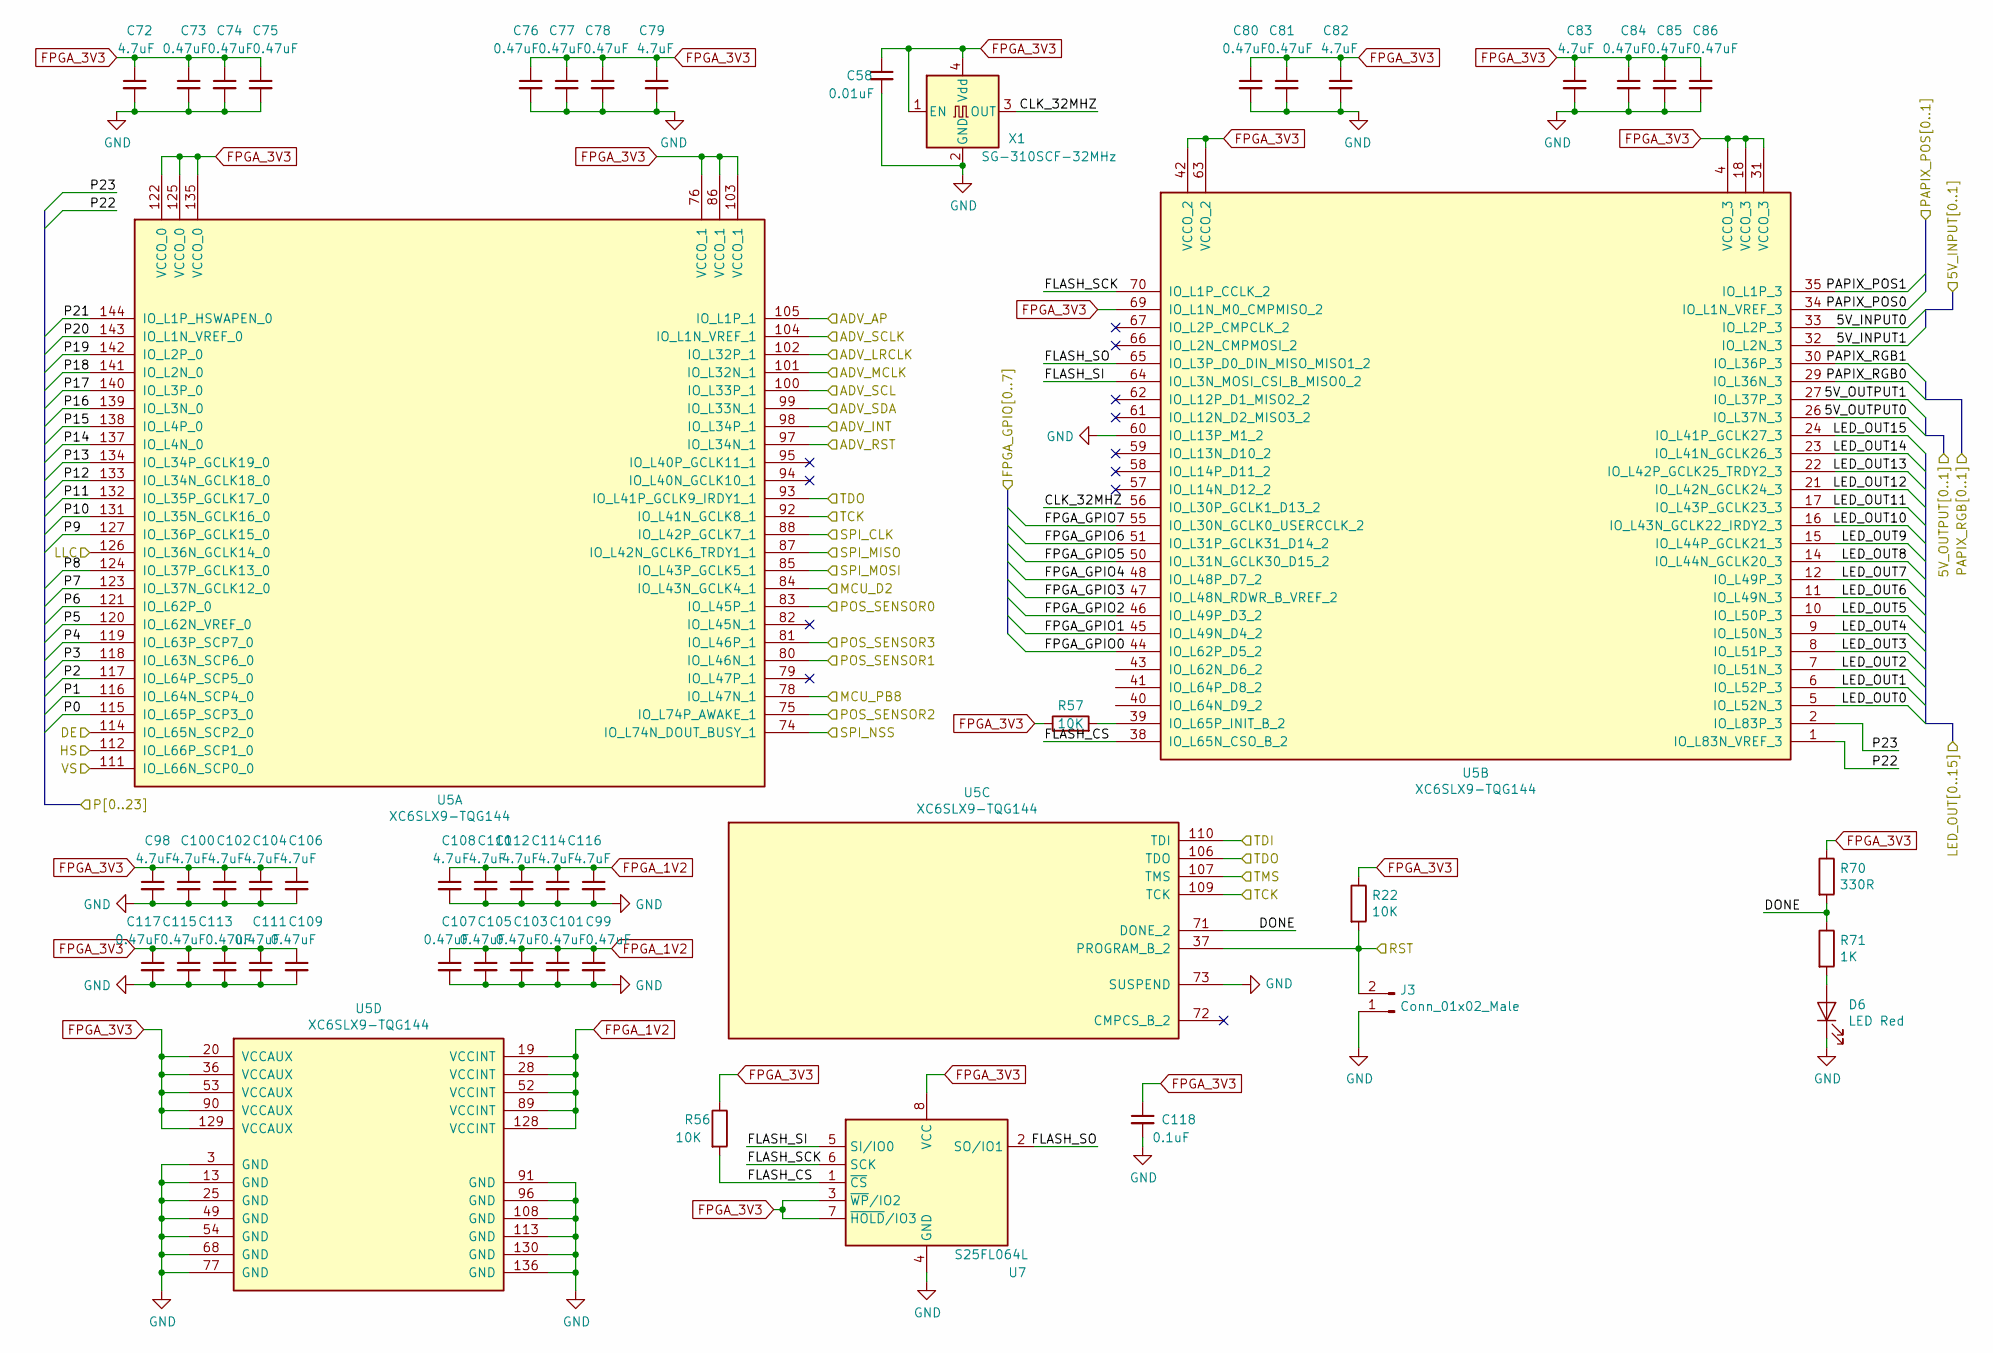
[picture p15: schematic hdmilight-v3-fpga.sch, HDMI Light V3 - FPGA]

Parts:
C58: 0.01uF; C_0603_1608Metric
C72, C79, C82, C83, C98, C100, C102, C104, C106, C108, C110, C112, C114, C116: 4.7uF; C_0805_2012Metric
C73, C74, C75, C76, C77, C78, C80, C81, C84, C85, C86, C99, C101, C103, C105, C107, C109, C111, C113, C115, C117: 0.47uF; C_0402_1005Metric
C118: 0.1uF; C_0402_1005Metric
D6: LED Red; LED_0603_1608Metric
J3: Conn_01x02_Male; PinHeader_1x02_P2.54mm_Vertical
R22, R56, R57: 10K; R_0603_1608Metric
R70: 330R; R_0603_1608Metric
R71: 1K; R_0603_1608Metric
U5: XC6SLX9-TQG144; TQFP-144_20x20mm_P0.5mm
U7: S25FL064L; SOIC-8_5.23x5.23mm_P1.27mm
X1: SG-310SCF-32MHz; Oscillator_SMD_Abracon_ASE-4Pin_3.2x2.5mm

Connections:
/hdmilight-v3-fpga/5V_INPUT0: U5.33 (IO_L2P_3); also elsewhere on the board
/hdmilight-v3-fpga/5V_INPUT1: U5.32 (IO_L2N_3); also elsewhere on the board
/hdmilight-v3-fpga/5V_OUTPUT0: U5.26 (IO_L37N_3); also elsewhere on the board
/hdmilight-v3-fpga/5V_OUTPUT1: U5.27 (IO_L37P_3); also elsewhere on the board
/hdmilight-v3-fpga/ADV_AP: U5.105 (IO_L1P_1); also elsewhere on the board
/hdmilight-v3-fpga/ADV_INT: U5.98 (IO_L34P_1); also elsewhere on the board
/hdmilight-v3-fpga/ADV_LRCLK: U5.102 (IO_L32P_1); also elsewhere on the board
/hdmilight-v3-fpga/ADV_MCLK: U5.101 (IO_L32N_1); also elsewhere on the board
/hdmilight-v3-fpga/ADV_RST: U5.97 (IO_L34N_1); also elsewhere on the board
/hdmilight-v3-fpga/ADV_SCL: U5.100 (IO_L33P_1); also elsewhere on the board
/hdmilight-v3-fpga/ADV_SCLK: U5.104 (IO_L1N_VREF_1); also elsewhere on the board
/hdmilight-v3-fpga/ADV_SDA: U5.99 (IO_L33N_1); also elsewhere on the board
/hdmilight-v3-fpga/CLK_32MHZ: U5.56 (IO_L30P_GCLK1_D13_2), X1.3 (OUT)
/hdmilight-v3-fpga/DE: U5.114 (IO_L65N_SCP2_0); also elsewhere on the board
/hdmilight-v3-fpga/DONE: R70.2, R71.1, U5.71 (DONE_2)
/hdmilight-v3-fpga/FLASH_CS: R56.2, U5.38 (IO_L65N_CSO_B_2), U7.1 (~CS)
/hdmilight-v3-fpga/FLASH_SCK: U5.70 (IO_L1P_CCLK_2), U7.6 (SCK)
/hdmilight-v3-fpga/FLASH_SI: U5.64 (IO_L3N_MOSI_CSI_B_MISO0_2), U7.5 (SI/IO0)
/hdmilight-v3-fpga/FLASH_SO: U5.65 (IO_L3P_D0_DIN_MISO_MISO1_2), U7.2 (SO/IO1)
/hdmilight-v3-fpga/FPGA_GPIO0: U5.44 (IO_L62P_D5_2); also elsewhere on the board
/hdmilight-v3-fpga/FPGA_GPIO1: U5.45 (IO_L49N_D4_2); also elsewhere on the board
/hdmilight-v3-fpga/FPGA_GPIO2: U5.46 (IO_L49P_D3_2); also elsewhere on the board
/hdmilight-v3-fpga/FPGA_GPIO3: U5.47 (IO_L48N_RDWR_B_VREF_2); also elsewhere on the board
/hdmilight-v3-fpga/FPGA_GPIO4: U5.48 (IO_L48P_D7_2); also elsewhere on the board
/hdmilight-v3-fpga/FPGA_GPIO5: U5.50 (IO_L31N_GCLK30_D15_2); also elsewhere on the board
/hdmilight-v3-fpga/FPGA_GPIO6: U5.51 (IO_L31P_GCLK31_D14_2); also elsewhere on the board
/hdmilight-v3-fpga/FPGA_GPIO7: U5.55 (IO_L30N_GCLK0_USERCCLK_2); also elsewhere on the board
/hdmilight-v3-fpga/HS: U5.112 (IO_L66P_SCP1_0); also elsewhere on the board
/hdmilight-v3-fpga/LED_OUT0: U5.5 (IO_L52N_3); also elsewhere on the board
/hdmilight-v3-fpga/LED_OUT1: U5.6 (IO_L52P_3); also elsewhere on the board
/hdmilight-v3-fpga/LED_OUT2: U5.7 (IO_L51N_3); also elsewhere on the board
/hdmilight-v3-fpga/LED_OUT3: U5.8 (IO_L51P_3); also elsewhere on the board
/hdmilight-v3-fpga/LED_OUT4: U5.9 (IO_L50N_3); also elsewhere on the board
/hdmilight-v3-fpga/LED_OUT5: U5.10 (IO_L50P_3); also elsewhere on the board
/hdmilight-v3-fpga/LED_OUT6: U5.11 (IO_L49N_3); also elsewhere on the board
/hdmilight-v3-fpga/LED_OUT7: U5.12 (IO_L49P_3); also elsewhere on the board
/hdmilight-v3-fpga/LED_OUT8: U5.14 (IO_L44N_GCLK20_3); also elsewhere on the board
/hdmilight-v3-fpga/LED_OUT9: U5.15 (IO_L44P_GCLK21_3); also elsewhere on the board
/hdmilight-v3-fpga/LED_OUT10: U5.16 (IO_L43N_GCLK22_IRDY2_3); also elsewhere on the board
/hdmilight-v3-fpga/LED_OUT11: U5.17 (IO_L43P_GCLK23_3); also elsewhere on the board
/hdmilight-v3-fpga/LED_OUT12: U5.21 (IO_L42N_GCLK24_3); also elsewhere on the board
/hdmilight-v3-fpga/LED_OUT13: U5.22 (IO_L42P_GCLK25_TRDY2_3); also elsewhere on the board
/hdmilight-v3-fpga/LED_OUT14: U5.23 (IO_L41N_GCLK26_3); also elsewhere on the board
/hdmilight-v3-fpga/LED_OUT15: U5.24 (IO_L41P_GCLK27_3); also elsewhere on the board
/hdmilight-v3-fpga/LLC: U5.126 (IO_L36N_GCLK14_0); also elsewhere on the board
/hdmilight-v3-fpga/MCU_D2: U5.84 (IO_L43N_GCLK4_1); also elsewhere on the board
/hdmilight-v3-fpga/MCU_PB8: U5.78 (IO_L47N_1); also elsewhere on the board
/hdmilight-v3-fpga/P0: U5.115 (IO_L65P_SCP3_0); also elsewhere on the board
/hdmilight-v3-fpga/P1: U5.116 (IO_L64N_SCP4_0); also elsewhere on the board
/hdmilight-v3-fpga/P2: U5.117 (IO_L64P_SCP5_0); also elsewhere on the board
/hdmilight-v3-fpga/P3: U5.118 (IO_L63N_SCP6_0); also elsewhere on the board
/hdmilight-v3-fpga/P4: U5.119 (IO_L63P_SCP7_0); also elsewhere on the board
/hdmilight-v3-fpga/P5: U5.120 (IO_L62N_VREF_0); also elsewhere on the board
/hdmilight-v3-fpga/P6: U5.121 (IO_L62P_0); also elsewhere on the board
/hdmilight-v3-fpga/P7: U5.123 (IO_L37N_GCLK12_0); also elsewhere on the board
/hdmilight-v3-fpga/P8: U5.124 (IO_L37P_GCLK13_0); also elsewhere on the board
/hdmilight-v3-fpga/P9: U5.127 (IO_L36P_GCLK15_0); also elsewhere on the board
/hdmilight-v3-fpga/P10: U5.131 (IO_L35N_GCLK16_0); also elsewhere on the board
/hdmilight-v3-fpga/P11: U5.132 (IO_L35P_GCLK17_0); also elsewhere on the board
/hdmilight-v3-fpga/P12: U5.133 (IO_L34N_GCLK18_0); also elsewhere on the board
/hdmilight-v3-fpga/P13: U5.134 (IO_L34P_GCLK19_0); also elsewhere on the board
/hdmilight-v3-fpga/P14: U5.137 (IO_L4N_0); also elsewhere on the board
/hdmilight-v3-fpga/P15: U5.138 (IO_L4P_0); also elsewhere on the board
/hdmilight-v3-fpga/P16: U5.139 (IO_L3N_0); also elsewhere on the board
/hdmilight-v3-fpga/P17: U5.140 (IO_L3P_0); also elsewhere on the board
/hdmilight-v3-fpga/P18: U5.141 (IO_L2N_0); also elsewhere on the board
/hdmilight-v3-fpga/P19: U5.142 (IO_L2P_0); also elsewhere on the board
/hdmilight-v3-fpga/P20: U5.143 (IO_L1N_VREF_0); also elsewhere on the board
/hdmilight-v3-fpga/P21: U5.144 (IO_L1P_HSWAPEN_0); also elsewhere on the board
/hdmilight-v3-fpga/P22: U5.1 (IO_L83N_VREF_3); also elsewhere on the board
/hdmilight-v3-fpga/P23: U5.2 (IO_L83P_3); also elsewhere on the board
/hdmilight-v3-fpga/PAPIX_POS0: U5.34 (IO_L1N_VREF_3); also elsewhere on the board
/hdmilight-v3-fpga/PAPIX_POS1: U5.35 (IO_L1P_3); also elsewhere on the board
/hdmilight-v3-fpga/PAPIX_RGB0: U5.29 (IO_L36N_3); also elsewhere on the board
/hdmilight-v3-fpga/PAPIX_RGB1: U5.30 (IO_L36P_3); also elsewhere on the board
/hdmilight-v3-fpga/POS_SENSOR0: U5.83 (IO_L45P_1); also elsewhere on the board
/hdmilight-v3-fpga/POS_SENSOR1: U5.80 (IO_L46N_1); also elsewhere on the board
/hdmilight-v3-fpga/POS_SENSOR2: U5.75 (IO_L74P_AWAKE_1); also elsewhere on the board
/hdmilight-v3-fpga/POS_SENSOR3: U5.81 (IO_L46P_1); also elsewhere on the board
/hdmilight-v3-fpga/SPI_CLK: U5.88 (IO_L42P_GCLK7_1); also elsewhere on the board
/hdmilight-v3-fpga/SPI_MISO: U5.87 (IO_L42N_GCLK6_TRDY1_1); also elsewhere on the board
/hdmilight-v3-fpga/SPI_MOSI: U5.85 (IO_L43P_GCLK5_1); also elsewhere on the board
/hdmilight-v3-fpga/SPI_NSS: U5.74 (IO_L74N_DOUT_BUSY_1); also elsewhere on the board
/hdmilight-v3-fpga/TDI: U5.110 (TDI); also elsewhere on the board
/hdmilight-v3-fpga/VS: U5.111 (IO_L66N_SCP0_0); also elsewhere on the board
/hdmilight-v3-microcontroller/FPGA_RST: J3.2, R22.2, U5.37 (PROGRAM_B_2); also elsewhere on the board
/hdmilight-v3-microcontroller/JTCK: U5.92 (IO_L41N_GCLK8_1), U5.109 (TCK); also elsewhere on the board
/hdmilight-v3-microcontroller/JTDI: U5.93 (IO_L41P_GCLK9_IRDY1_1), U5.106 (TDO); also elsewhere on the board
/hdmilight-v3-microcontroller/JTMS: U5.107 (TMS); also elsewhere on the board
FPGA_1V2: C99.1, C101.1, C103.1, C105.1, C107.1, C108.1, C110.1, C112.1, C114.1, C116.1, U5.19 (VCCINT), U5.28 (VCCINT), U5.52 (VCCINT), U5.89 (VCCINT), U5.128 (VCCINT); also elsewhere on the board
FPGA_3V3: C58.1, C72.1, C73.1, C74.1, C75.1, C76.1, C77.1, C78.1, C79.1, C80.1, C81.1, C82.1, C83.1, C84.1, C85.1, C86.1, C98.1, C100.1, C102.1, C104.1, C106.1, C109.1, C111.1, C113.1, C115.1, C117.1, C118.1, R22.1, R56.1, R57.1, R70.1, U5.4 (VCCO_3), U5.18 (VCCO_3), U5.20 (VCCAUX), U5.31 (VCCO_3), U5.36 (VCCAUX), U5.42 (VCCO_2), U5.53 (VCCAUX), U5.63 (VCCO_2), U5.69 (IO_L1N_M0_CMPMISO_2), U5.76 (VCCO_1), U5.86 (VCCO_1), U5.90 (VCCAUX), U5.103 (VCCO_1), U5.122 (VCCO_0), U5.125 (VCCO_0), U5.129 (VCCAUX), U5.135 (VCCO_0), U7.3 (~WP~/IO2), U7.7 (~HOLD~/IO3), U7.8 (VCC), X1.1 (EN), X1.4 (Vdd); also elsewhere on the board
GND: C58.2, C72.2, C73.2, C74.2, C75.2, C76.2, C77.2, C78.2, C79.2, C80.2, C81.2, C82.2, C83.2, C84.2, C85.2, C86.2, C98.2, C99.2, C100.2, C101.2, C102.2, C103.2, C104.2, C105.2, C106.2, C107.2, C108.2, C109.2, C110.2, C111.2, C112.2, C113.2, C114.2, C115.2, C116.2, C117.2, C118.2, D6.1 (K), J3.1, U5.3 (GND), U5.13 (GND), U5.25 (GND), U5.49 (GND), U5.54 (GND), U5.60 (IO_L13P_M1_2), U5.68 (GND), U5.73 (SUSPEND), U5.77 (GND), U5.91 (GND), U5.96 (GND), U5.108 (GND), U5.113 (GND), U5.130 (GND), U5.136 (GND), U7.4 (GND), X1.2 (GND); also elsewhere on the board
unnamed: D6.2 (A), R71.2
unnamed: R57.2, U5.39 (IO_L65P_INIT_B_2)

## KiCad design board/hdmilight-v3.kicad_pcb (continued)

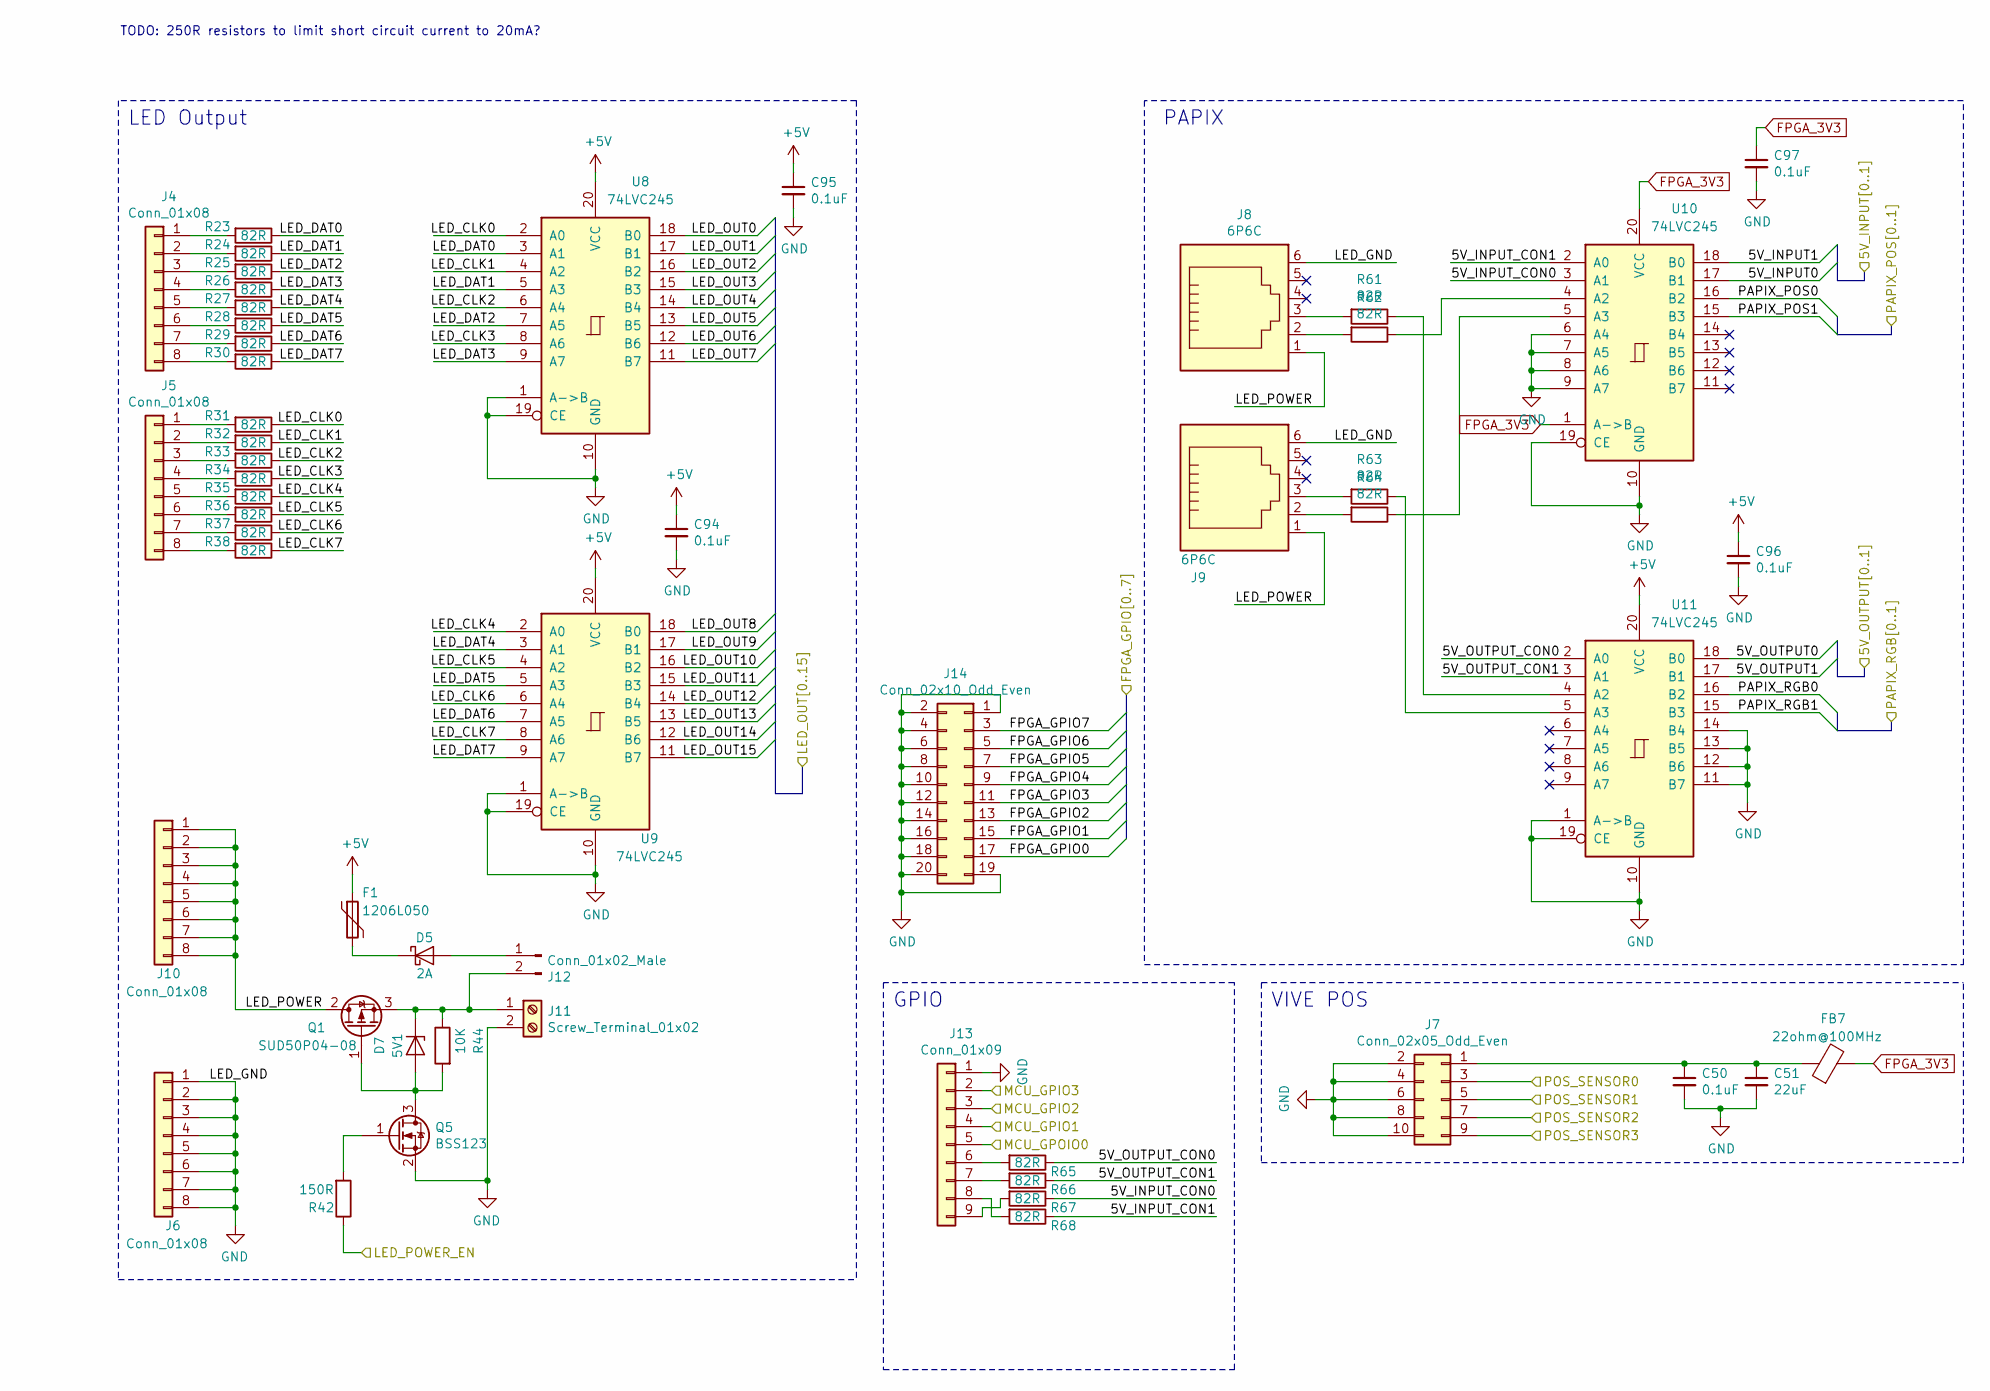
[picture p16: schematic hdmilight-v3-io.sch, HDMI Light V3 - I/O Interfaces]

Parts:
C50: 0.1uF; C_0603_1608Metric
C51: 22uF; C_0805_2012Metric
C94, C95, C96, C97: 0.1uF; C_0402_1005Metric
D5: 2A; D_SOD-323
D7: 5V1; D_SOD-323
F1: 1206L050; Fuse_1206_3216Metric
FB7: 22ohm@100MHz; L_0805_2012Metric
J4, J5, J6, J10: Conn_01x08; PinSocket_1x08_P2.54mm_Vertical
J7: Conn_02x05_Odd_Even; IDC-Header_2x05_P2.54mm_Horizontal
J8, J9: 6P6C; RJ12_Amphenol_54601
J11: Screw_Terminal_01x02; TerminalBlock_Phoenix_MKDS-1,5-2_1x02_P5.00mm_Horizontal
J12: Conn_01x02_Male; PinHeader_1x02_P2.54mm_Vertical
J13: Conn_01x09; PinSocket_1x09_P2.54mm_Vertical
J14: Conn_02x10_Odd_Even; PinHeader_2x10_P2.54mm_Horizontal
Q1: SUD50P04-08; TO-252-2
Q5: BSS123; SOT-23
R23, R24, R25, R26, R27, R28, R29, R30, R31, R32, R33, R34, R35, R36, R37, R38, R61, R62, R63, R64, R65, R66, R67, R68: 82R; R_0603_1608Metric
R42: 150R; R_0603_1608Metric
R44: 10K; R_0603_1608Metric
U8, U9, U10, U11: 74LVC245; TSSOP-20_4.4x6.5mm_P0.65mm

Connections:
+5V: C94.1, C95.1, C96.1, F1.1, U8.20 (VCC), U9.20 (VCC), U11.20 (VCC); also elsewhere on the board
/hdmilight-v3-fpga/5V_INPUT0: U10.17 (B1); also elsewhere on the board
/hdmilight-v3-fpga/5V_INPUT1: U10.18 (B0); also elsewhere on the board
/hdmilight-v3-fpga/5V_OUTPUT0: U11.18 (B0); also elsewhere on the board
/hdmilight-v3-fpga/5V_OUTPUT1: U11.17 (B1); also elsewhere on the board
/hdmilight-v3-fpga/FPGA_GPIO0: J14.17; also elsewhere on the board
/hdmilight-v3-fpga/FPGA_GPIO1: J14.15; also elsewhere on the board
/hdmilight-v3-fpga/FPGA_GPIO2: J14.13; also elsewhere on the board
/hdmilight-v3-fpga/FPGA_GPIO3: J14.11; also elsewhere on the board
/hdmilight-v3-fpga/FPGA_GPIO4: J14.9; also elsewhere on the board
/hdmilight-v3-fpga/FPGA_GPIO5: J14.7; also elsewhere on the board
/hdmilight-v3-fpga/FPGA_GPIO6: J14.5; also elsewhere on the board
/hdmilight-v3-fpga/FPGA_GPIO7: J14.3; also elsewhere on the board
/hdmilight-v3-fpga/LED_OUT0: U8.18 (B0); also elsewhere on the board
/hdmilight-v3-fpga/LED_OUT1: U8.17 (B1); also elsewhere on the board
/hdmilight-v3-fpga/LED_OUT2: U8.16 (B2); also elsewhere on the board
/hdmilight-v3-fpga/LED_OUT3: U8.15 (B3); also elsewhere on the board
/hdmilight-v3-fpga/LED_OUT4: U8.14 (B4); also elsewhere on the board
/hdmilight-v3-fpga/LED_OUT5: U8.13 (B5); also elsewhere on the board
/hdmilight-v3-fpga/LED_OUT6: U8.12 (B6); also elsewhere on the board
/hdmilight-v3-fpga/LED_OUT7: U8.11 (B7); also elsewhere on the board
/hdmilight-v3-fpga/LED_OUT8: U9.18 (B0); also elsewhere on the board
/hdmilight-v3-fpga/LED_OUT9: U9.17 (B1); also elsewhere on the board
/hdmilight-v3-fpga/LED_OUT10: U9.16 (B2); also elsewhere on the board
/hdmilight-v3-fpga/LED_OUT11: U9.15 (B3); also elsewhere on the board
/hdmilight-v3-fpga/LED_OUT12: U9.14 (B4); also elsewhere on the board
/hdmilight-v3-fpga/LED_OUT13: U9.13 (B5); also elsewhere on the board
/hdmilight-v3-fpga/LED_OUT14: U9.12 (B6); also elsewhere on the board
/hdmilight-v3-fpga/LED_OUT15: U9.11 (B7); also elsewhere on the board
/hdmilight-v3-fpga/PAPIX_POS0: U10.16 (B2); also elsewhere on the board
/hdmilight-v3-fpga/PAPIX_POS1: U10.15 (B3); also elsewhere on the board
/hdmilight-v3-fpga/PAPIX_RGB0: U11.16 (B2); also elsewhere on the board
/hdmilight-v3-fpga/PAPIX_RGB1: U11.15 (B3); also elsewhere on the board
/hdmilight-v3-fpga/POS_SENSOR0: J7.3; also elsewhere on the board
/hdmilight-v3-fpga/POS_SENSOR1: J7.5; also elsewhere on the board
/hdmilight-v3-fpga/POS_SENSOR2: J7.7; also elsewhere on the board
/hdmilight-v3-fpga/POS_SENSOR3: J7.9; also elsewhere on the board
/hdmilight-v3-io/5V_INPUT_CON0: R67.1, U10.3 (A1)
/hdmilight-v3-io/5V_INPUT_CON1: R68.1, U10.2 (A0)
/hdmilight-v3-io/5V_OUTPUT_CON0: R65.1, U11.2 (A0)
/hdmilight-v3-io/5V_OUTPUT_CON1: R66.1, U11.3 (A1)
/hdmilight-v3-io/LED_CLK0: R31.1, U8.2 (A0)
/hdmilight-v3-io/LED_CLK1: R32.1, U8.4 (A2)
/hdmilight-v3-io/LED_CLK2: R33.1, U8.6 (A4)
/hdmilight-v3-io/LED_CLK3: R34.1, U8.8 (A6)
/hdmilight-v3-io/LED_CLK4: R35.1, U9.2 (A0)
/hdmilight-v3-io/LED_CLK5: R36.1, U9.4 (A2)
/hdmilight-v3-io/LED_CLK6: R37.1, U9.6 (A4)
/hdmilight-v3-io/LED_CLK7: R38.1, U9.8 (A6)
/hdmilight-v3-io/LED_DAT0: R23.1, U8.3 (A1)
/hdmilight-v3-io/LED_DAT1: R24.1, U8.5 (A3)
/hdmilight-v3-io/LED_DAT2: R25.1, U8.7 (A5)
/hdmilight-v3-io/LED_DAT3: R26.1, U8.9 (A7)
/hdmilight-v3-io/LED_DAT4: R27.1, U9.3 (A1)
/hdmilight-v3-io/LED_DAT5: R28.1, U9.5 (A3)
/hdmilight-v3-io/LED_DAT6: R29.1, U9.7 (A5)
/hdmilight-v3-io/LED_DAT7: R30.1, U9.9 (A7)
/hdmilight-v3-io/LED_POWER: J8.1, J9.1, J10.1, J10.2, J10.3, J10.4, J10.5, J10.6, J10.7, J10.8, Q1.2 (D)
/hdmilight-v3-io/LED_POWER_EN: R42.1; also elsewhere on the board
/hdmilight-v3-io/MCU_GPIO1: J13.4; also elsewhere on the board
/hdmilight-v3-io/MCU_GPIO2: J13.3; also elsewhere on the board
/hdmilight-v3-io/MCU_GPIO3: J13.2; also elsewhere on the board
/hdmilight-v3-microcontroller/MCU_GPIO0: J13.5; also elsewhere on the board
FPGA_3V3: C97.1, FB7.2, U10.1 (A->B), U10.20 (VCC); also elsewhere on the board
GND: C50.2, C51.2, C94.2, C95.2, C96.2, C97.2, J6.1, J6.2, J6.3, J6.4, J6.5, J6.6, J6.7, J6.8, J7.2, J7.4, J7.6, J7.8, J7.10, J8.6, J9.6, J11.2, J13.1, J14.1, J14.2, J14.4, J14.6, J14.8, J14.10, J14.12, J14.14, J14.16, J14.18, J14.19, J14.20, Q5.2 (S), U8.1 (A->B), U8.10 (GND), U8.19 (CE), U9.1 (A->B), U9.10 (GND), U9.19 (CE), U10.6 (A4), U10.7 (A5), U10.8 (A6), U10.9 (A7), U10.10 (GND), U10.19 (CE), U11.1 (A->B), U11.10 (GND), U11.11 (B7), U11.12 (B6), U11.13 (B5), U11.14 (B4), U11.19 (CE); also elsewhere on the board
unnamed: C50.1, C51.1, FB7.1, J7.1
unnamed: D5.1 (K), F1.2
unnamed: D5.2 (A), J12.1
unnamed: D7.1 (K), J11.1, J12.2, Q1.3 (S), R44.1
unnamed: D7.2 (A), Q1.1 (G), Q5.3 (D), R44.2
unnamed: J4.1, R23.2
unnamed: J4.2, R24.2
unnamed: J4.3, R25.2
unnamed: J4.4, R26.2
unnamed: J4.5, R27.2
unnamed: J4.6, R28.2
unnamed: J4.7, R29.2
unnamed: J4.8, R30.2
unnamed: J5.1, R31.2
unnamed: J5.2, R32.2
unnamed: J5.3, R33.2
unnamed: J5.4, R34.2
unnamed: J5.5, R35.2
unnamed: J5.6, R36.2
unnamed: J5.7, R37.2
unnamed: J5.8, R38.2
unnamed: J8.2, R62.2
unnamed: J8.3, R61.2
unnamed: J9.2, R64.2
unnamed: J9.3, R63.2
unnamed: J13.6, R65.2
unnamed: J13.7, R66.2
unnamed: J13.8, R68.2
unnamed: J13.9, R67.2
unnamed: Q5.1 (G), R42.2
unnamed: R61.1, U11.4 (A2)
unnamed: R62.1, U10.4 (A2)
unnamed: R63.1, U11.5 (A3)
unnamed: R64.1, U10.5 (A3)

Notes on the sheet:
TODO: 250R resistors to limit short circuit current to 20mA?
LED Output
PAPIX
VIVE POS
GPIO

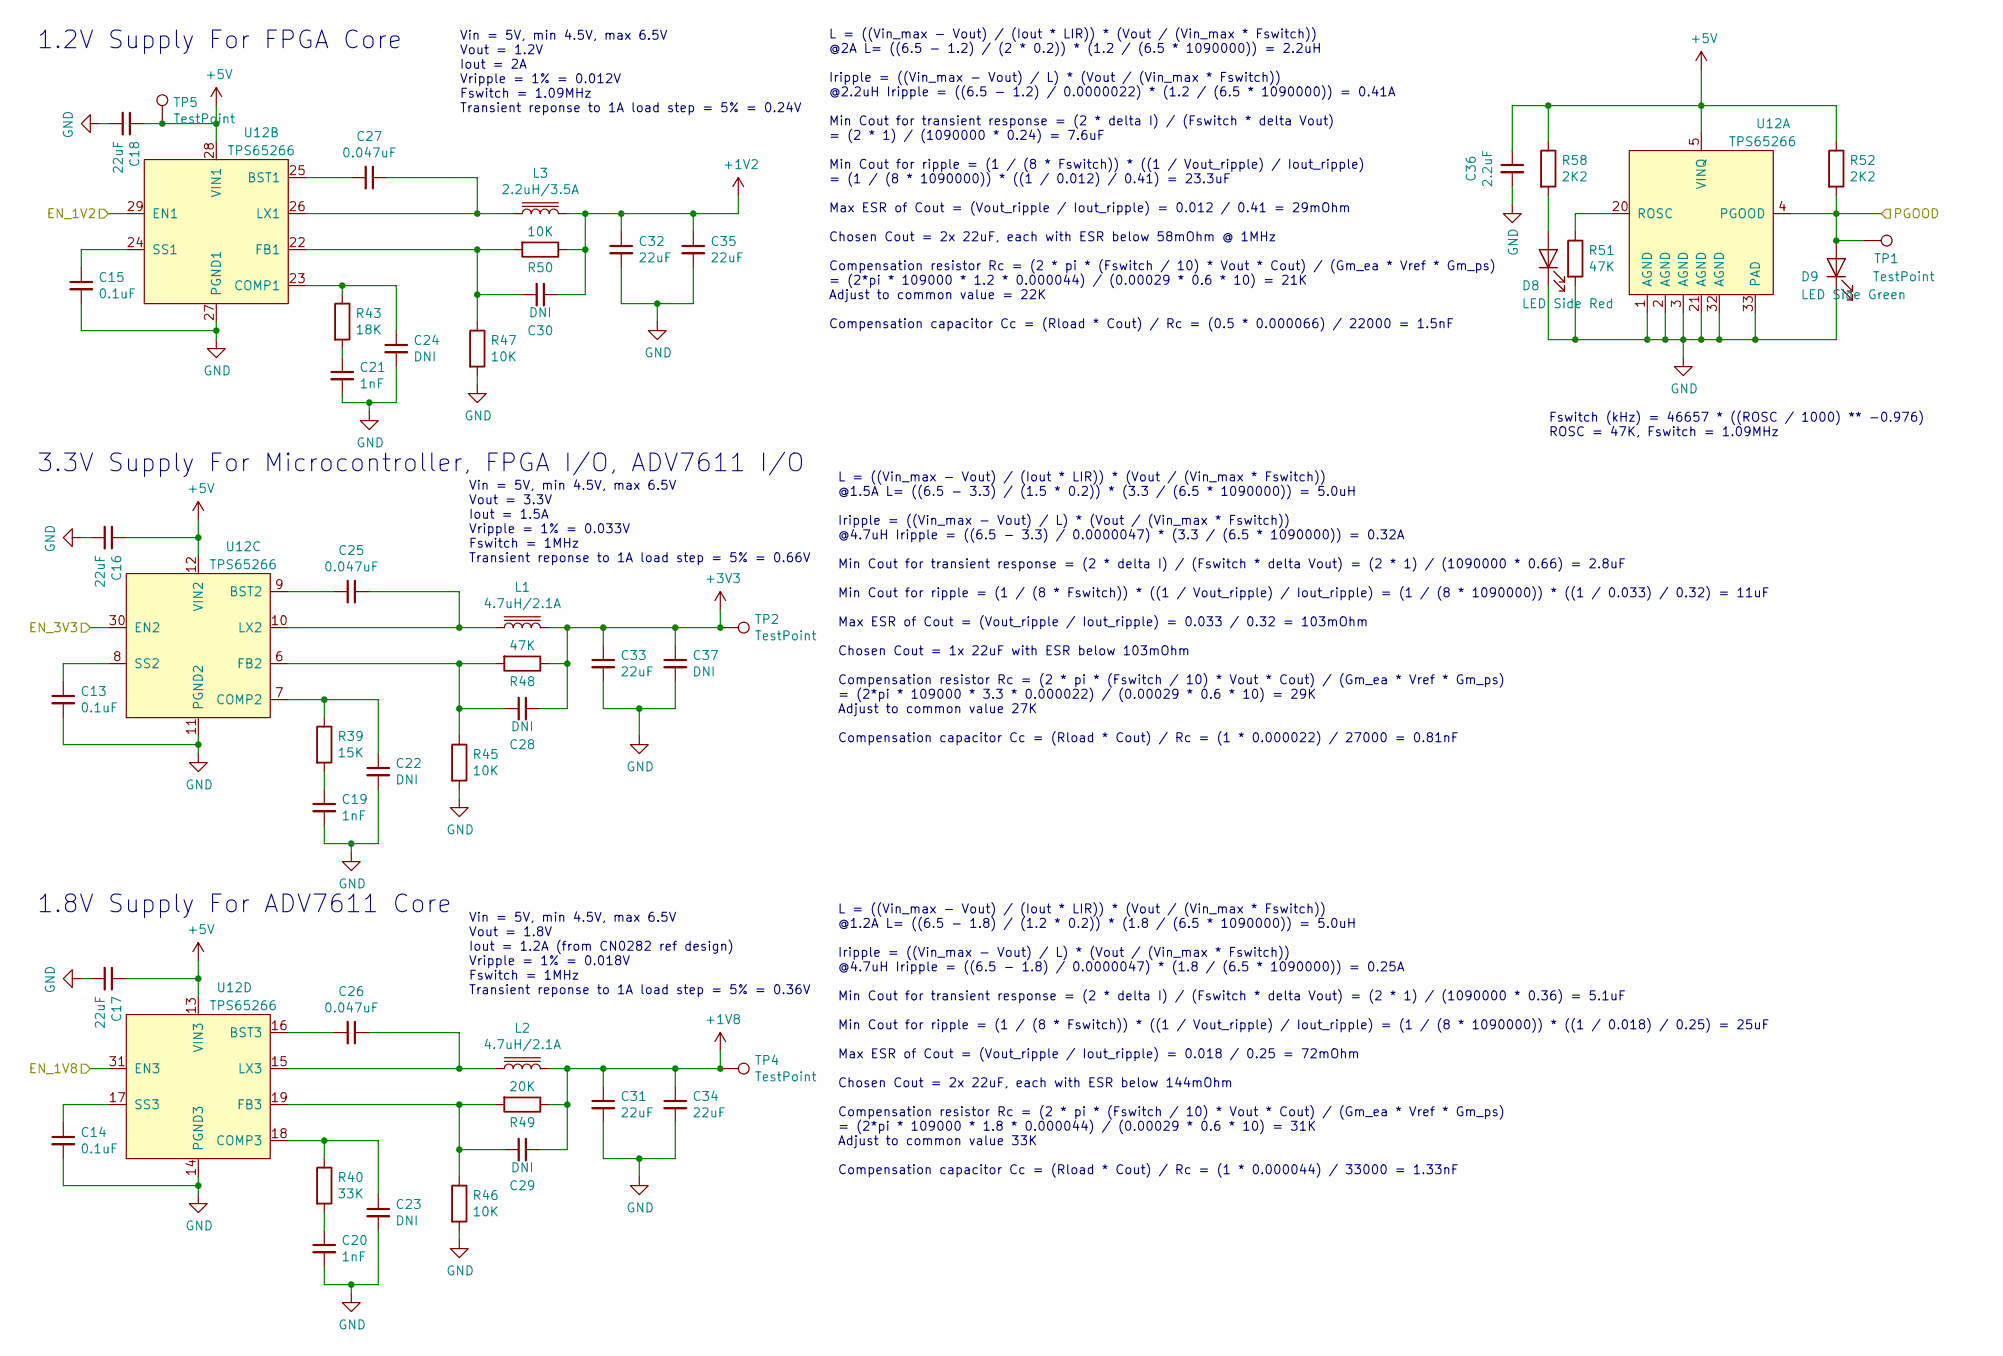
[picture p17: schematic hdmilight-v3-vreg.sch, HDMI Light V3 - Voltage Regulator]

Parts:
C13, C14, C15: 0.1uF; C_0603_1608Metric
C16, C17, C18, C31, C32, C33, C34, C35: 22uF; C_0805_2012Metric
C19, C20, C21: 1nF; C_0603_1608Metric
C22, C23, C24, C28, C29, C30: DNI; C_0603_1608Metric
C25, C26, C27: 0.047uF; C_0603_1608Metric
C36: 2.2uF; C_0603_1608Metric
C37: DNI; C_0805_2012Metric
D8: LED Side Red; LED_0603_1608Metric
D9: LED Side Green; LED_0603_1608Metric
L1, L2: 4.7uH/2.1A; L_Bourns-SRN4018
L3: 2.2uH/3.5A; L_Bourns-SRN4018
R39: 15K; R_0603_1608Metric
R40: 33K; R_0603_1608Metric
R43: 18K; R_0603_1608Metric
R45, R46, R47, R50: 10K; R_0603_1608Metric
R48, R51: 47K; R_0603_1608Metric
R49: 20K; R_0603_1608Metric
R52, R58: 2K2; R_0603_1608Metric
TP1, TP2, TP4, TP5: TestPoint; TestPoint_Pad_D1.5mm
U12: TPS65266; QFN-32-1EP_5x5mm_P0.5mm_EP3.1x3.1mm_ThermalVias

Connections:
+1V2: C30.1, C32.1, C35.1, L3.2, R50.1; also elsewhere on the board
+1V8: C29.1, C31.1, C34.1, L2.2, R49.1, TP4.1; also elsewhere on the board
+3V3: C28.1, C33.1, C37.1, L1.2, R48.1, TP2.1; also elsewhere on the board
+5V: C16.1, C17.1, C18.1, C36.1, R52.1, R58.1, TP5.1, U12.5 (VINQ), U12.12 (VIN2), U12.13 (VIN3), U12.28 (VIN1); also elsewhere on the board
/hdmilight-v3-vreg/EN_1V2: U12.29 (EN1); also elsewhere on the board
/hdmilight-v3-vreg/EN_1V8: U12.31 (EN3); also elsewhere on the board
/hdmilight-v3-vreg/EN_3V3: U12.30 (EN2)
/hdmilight-v3-vreg/PGOOD: D9.2 (A), R52.2, TP1.1, U12.4 (PGOOD)
GND: C13.2, C14.2, C15.2, C16.2, C17.2, C18.2, C19.2, C20.2, C21.2, C22.2, C23.2, C24.2, C31.2, C32.2, C33.2, C34.2, C35.2, C36.2, C37.2, D8.1 (K), D9.1 (K), R45.2, R46.2, R47.2, R51.2, U12.1 (AGND), U12.2 (AGND), U12.3 (AGND), U12.11 (PGND2), U12.14 (PGND3), U12.21 (AGND), U12.27 (PGND1), U12.32 (AGND), U12.33 (PAD); also elsewhere on the board
unnamed: C13.1, U12.8 (SS2)
unnamed: C14.1, U12.17 (SS3)
unnamed: C15.1, U12.24 (SS1)
unnamed: C19.1, R39.2
unnamed: C20.1, R40.2
unnamed: C21.1, R43.2
unnamed: C22.1, R39.1, U12.7 (COMP2)
unnamed: C23.1, R40.1, U12.18 (COMP3)
unnamed: C24.1, R43.1, U12.23 (COMP1)
unnamed: C25.1, L1.1, U12.10 (LX2)
unnamed: C25.2, U12.9 (BST2)
unnamed: C26.1, L2.1, U12.15 (LX3)
unnamed: C26.2, U12.16 (BST3)
unnamed: C27.1, L3.1, U12.26 (LX1)
unnamed: C27.2, U12.25 (BST1)
unnamed: C28.2, R45.1, R48.2, U12.6 (FB2)
unnamed: C29.2, R46.1, R49.2, U12.19 (FB3)
unnamed: C30.2, R47.1, R50.2, U12.22 (FB1)
unnamed: D8.2 (A), R58.2
unnamed: R51.1, U12.20 (ROSC)

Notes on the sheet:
1.2V Supply For FPGA Core
Vin = 5V, min 4.5V, max 6.5V Vout = 1.2V Iout = 2A Vripple = 1% = 0.012V Fswitch = 1.09MHz Transient reponse to 1A load step = 5% = 0.24V
L = ((Vin_max - Vout) / (Iout * LIR)) * (Vout / (Vin_max * Fswitch)) @2A L= ((6.5 - 1.2) / (2 * 0.2)) * (1.2 / (6.5 * 1090000)) = 2.2uH Iripple = ((Vin_max - Vout) / L) * (Vout / (Vin_max * Fswitch)) @2.2uH Iripple = ((6.5 - 1.2) / 0.0000022) * (1.2 / (6.5 * 1090000)) = 0.41A Min Cout for transient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
Fswitch (kHz) = 46657 * ((ROSC / 1000) ** -0.976) ROSC = 47K, Fswitch = 1.09MHz
3.3V Supply For Microcontroller, FPGA I/O, ADV7611 I/O
Vin = 5V, min 4.5V, max 6.5V Vout = 3.3V Iout = 1.5A Vripple = 1% = 0.033V Fswitch = 1MHz Transient reponse to 1A load step = 5% = 0.66V
1.8V Supply For ADV7611 Core
Vin = 5V, min 4.5V, max 6.5V Vout = 1.8V Iout = 1.2A (from CN0282 ref design) Vripple = 1% = 0.018V Fswitch = 1MHz Transient reponse to 1A load step = 5% = 0.36V
L = ((Vin_max - Vout) / (Iout * LIR)) * (Vout / (Vin_max * Fswitch)) @1.2A L= ((6.5 - 1.8) / (1.2 * 0.2)) * (1.8 / (6.5 * 1090000)) = 5.0uH Iripple = ((Vin_max - Vout) / L) * (Vout / (Vin_max * Fswitch)) @4.7uH Iripple = ((6.5 - 1.8) / 0.0000047) * (1.8 / (6.5 * 1090000)) = 0.25A Min Cout for trans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
L = ((Vin_max - Vout) / (Iout * LIR)) * (Vout / (Vin_max * Fswitch)) @1.5A L= ((6.5 - 3.3) / (1.5 * 0.2)) * (3.3 / (6.5 * 1090000)) = 5.0uH Iripple = ((Vin_max - Vout) / L) * (Vout / (Vin_max * Fswitch)) @4.7uH Iripple = ((6.5 - 3.3) / 0.0000047) * (3.3 / (6.5 * 1090000)) = 0.32A Min Cout for trans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

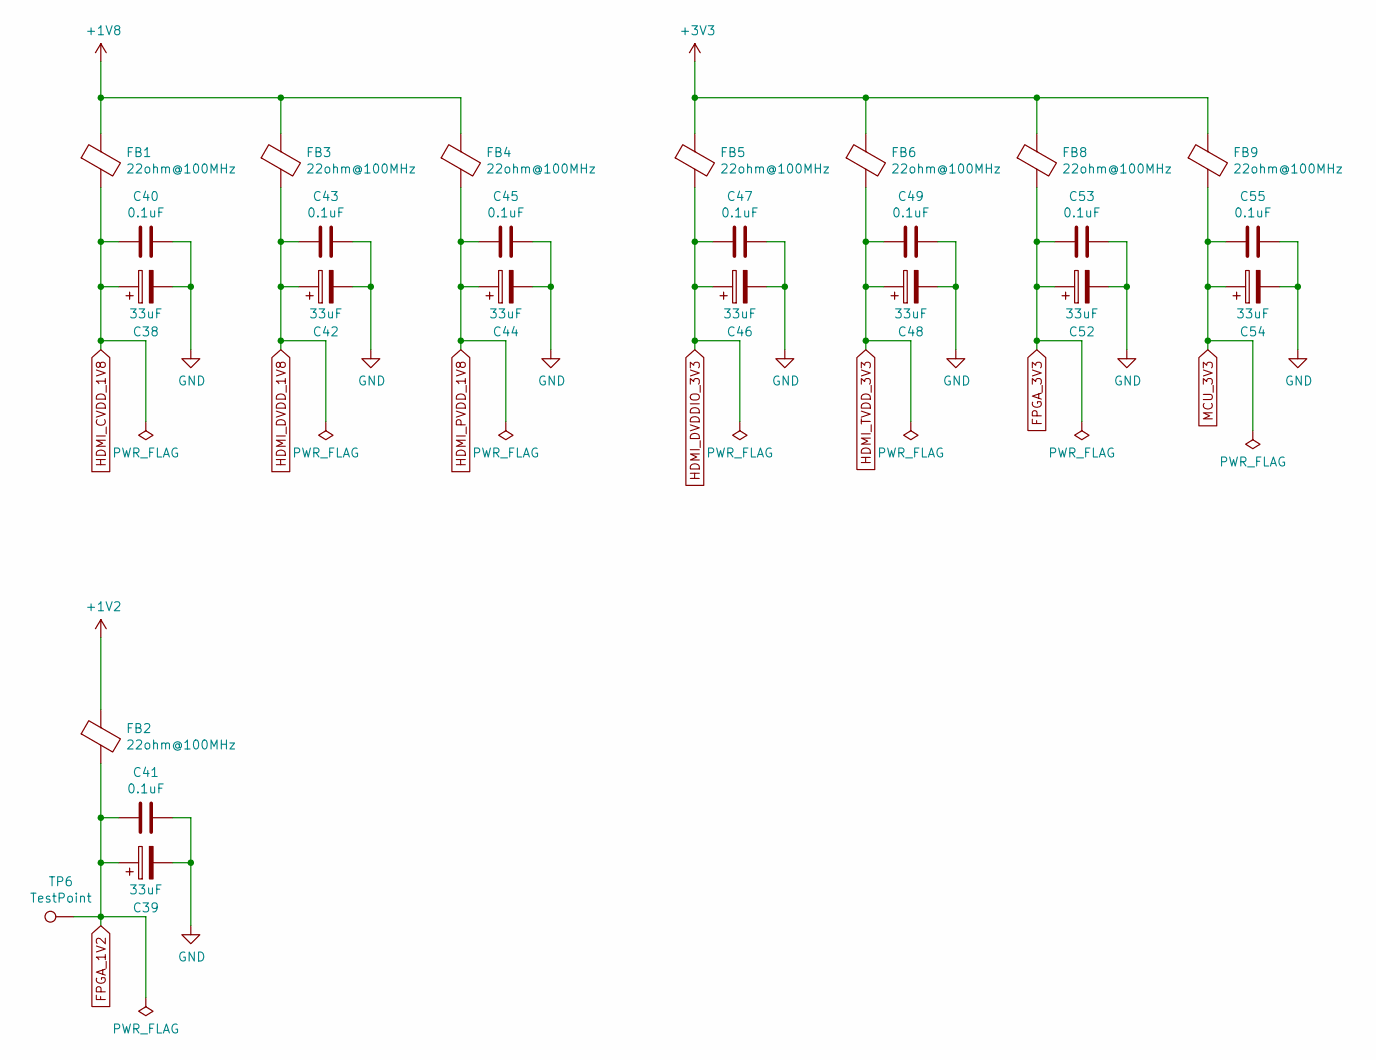
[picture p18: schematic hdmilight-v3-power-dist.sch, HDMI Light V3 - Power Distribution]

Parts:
C38, C39, C42, C44, C46, C48, C52, C54: 33uF; CP_EIA-3528-21_Kemet-B
C40, C41, C43, C45, C47, C49, C53, C55: 0.1uF; C_0603_1608Metric
FB1, FB2, FB3, FB4, FB5, FB6, FB8, FB9: 22ohm@100MHz; L_0805_2012Metric
TP6: TestPoint; TestPoint_Pad_D1.5mm

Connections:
+1V2: FB2.1; also elsewhere on the board
+1V8: FB1.1, FB3.1, FB4.1; also elsewhere on the board
+3V3: FB5.1, FB6.1, FB8.1, FB9.1; also elsewhere on the board
FPGA_1V2: C39.1, C41.1, FB2.2, TP6.1; also elsewhere on the board
FPGA_3V3: C52.1, C53.1, FB8.2; also elsewhere on the board
GND: C38.2, C39.2, C40.2, C41.2, C42.2, C43.2, C44.2, C45.2, C46.2, C47.2, C48.2, C49.2, C52.2, C53.2, C54.2, C55.2; also elsewhere on the board
HDMI_CVDD_1V8: C38.1, C40.1, FB1.2; also elsewhere on the board
HDMI_DVDDIO_3V3: C46.1, C47.1, FB5.2; also elsewhere on the board
HDMI_DVDD_1V8: C42.1, C43.1, FB3.2; also elsewhere on the board
HDMI_PVDD_1V8: C44.1, C45.1, FB4.2; also elsewhere on the board
HDMI_TVDD_3V3: C48.1, C49.1, FB6.2; also elsewhere on the board
MCU_3V3: C54.1, C55.1, FB9.2; also elsewhere on the board

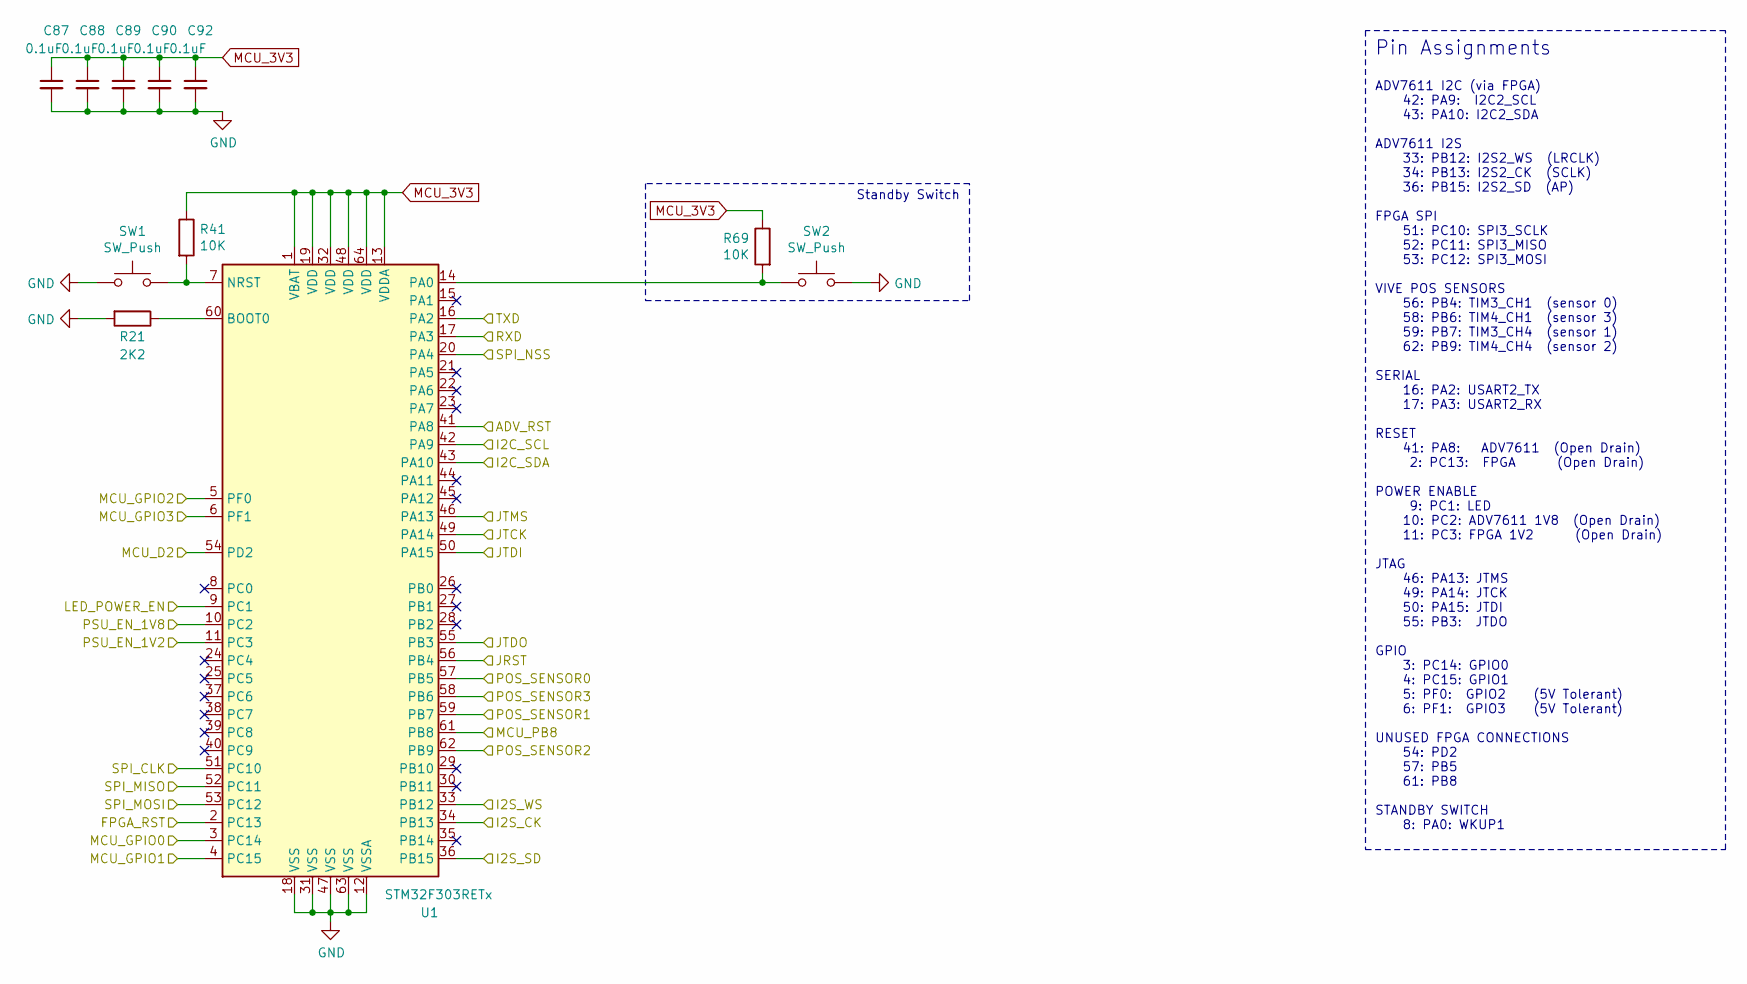
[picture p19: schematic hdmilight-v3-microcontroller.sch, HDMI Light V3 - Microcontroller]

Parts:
C87, C88, C89, C90, C92: 0.1uF; C_0402_1005Metric
R21: 2K2; R_0603_1608Metric
R41, R69: 10K; R_0603_1608Metric
SW1: SW_Push; SW_SPST_EVQP0
SW2: SW_Push; SW_Tactile_SPST_Angled_PTS645Vx31-2LFS
U1: STM32F303RETx; LQFP-64_10x10mm_P0.5mm

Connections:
/hdmilight-v3-fpga/ADV_AP: U1.36 (PB15); also elsewhere on the board
/hdmilight-v3-fpga/ADV_LRCLK: U1.33 (PB12); also elsewhere on the board
/hdmilight-v3-fpga/ADV_RST: U1.41 (PA8); also elsewhere on the board
/hdmilight-v3-fpga/ADV_SCL: U1.42 (PA9); also elsewhere on the board
/hdmilight-v3-fpga/ADV_SCLK: U1.34 (PB13); also elsewhere on the board
/hdmilight-v3-fpga/ADV_SDA: U1.43 (PA10); also elsewhere on the board
/hdmilight-v3-fpga/MCU_D2: U1.54 (PD2); also elsewhere on the board
/hdmilight-v3-fpga/MCU_PB8: U1.61 (PB8); also elsewhere on the board
/hdmilight-v3-fpga/POS_SENSOR0: U1.57 (PB5); also elsewhere on the board
/hdmilight-v3-fpga/POS_SENSOR1: U1.59 (PB7); also elsewhere on the board
/hdmilight-v3-fpga/POS_SENSOR2: U1.62 (PB9); also elsewhere on the board
/hdmilight-v3-fpga/POS_SENSOR3: U1.58 (PB6); also elsewhere on the board
/hdmilight-v3-fpga/SPI_CLK: U1.51 (PC10); also elsewhere on the board
/hdmilight-v3-fpga/SPI_MISO: U1.52 (PC11); also elsewhere on the board
/hdmilight-v3-fpga/SPI_MOSI: U1.53 (PC12); also elsewhere on the board
/hdmilight-v3-fpga/SPI_NSS: U1.20 (PA4); also elsewhere on the board
/hdmilight-v3-io/LED_POWER_EN: U1.9 (PC1); also elsewhere on the board
/hdmilight-v3-io/MCU_GPIO1: U1.4 (PC15); also elsewhere on the board
/hdmilight-v3-io/MCU_GPIO2: U1.5 (PF0); also elsewhere on the board
/hdmilight-v3-io/MCU_GPIO3: U1.6 (PF1); also elsewhere on the board
/hdmilight-v3-microcontroller/FPGA_RST: U1.2 (PC13); also elsewhere on the board
/hdmilight-v3-microcontroller/JRST: U1.56 (PB4)
/hdmilight-v3-microcontroller/JTCK: U1.49 (PA14); also elsewhere on the board
/hdmilight-v3-microcontroller/JTDI: U1.50 (PA15); also elsewhere on the board
/hdmilight-v3-microcontroller/JTDO: U1.55 (PB3); also elsewhere on the board
/hdmilight-v3-microcontroller/JTMS: U1.46 (PA13); also elsewhere on the board
/hdmilight-v3-microcontroller/MCU_GPIO0: U1.3 (PC14); also elsewhere on the board
/hdmilight-v3-microcontroller/RXD: U1.17 (PA3); also elsewhere on the board
/hdmilight-v3-microcontroller/TXD: U1.16 (PA2); also elsewhere on the board
/hdmilight-v3-vreg/EN_1V2: U1.11 (PC3); also elsewhere on the board
/hdmilight-v3-vreg/EN_1V8: U1.10 (PC2); also elsewhere on the board
GND: C87.2, C88.2, C89.2, C90.2, C92.2, R21.2, SW1.1, SW2.1, U1.12 (VSSA), U1.18 (VSS), U1.31 (VSS), U1.47 (VSS), U1.63 (VSS); also elsewhere on the board
MCU_3V3: C87.1, C88.1, C89.1, C90.1, C92.1, R41.1, R69.1, U1.1 (VBAT), U1.13 (VDDA), U1.19 (VDD), U1.32 (VDD), U1.48 (VDD), U1.64 (VDD); also elsewhere on the board
unnamed: R21.1, U1.60 (BOOT0)
unnamed: R41.2, SW1.2, U1.7 (NRST)
unnamed: R69.2, SW2.2, U1.14 (PA0)

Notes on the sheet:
ADV7611 I2C (via FPGA) 42: PA9: I2C2_SCL 43: PA10: I2C2_SDA ADV7611 I2S 33: PB12: I2S2_WS (LRCLK) 34: PB13: I2S2_CK (SCLK) 36: PB15: I2S2_SD (AP) FPGA SPI 51: PC10: SPI3_SCLK 52: PC11: SPI3_MISO 53: PC12: SPI3_MOSI VIVE POS SENSORS 56: PB4: TIM3_CH1 (sensor 0) 58: PB6: TIM4_CH1 (sensor 3) 59: PB7: 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
Pin Assignments
Standby Switch

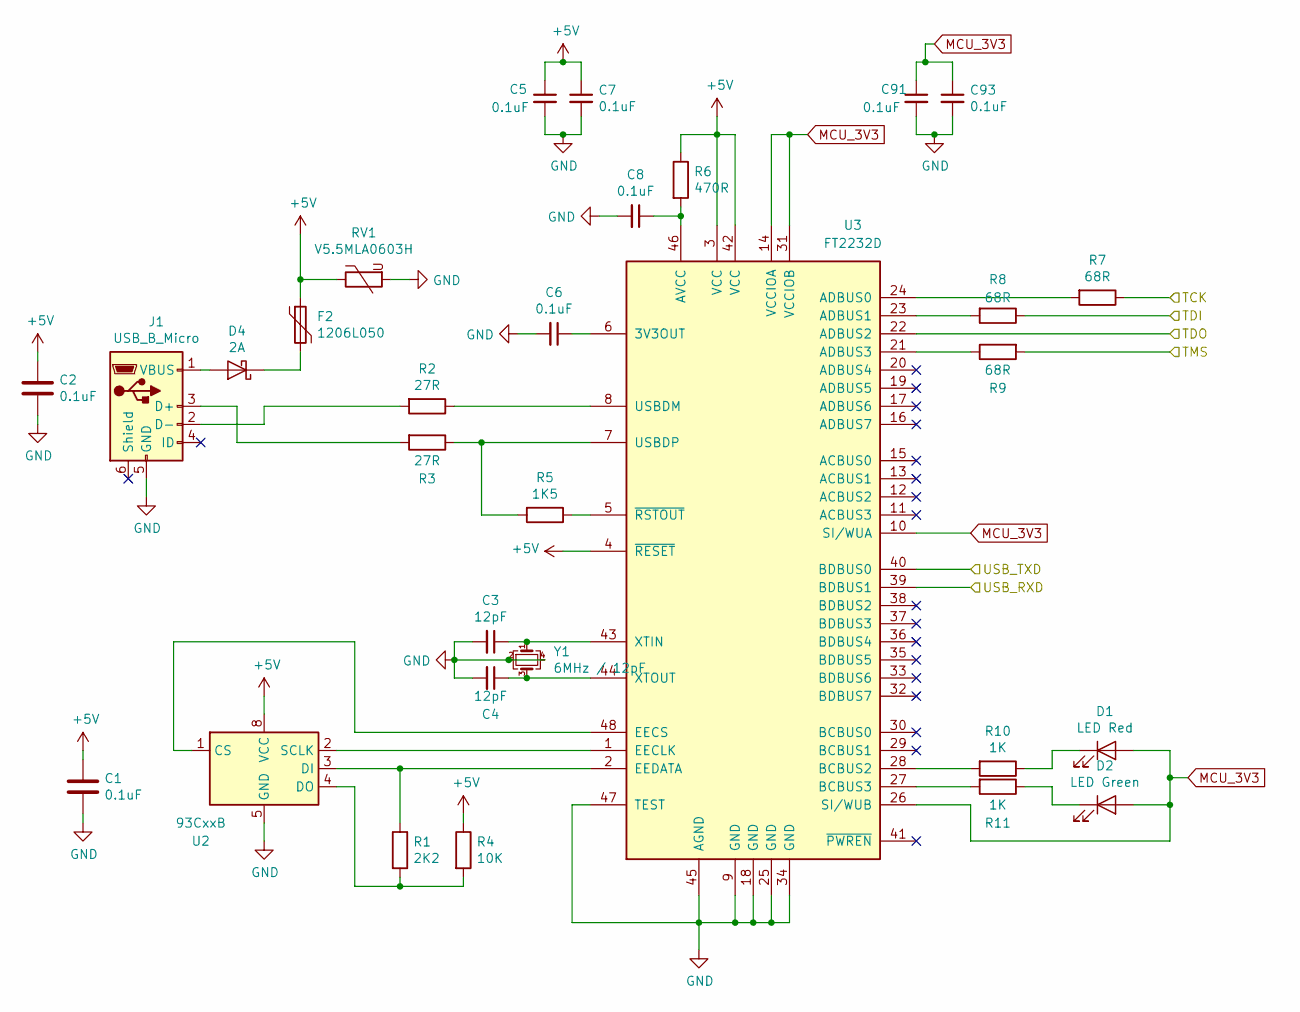
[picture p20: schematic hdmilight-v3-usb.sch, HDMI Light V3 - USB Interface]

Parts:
C1, C5, C6, C7, C8, C91, C93: 0.1uF; C_0402_1005Metric
C2: 0.1uF; C_0603_1608Metric
C3, C4: 12pF; C_0603_1608Metric
D1: LED Red; LED_0603_1608Metric
D2: LED Green; LED_0603_1608Metric
D4: 2A; D_SOD-323
F2: 1206L050; Fuse_1206_3216Metric
J1: USB_B_Micro; USB_Micro-B_Amphenol_10103594-0001LF_Horizontal
R1: 2K2; R_0603_1608Metric
R2, R3: 27R; R_0603_1608Metric
R4: 10K; R_0603_1608Metric
R5: 1K5; R_0603_1608Metric
R6: 470R; R_0603_1608Metric
R7, R8, R9: 68R; R_0603_1608Metric
R10, R11: 1K; R_0603_1608Metric
RV1: V5.5MLA0603H; R_0603_1608Metric
U2: 93CxxB; SOIC-8_3.9x4.9mm_P1.27mm
U3: FT2232D; LQFP-48_7x7mm_P0.5mm
Y1: 6MHz / 12pF; Crystal_SMD_7050-4Pin_7.0x5.0mm

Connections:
+5V: C1.1, C2.1, C5.1, C7.1, F2.1, R4.1, R6.1, RV1.1, U2.8 (VCC), U3.3 (VCC), U3.4 (~RESET), U3.42 (VCC); also elsewhere on the board
/hdmilight-v3-fpga/TDI: R8.1; also elsewhere on the board
/hdmilight-v3-microcontroller/JTCK: R7.1; also elsewhere on the board
/hdmilight-v3-microcontroller/JTDO: U3.22 (ADBUS2); also elsewhere on the board
/hdmilight-v3-microcontroller/JTMS: R9.2; also elsewhere on the board
/hdmilight-v3-microcontroller/RXD: U3.40 (BDBUS0); also elsewhere on the board
/hdmilight-v3-microcontroller/TXD: U3.39 (BDBUS1); also elsewhere on the board
GND: C1.2, C2.2, C3.2, C4.2, C5.2, C6.2, C7.2, C8.2, C91.2, C93.2, J1.5 (GND), RV1.2, U2.5 (GND), U3.9 (GND), U3.18 (GND), U3.25 (GND), U3.34 (GND), U3.45 (AGND), U3.47 (TEST), Y1.2, Y1.4; also elsewhere on the board
MCU_3V3: C91.1, C93.1, D1.2 (A), D2.2 (A), U3.10 (SI/WUA), U3.14 (VCCIOA), U3.26 (SI/WUB), U3.31 (VCCIOB); also elsewhere on the board
unnamed: C3.1, U3.43 (XTIN), Y1.1
unnamed: C4.1, U3.44 (XTOUT), Y1.3
unnamed: C6.1, U3.6 (3V3OUT)
unnamed: C8.1, R6.2, U3.46 (AVCC)
unnamed: D1.1 (K), R10.1
unnamed: D2.1 (K), R11.1
unnamed: D4.1 (K), F2.2
unnamed: D4.2 (A), J1.1 (VBUS)
unnamed: J1.2 (D-), R2.2
unnamed: J1.3 (D+), R3.2
unnamed: R1.1, U2.3 (DI), U3.2 (EEDATA)
unnamed: R1.2, R4.2, U2.4 (DO)
unnamed: R2.1, U3.8 (USBDM)
unnamed: R3.1, R5.2, U3.7 (USBDP)
unnamed: R5.1, U3.5 (~RSTOUT)
unnamed: R7.2, U3.24 (ADBUS0)
unnamed: R8.2, U3.23 (ADBUS1)
unnamed: R9.1, U3.21 (ADBUS3)
unnamed: R10.2, U3.28 (BCBUS2)
unnamed: R11.2, U3.27 (BCBUS3)
unnamed: U2.1 (CS), U3.48 (EECS)
unnamed: U2.2 (SCLK), U3.1 (EECLK)

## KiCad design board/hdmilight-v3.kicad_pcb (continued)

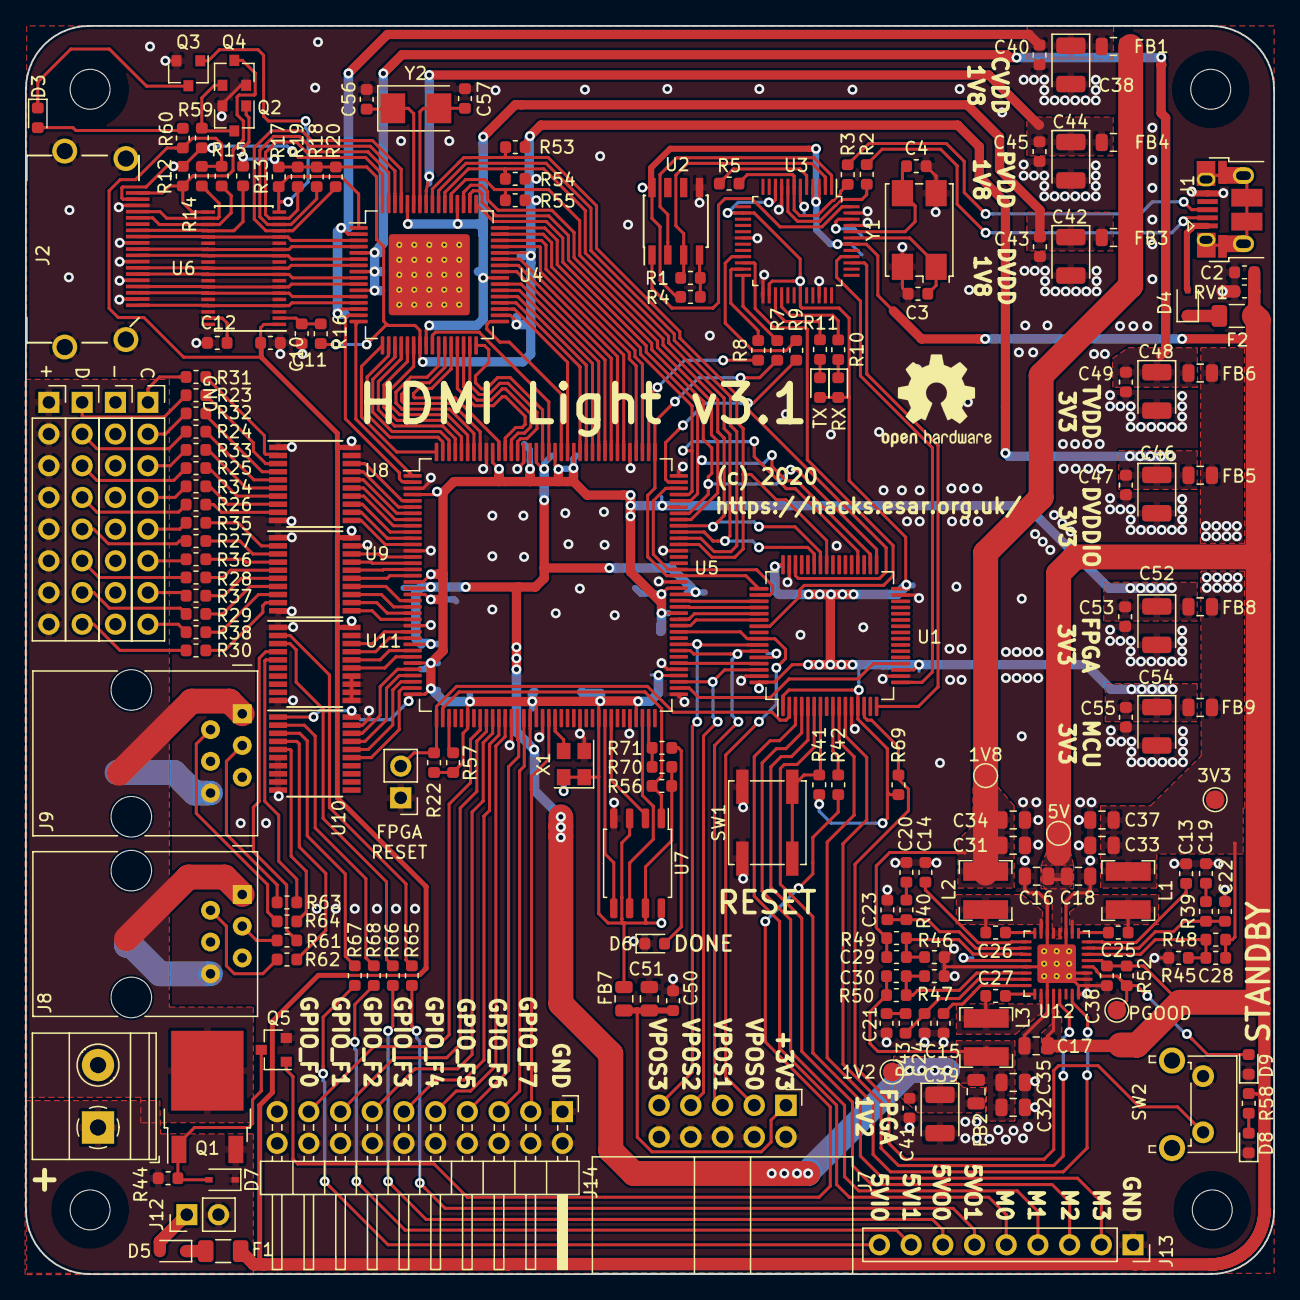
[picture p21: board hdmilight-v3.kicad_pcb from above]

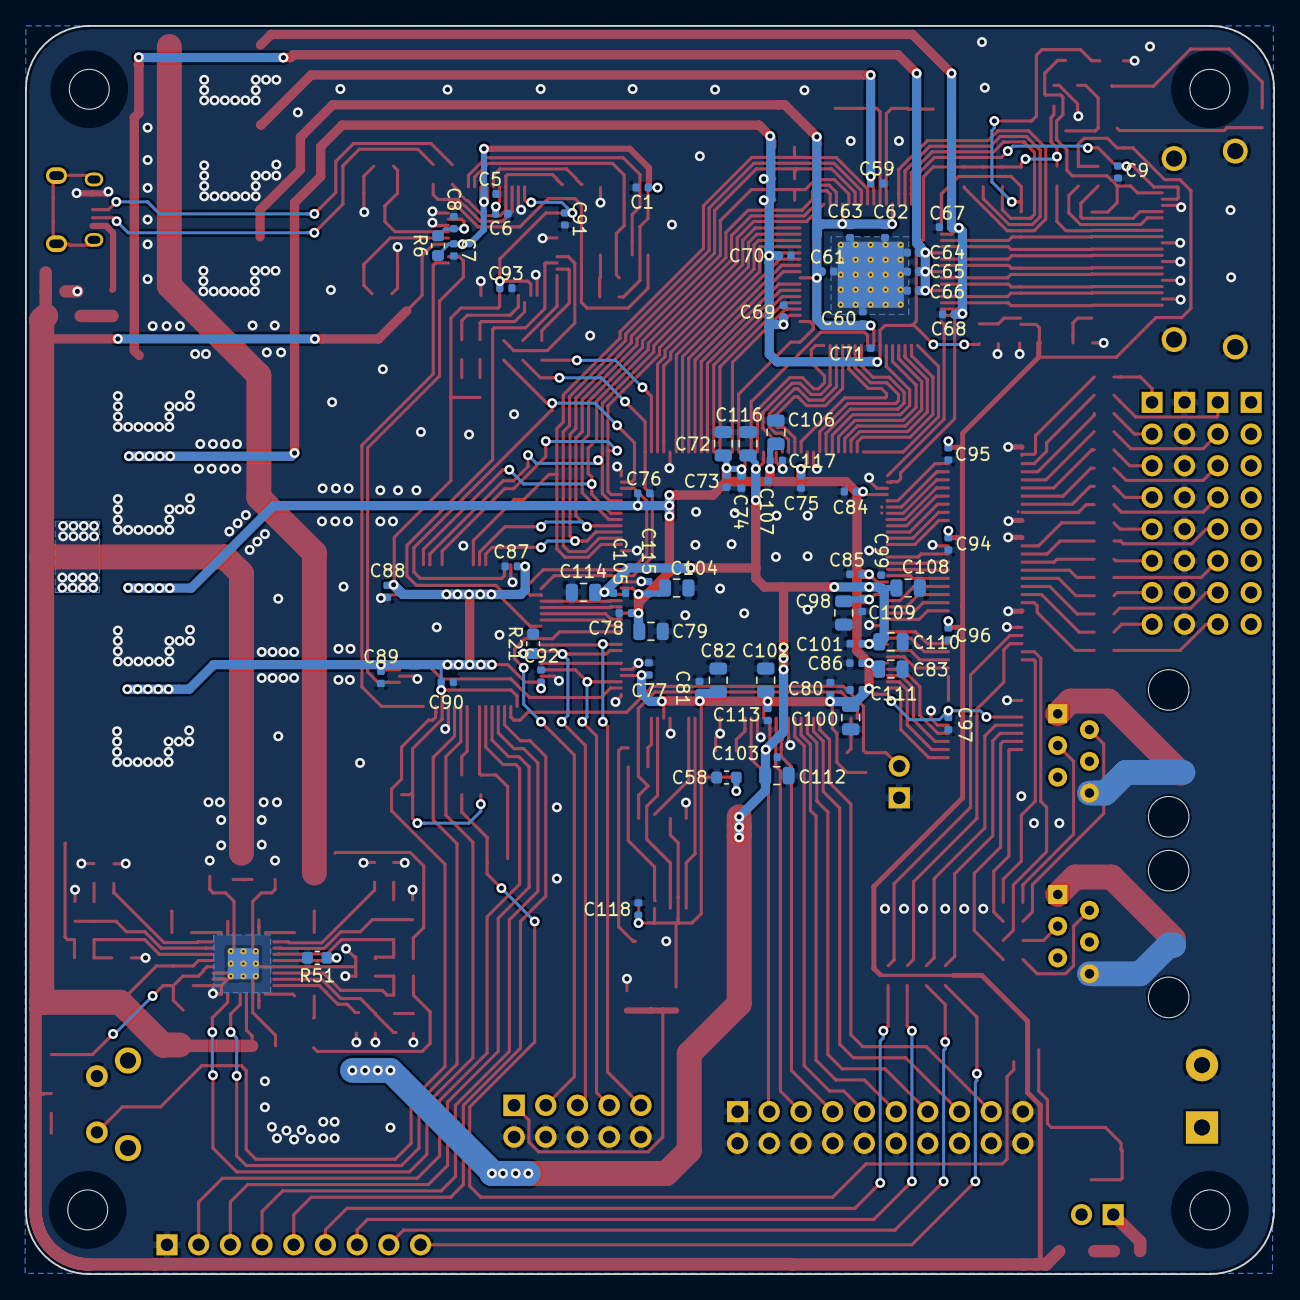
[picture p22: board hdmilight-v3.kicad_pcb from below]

Board: 2 copper layers, 100.0 x 100.0 mm, 259 parts (70 on the bottom side), 239 nets.

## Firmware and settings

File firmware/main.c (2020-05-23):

/*

   Copyright (C) 2013 Stephen Robinson
  
   This file is part of HDMI-Light
  
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
*/

#include <inttypes.h>
#include <string.h>
#include <stm32f303x8.h>
#include <core_cm4.h>
#include "printf.h"
#include "ambilight.h"
#include "clock.h"
#include "uart.h"
#include "papix/pos_sensors.h"


// If this line is commented out, the ADV7611 will not be started
// at power on and HDMI handshaking will not occur, in which case "R"
// needs to be run from the serial console to start the ADV7611
#define AUTO_INITIALIZATION

// Uncomment to enable power on/off via physical switch.
// Requires a pull-up resistor and switch to be added.
//#define ENABLE_POWER_SWITCH

#define BELL    '\a'


uint8_t silent = 0;
volatile uint8_t g_formatChanged = 0;
volatile uint8_t g_cecMessage[16];
volatile uint8_t g_cecMessageLength;

int __errno;



// Print a section of the ring buffer to stdout, wrapping around when passing the end.
// Also replacing NULLs with spaces as old commands have had spaces replaced with NULLs
// when they were being split into args
void ringBufPrint(char* buf, uint8_t pos, int len)
{
	while(len--)
	{
		if(buf[pos] == '\0')
			_putchar(' ');
		else
			_putchar(buf[pos]);
		++pos;
	}
}

void ringBufCopy(char* buf, uint8_t dst, uint8_t src, int len)
{
	while(len--)
		buf[dst++] = buf[src++];
}

void ringBufCopyReverse(char* buf, uint8_t dst, uint8_t src, int len)
{
	dst += len;
	src += len;
	while(len--)
		buf[--dst] = buf[--src];
}

#define ESCAPE_STATE_NONE    0
#define ESCAPE_STATE_BRACKET 1
#define ESCAPE_STATE_CHAR    2

#define UP    0x100
#define DOWN  0x101
#define RIGHT 0x102
#define LEFT  0x103

char pollCommand(char** argv, char maxargs)
{
	static char cmdbuf[256] = {0, 0};
	static unsigned char current = 0;
	static unsigned char history = 0;
	static unsigned char pos = 1;
	static unsigned char end = 1;
	static uint8_t escapeState = ESCAPE_STATE_NONE;

	int c = _getchar();
	if(c == -1)
		return 0;
	
	switch(escapeState)
	{
		case ESCAPE_STATE_NONE:
			if(c == 0x1B)
				escapeState = ESCAPE_STATE_BRACKET;
			break;
		case ESCAPE_STATE_BRACKET:
			if(c == '[')
				escapeState = ESCAPE_STATE_CHAR;
			else
				escapeState = ESCAPE_STATE_NONE;
			break;
		case ESCAPE_STATE_CHAR:
			switch(c)
			{
				case 'A': c = UP;    break;
				case 'B': c = DOWN;  break;
				case 'C': c = RIGHT; break;
				case 'D': c = LEFT;  break;
			}
			escapeState = ESCAPE_STATE_NONE;
			break;
	}

	if(escapeState == ESCAPE_STATE_NONE)
	{
		switch(c)
		{
			case LEFT:
			case 0x02: // left
				if(pos - 1 != current)
				{
					--pos;
					printf("\x1B[D"); // move left
				}
				else
					_putchar(BELL);
				break;
			case 0x08: // backspace
			case 0x7f:
				if(pos > 0)
				{
					// move partial line left in buffer to fill hole
					ringBufCopy(cmdbuf, pos - 1, pos, end - pos);
					--pos; --end;

					// move cursor left one place and print the partial line
					printf("\x1B[D");
					ringBufPrint(cmdbuf, pos, end - pos);

					// move the cursor left, back to the edit position
					printf(" \x1B[%dD", end - pos + 1);
				}
				else
					_putchar(BELL);
				break;
			case RIGHT:
			case 0x06: // right
				if(pos + 1 != end)
				{
					++pos;
					printf("\x1B[C"); // move right
				}
				else
					_putchar(BELL);
				break;
			case '\n':
			case '\r':
				break;
			case UP:
			case 0x10:
				if(1)
				{
					unsigned char p = current;
					unsigned char len = 0;
					unsigned char i;

					for(i = 0; i < history + 1; ++i)
					{
						len = cmdbuf[p];
						if(len == 0)
							break;
						p -= len;
					}
					if(i == history + 1)
					{
						++history;

						// lines in the history are NULL terminated, remove the termination
						--len;

						// copy the old line into the current position in the buffer
						ringBufCopy(cmdbuf, current + 1, p + 1, len - 1);
						cmdbuf[current + len] = '\0';

						// move the cursor to the beginning of the line and print the copied line
						printf(" \x1B[%dD", pos - current);
						ringBufPrint(cmdbuf, current + 1, len - 1);

						// if the copied line is shorter then overwrite any extra characters with spaces
						if(end - (current + len) > 0)
						{
							for(i = 0; i < end - (current + len); ++i)
								_putchar(' ');
							printf("\x1B[%dD", end - (current + len));
						}
						end = current + len;
						pos = end;
					}
					else
						_putchar(BELL);
				}
				break;
			case DOWN:
			case 0x0E:
				if(history > 1)
				{
					unsigned char p = current;
					unsigned char len;
					unsigned char i;

					--history;
					for(i = 0; i < history; ++i)
					{
						len = cmdbuf[p];
						if(len == 0)
							break;
						p -= len;
					}

					// the lines in the history are NULL terminated, remove the termination
					--len;

					// copy the old line to the current position in the buffer
					ringBufCopy(cmdbuf, current + 1, p + 1, len - 1);
					cmdbuf[current + len] = '\0';

					// move the cursor to the beginning of the line and print the copied line
					printf(" \x1B[%dD", pos - current);
					ringBufPrint(cmdbuf, current + 1, len - 1);

					// if the copied line is shorter then overwrite the extra characters with spaces
					if(end - (current + len) > 0)
					{
						for(i = 0; i < end - (current + len); ++i)
							_putchar(' ');
						printf("\x1B[%dD", end - (current + len));
					}
					end = current + len;
					pos = end;
				}
				else if(history == 1)
				{
				}
				else
					_putchar(BELL);
				break;
			default:
				if(end + 1 != current)
				{
					// copy any characters after the current edit point to the right to make room
					ringBufCopyReverse(cmdbuf, pos + 1, pos, end - pos);

					// add the new character
					cmdbuf[pos] = c;

					// print the buffer from the current edit point to the end
					ringBufPrint(cmdbuf, pos, end - pos + 1);

					// move the cursor back to the edit point
					printf(" \x1B[%dD", end - pos + 1);
					++pos;
					++end;

				}
				else
					_putchar(BELL);
				break;
		}
	}

	if(c == '\n' || c == '\r')
	{
		unsigned char arg;

		// if the current line wraps around the end of the buffer then rotate the
		// buffer so that the line is all in one piece
		if(end < current)
		{
			uint8_t offset = 0x100 - current;
			ringBufCopyReverse(cmdbuf, end + offset, end, 0x100);
			pos += offset;
			end += offset;
			current += offset;
		}

		// NULL terminate the current line
		cmdbuf[end] = '\0';

		// split the line into args
		pos = current + 1;
		for(arg = 0; arg < maxargs; ++arg)
		{
			if(pos == end)
				break; 

			while((cmdbuf[pos] == ' ' || cmdbuf[pos] == '\0') && pos != end)
				cmdbuf[pos++] = '\0';

			argv[arg] = cmdbuf + pos;

			while(cmdbuf[pos] != ' ' && cmdbuf[pos] != '\0' && pos != end)
				++pos;
		}
		
		// account for added NULL termination of the line
		++end;

		// store the length of the line for history navigation
		cmdbuf[end] = end - current;

		// setup ready for the next line
		cmdbuf[end + 1] = '\0';
		current = end;
		
		history = 0;
		pos = current + 1;
		end = current + 1;

		return arg;
	}

	return 0;
}

int getint(char** str)
{
	char* s = *str;
	uint8_t neg = 0;
	uint16_t x = 0;

	if(s[0] == '-')
	{
		neg = 1;
		++s;
	}

	if(s[0] == '0' && s[1] == 'x')
	{
		s += 2;
		while(1)
		{
			if(*s >= '0' && *s <= '9')
				x = (x << 4) + (*s - '0');
			else if(*s >= 'A' && *s <= 'F')
				x = (x << 4) + (*s - 'A' + 10);
			else if(*s >= 'a' && *s <= 'f')
				x = (x << 4) + (*s - 'a' + 10);
			else
				break;
			++s;
		}
	}
	else
	{
		while(*s >= '0' && *s <= '9')
			x = (x * 10) + (*s++ - '0');
	}
	
	*str = s;
	return neg ? 0 - x : x;
}

void getrange(char* str, uint8_t* min, uint8_t* max)
{
	if(*str == '*')
	{
		*min = 0;
		*max = 255;
		return;
	}
	else
	{
		*min = getint(&str);
		if(*str == '-')
		{
			++str;
			*max = getint(&str);
		}
		else
			*max = *min;
	}
}

void cmdRstAll(uint8_t argc, char** argv)
{
	cmdRstI2C(argc, argv);
	cmdRstArea(argc, argv);
	cmdRstColour(argc, argv);
	cmdRstGamma(argc, argv);
	cmdRstOutput(argc, argv);
	cmdRstDelay(argc, argv);
}

const struct
{
	const char* cmd;
	void (*handler)(uint8_t argc, char** argv);
	const char* usage;

} cmds[] = 
{
	{ "GA", cmdGetArea,   "Get Area:    GA index"   },
	{ "SA", cmdSetArea,   "Set Area:    SA index xmin xmax ymin ymax shift output"   },
	{ "RA", cmdRstArea,   "Rst Area:    RA"   },
	{ "GC", cmdGetColour, "Get Colour:  GC index row" },
	{ "SC", cmdSetColour, "Set Colour:  SC index row r g b" },
	{ "RC", cmdRstColour, "Rst Colour:  RC" },
	{ "GD", cmdGetDelay,  "Get Delay:   GD"  },
	{ "SD", cmdSetDelay,  "Set Delay:   SD num_frames num_ticks smooth_ratio"  },
	{ "RD", cmdRstDelay,  "Rst Delay:   RD"  },
	{ "DF", cmdDisFormat, "Dis Format:  DF" },
	{ "EF", cmdEnaFormat, "Ena Format:  EF" },
	{ "GF", cmdGetFormat, "Get Format:  GF" },
	{ "GG", cmdGetGamma,  "Get Gamma:   GG table channel index"  },
	{ "SG", cmdSetGamma,  "Set Gamma:   SG table channel index value"  },
	{ "RG", cmdRstGamma,  "Rst Gamma:   RG"  },
	{ "GI", cmdGetI2C,    "Get I2C:     GI addr sub_addr [bit_range]"    },
	{ "SI", cmdSetI2C,    "Set I2C:     SI addr sub_addr value"    },
	{ "RI", cmdRstI2C,    "Rst I2C:     RI"    },
	{ "SK", cmdSetKeys,   "Set Keys:    SK key_code"   },
	{ "RK", cmdRstKeys,   "Rst Keys:    RK"   },
	{ "GM", cmdGetMem,    "Get Memory:  GM index"    },
	{ "GO", cmdGetOutput, "Get Output:  GO output light" },
	{ "SO", cmdSetOutput, "Set Output:  SO output light area coef gamma enable" },
	{ "RO", cmdRstOutput, "Rst Output:  RO" },
	{ "GR", cmdGetResult, "Get Result:  GR index" },
	{ "GS", cmdGetStatus, "Get Status:  GS" },
	{ "SS", cmdSetStatus, "Set Status:  SS interrupt_mask" },
	{ "GX", cmdGetAddr,   "Get Address: GX addr count"   },
	{ "SX", cmdSetAddr,   "Set Address: SX addr byte0 [byte1] [...]"  },
	{ "R",  cmdRstAll,    "Rst All:     R"    },
};

void dispatchCommand(int argc, char** argv)
{
	int i;

	if(argc > 0)
	{
		if(strcmp(argv[0], "?") == 0)
		{
			for(i = 0; i < sizeof(cmds) / sizeof(*cmds); ++i)
				printf("%s\n", cmds[i].usage);
		}
		else
		{
			for(i = 0; i < sizeof(cmds) / sizeof(*cmds); ++i)
			{
				if(strcmp(argv[0], cmds[i].cmd) == 0)
				{
					if(argc == 2 && strcmp(argv[1], "?") == 0)
						printf("%s\n", cmds[i].usage);
					else
						cmds[i].handler(argc, argv);
					break;
				}
			}

			if(i >= sizeof(cmds) / sizeof(*cmds))
				printf("err\n");
		}
	}

}

__STATIC_INLINE uint32_t NVIC_GetEnableIRQ(IRQn_Type IRQn)
{
	if ((int32_t)(IRQn) >= 0)
	{
		return((uint32_t)(((NVIC->ISER[(((uint32_t)(int32_t)IRQn) >> 5UL)] & (1UL << (((uint32_t)(int32_t)IRQn) & 0x1FUL))) != 0UL) ? 1UL : 0UL));
	}
	else
	{
		return(0U);
	}
}

void EXTI2_TSC_IRQHandler()
{
	uint8_t interrupts;
	uint8_t clear = 0xff;

	EXTI->PR |= EXTI_PR_PR2;

	fpgaConfigRead(AMBILIGHT_BASE_ADDR_INTERRUPT, &interrupts, sizeof(interrupts));

	if(interrupts & 1)
	{
		uint8_t cecRxIntState = adv7611ReadRegister(0x98, 0x93);

		// if this is a CEC RX message 0 ready interupt
		if(cecRxIntState & 8)
		{
			int i;

			// copy the received message
			g_cecMessageLength = adv7611ReadRegister(0x80, 0x25);
			if(g_cecMessageLength > sizeof(g_cecMessage))
				g_cecMessageLength = sizeof(g_cecMessage);
			for(i = 0; i < g_cecMessageLength; ++i)
				g_cecMessage[i] = adv7611ReadRegister(0x80, 0x15 + i);

			// clear the message buffer ready for a new message
			adv7611WriteRegister(0x80, 0x2C, 0x02);

			// clear the interrupt
			adv7611WriteRegister(0x98, 0x94, 0x08);
		}
	}
	else if(interrupts & 2)
	{
		g_formatChanged = 1;
	}

	fpgaConfigWrite(AMBILIGHT_BASE_ADDR_INTERRUPT, &clear, sizeof(clear));
}

void intPoll()
{
	uint8_t interrupts;

	fpgaConfigRead(AMBILIGHT_BASE_ADDR_INTERRUPT, &interrupts, sizeof(interrupts));

	if(NVIC_GetEnableIRQ(EXTI2_TSC_IRQn) &&   // interrupt enabled
	   !(EXTI->PR & EXTI_PR_PR2) &&           // interrupt not pending
	   interrupts != 0xff &&                  // FPGA responding (bitstream loaded)
	   (interrupts & 0x0F))                   // FPGA indicating interrupt pending
	{
		EXTI2_TSC_IRQHandler();	
	}
}

void intInit()
{
	RCC->AHBENR |= RCC_AHBENR_GPIODEN;
	GPIOD->MODER &= ~GPIO_MODER_MODER2;
	GPIOD->PUPDR &= ~GPIO_PUPDR_PUPDR2;

	RCC->APB2ENR |= RCC_APB2ENR_SYSCFGEN;
	SYSCFG->EXTICR[0] &= ~SYSCFG_EXTICR1_EXTI2_Msk;
	SYSCFG->EXTICR[0] |= SYSCFG_EXTICR1_EXTI2_PD;
	
	EXTI->IMR |=  1 << 2;           // enable EXTI2
	EXTI->RTSR |= EXTI_RTSR_TR2;    // enable rising edge
	EXTI->FTSR &= ~EXTI_FTSR_TR2;   // disable falling edge

	NVIC_SetPriority(EXTI2_TSC_IRQn, INT_PRIORITY_DEVICE_COMMS);
	NVIC_EnableIRQ(EXTI2_TSC_IRQn);
}

void intSuspend()
{
	NVIC_DisableIRQ(EXTI2_TSC_IRQn);
}

void intResume()
{
	NVIC_EnableIRQ(EXTI2_TSC_IRQn);
}


void init()
{
	clockInit();
	powerInit();
	uartInit(115200);
	printf("Starting...\n");
	adv7611Init();
	fpgaInit();
	intInit();
	//posSensorsInit();
	standbyInit();
}

void suspend()
{
	intSuspend();
	fpgaSuspend();
	adv7611Suspend();
	formatSuspend();

	powerLEDOff();
	power1V2Off();
	//power1V8Off();
}

void resume()
{
	power1V8On();
	power1V2On();

	formatResume();
	adv7611Resume();
	fpgaResume();

	intResume();

	// Load FPGA ambilight config
	//fpgaConfigLoad(0);  // TODO: use correct config

	powerLEDOn();
}

int main()
{
	//int i;
	//sensor_angle_set_t* angles;

	char* argv[12];
	int argc;
	uint32_t lastTime = 0;

	init();


//uint8_t printit=0;

	printf("Entering main loop\r\n");
	printf("\n> ");
	while(1)
	{
		standbyPoll();

		// STM32 doesn't support level triggered interrupts
		// Check for any missed rising edges every 250ms
		if(lastTime + 250 < clockGetTicks())
		{
			lastTime = clockGetTicks();
			intPoll();
		}

		if(g_formatChanged)
		{
			g_formatChanged = 0;
			formatChange();
		}

		if(g_cecMessageLength != 0)
		{
			// TODO: replacement for disabling interrupts to ensure that
			//       the message isn't overwritten while we're processing it
			processCecMessage();
			g_cecMessageLength = 0;
		}

		if((argc = pollCommand(argv, 12)))
		{
			printf("\n");
			dispatchCommand(argc, argv);
			printf("\n> ");
//printit=1;
		}

/*
		if((angles = posSensorsPoll()))
		{
/-*
printf("angles0: %f %f %f %f\n", (*angles)[0][0][0], (*angles)[0][0][1], (*angles)[0][1][0], (*angles)[0][1][1]);
printf("angles1: %f %f %f %f\n", (*angles)[1][0][0], (*angles)[1][0][1], (*angles)[1][1][0], (*angles)[1][1][1]);
printf("angles2: %f %f %f %f\n", (*angles)[2][0][0], (*angles)[2][0][1], (*angles)[2][1][0], (*angles)[2][1][1]);
printf("angles3: %f %f %f %f\n", (*angles)[3][0][0], (*angles)[3][0][1], (*angles)[3][1][0], (*angles)[3][1][1]);
printf("\n");
*-/
//printf("got angles\n");
			ootx_msg_t* ootx = posSensorsGetOotx();
			if(ootx)
			{
//printf("got ootx\n");
if(printit)
{
				lighthouse_solution_t solution;
				solveLighthouse(&solution, *angles, ootx);
//static int count = 0;
//if(count++ % 100 == 0)
{
solution_error_t error;

	printf("L:%u,%f,%f,%f,%f,%f,%f,%f,%f,%f,%f,%f,%f\r\n", 0,
	       (float)solution.lighthouses[0].origin[0],
	       (float)solution.lighthouses[0].origin[1],
	       (float)solution.lighthouses[0].origin[2],
	       (float)solution.lighthouses[0].rotationMatrix[0],
	       (float)solution.lighthouses[0].rotationMatrix[1],
	       (float)solution.lighthouses[0].rotationMatrix[2],
	       (float)solution.lighthouses[0].rotationMatrix[3],
	       (float)solution.lighthouses[0].rotationMatrix[4],
	       (float)solution.lighthouses[0].rotationMatrix[5],
	       (float)solution.lighthouses[0].rotationMatrix[6],
	       (float)solution.lighthouses[0].rotationMatrix[7],
	       (float)solution.lighthouses[0].rotationMatrix[8]);
	printf("L:%u,%f,%f,%f,%f,%f,%f,%f,%f,%f,%f,%f,%f\r\n", 1,
	       (float)solution.lighthouses[1].origin[0],
	       (float)solution.lighthouses[1].origin[1],
	       (float)solution.lighthouses[1].origin[2],
	       (float)solution.lighthouses[1].rotationMatrix[0],
	       (float)solution.lighthouses[1].rotationMatrix[1],
	       (float)solution.lighthouses[1].rotationMatrix[2],
	       (float)solution.lighthouses[1].rotationMatrix[3],
	       (float)solution.lighthouses[1].rotationMatrix[4],
	       (float)solution.lighthouses[1].rotationMatrix[5],
	       (float)solution.lighthouses[1].rotationMatrix[6],
	       (float)solution.lighthouses[1].rotationMatrix[7],
	       (float)solution.lighthouses[1].rotationMatrix[8]);
	calcSolutionErrorFromSensorAngles(&solution, *angles, &error);
	printf("err: %f vs %f\r\n", solution.lighthouses[0].error.total, error.total);
printit=0;
}
}
			}

		}
*/
	}
}

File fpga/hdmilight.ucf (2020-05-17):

## Prohibit the automatic placement of pins that are connected to VCC or GND for configuration.
CONFIG PROHIBIT=P69;
CONFIG PROHIBIT=P60;

# Crystal Clock - use 32MHz onboard oscillator
NET "CLK" LOC = "P56" | IOSTANDARD = LVTTL | PERIOD = 31.25ns ;

NET "ADV_AP" LOC = "P105" | IOSTANDARD = LVTTL;
NET "ADV_SCLK" LOC = "P104" | IOSTANDARD = LVTTL;
NET "ADV_LRCLK" LOC = "P102" | IOSTANDARD = LVTTL;
NET "ADV_MCLK" LOC = "P101" | IOSTANDARD = LVTTL;

NET "ADV_SCL" LOC = "P100" | IOSTANDARD = LVCMOS33;
NET "ADV_SDA" LOC = "P99" | IOSTANDARD = LVCMOS33;
NET "ADV_INT1" LOC = "P98" | IOSTANDARD = LVCMOS33;
NET "ADV_RST" LOC = "P97" | IOSTANDARD = LVCMOS33;

NET "ADV_HS" LOC = "P112" | IOSTANDARD = LVTTL;
NET "ADV_VS" LOC = "P111" | IOSTANDARD = LVTTL;
NET "ADV_DE" LOC = "P114" | IOSTANDARD = LVTTL;
NET "ADV_LLC" LOC = "P126" | IOSTANDARD = LVCMOS33;

NET "ADV_P<0>" LOC = "P115" | IOSTANDARD = LVCMOS33;
NET "ADV_P<1>" LOC = "P116" | IOSTANDARD = LVCMOS33;
NET "ADV_P<2>" LOC = "P117" | IOSTANDARD = LVCMOS33;
NET "ADV_P<3>" LOC = "P118" | IOSTANDARD = LVCMOS33;
NET "ADV_P<4>" LOC = "P119" | IOSTANDARD = LVCMOS33;
NET "ADV_P<5>" LOC = "P120" | IOSTANDARD = LVCMOS33;
NET "ADV_P<6>" LOC = "P121" | IOSTANDARD = LVCMOS33;
NET "ADV_P<7>" LOC = "P123" | IOSTANDARD = LVCMOS33;
NET "ADV_P<8>" LOC = "P124" | IOSTANDARD = LVCMOS33;
NET "ADV_P<9>" LOC = "P127" | IOSTANDARD = LVCMOS33;
NET "ADV_P<10>" LOC = "P131" | IOSTANDARD = LVCMOS33;
NET "ADV_P<11>" LOC = "P132" | IOSTANDARD = LVCMOS33;
NET "ADV_P<12>" LOC = "P133" | IOSTANDARD = LVCMOS33;
NET "ADV_P<13>" LOC = "P134" | IOSTANDARD = LVCMOS33;
NET "ADV_P<14>" LOC = "P137" | IOSTANDARD = LVCMOS33;
NET "ADV_P<15>" LOC = "P138" | IOSTANDARD = LVCMOS33;
NET "ADV_P<16>" LOC = "P139" | IOSTANDARD = LVCMOS33;
NET "ADV_P<17>" LOC = "P140" | IOSTANDARD = LVCMOS33;
NET "ADV_P<18>" LOC = "P141" | IOSTANDARD = LVCMOS33;
NET "ADV_P<19>" LOC = "P142" | IOSTANDARD = LVCMOS33;
NET "ADV_P<20>" LOC = "P143" | IOSTANDARD = LVCMOS33;
NET "ADV_P<21>" LOC = "P144" | IOSTANDARD = LVCMOS33;
NET "ADV_P<22>" LOC = "P1" | IOSTANDARD = LVCMOS33;
NET "ADV_P<23>" LOC = "P2" | IOSTANDARD = LVCMOS33;

NET "LED_OUT<0>" LOC = "P6" | IOSTANDARD = LVCMOS33 | DRIVE = 2 | SLEW = SLOW;
NET "LED_OUT<1>" LOC = "P8" | IOSTANDARD = LVCMOS33 | DRIVE = 2 | SLEW = SLOW;
NET "LED_OUT<2>" LOC = "P10" | IOSTANDARD = LVCMOS33 | DRIVE = 2 | SLEW = SLOW;
NET "LED_OUT<3>" LOC = "P12" | IOSTANDARD = LVCMOS33 | DRIVE = 2 | SLEW = SLOW;
NET "LED_OUT<4>" LOC = "P15" | IOSTANDARD = LVCMOS33 | DRIVE = 2 | SLEW = SLOW;
NET "LED_OUT<5>" LOC = "P17" | IOSTANDARD = LVCMOS33 | DRIVE = 2 | SLEW = SLOW;
NET "LED_OUT<6>" LOC = "P22" | IOSTANDARD = LVCMOS33 | DRIVE = 2 | SLEW = SLOW;
NET "LED_OUT<7>" LOC = "P24" | IOSTANDARD = LVCMOS33 | DRIVE = 2 | SLEW = SLOW;

NET "LED_CLK<0>" LOC = "P5"  | IOSTANDARD = LVCMOS33 | DRIVE = 2 | SLEW = SLOW;
NET "LED_CLK<1>" LOC = "P7" | IOSTANDARD = LVCMOS33 | DRIVE = 2 | SLEW = SLOW;
NET "LED_CLK<2>" LOC = "P9" | IOSTANDARD = LVCMOS33 | DRIVE = 2 | SLEW = SLOW;
NET "LED_CLK<3>" LOC = "P11" | IOSTANDARD = LVCMOS33 | DRIVE = 2 | SLEW = SLOW;
NET "LED_CLK<4>" LOC = "P14" | IOSTANDARD = LVCMOS33 | DRIVE = 2 | SLEW = SLOW;
NET "LED_CLK<5>" LOC = "P16" | IOSTANDARD = LVCMOS33 | DRIVE = 2 | SLEW = SLOW;
NET "LED_CLK<6>" LOC = "P21" | IOSTANDARD = LVCMOS33 | DRIVE = 2 | SLEW = SLOW;
NET "LED_CLK<7>" LOC = "P23" | IOSTANDARD = LVCMOS33 | DRIVE = 2 | SLEW = SLOW;

NET FLASH_CS LOC="P38"  | IOSTANDARD=LVTTL | DRIVE=8 | SLEW=FAST;
NET FLASH_CK LOC="P70"  | IOSTANDARD=LVTTL | DRIVE=8 | SLEW=FAST;
NET FLASH_SI LOC="P64"  | IOSTANDARD=LVTTL | DRIVE=8 | SLEW=FAST;
NET FLASH_SO LOC="P65"  | IOSTANDARD=LVTTL | DRIVE=8 | SLEW=FAST | PULLUP;

NET "MCU_SPI_CLK" LOC = "P88" | IOSTANDARD = LVCMOS33;
NET "MCU_SPI_MISO" LOC = "P87" | IOSTANDARD = LVCMOS33;
NET "MCU_SPI_MOSI" LOC = "P85" | IOSTANDARD = LVCMOS33;
NET "MCU_SPI_CS" LOC = "P74" | IOSTANDARD = LVCMOS33;

NET "MCU_PD2" LOC = "P84" | IOSTANDARD = LVCMOS33;
NET "MCU_PB8" LOC = "P78" | IOSTANDARD = LVCMOS33;

NET "VIVEPOS_SENSOR<0>" LOC = "P83";
NET "VIVEPOS_SENSOR<1>" LOC = "P80";
NET "VIVEPOS_SENSOR<2>" LOC = "P75";
NET "VIVEPOS_SENSOR<3>" LOC = "P81";

NET "PAPIX_POS<0>" LOC = "P34";
NET "PAPIX_POS<1>" LOC = "P35";

NET "PAPIX_RGB<0>" LOC = "P29" | IOSTANDARD=LVCMOS33;
NET "PAPIX_RGB<1>" LOC = "P30" | IOSTANDARD=LVCMOS33;

NET "IN5V<0>" LOC = "P33";
NET "IN5V<1>" LOC = "P32";

NET "OUT5V<0>" LOC = "P26" | IOSTANDARD=LVCMOS33;
NET "OUT5V<1>" LOC = "P27" | IOSTANDARD=LVCMOS33;

NET "GPIO<0>" LOC = "P44" | IOSTANDARD = LVCMOS33;
NET "GPIO<1>" LOC = "P45" | IOSTANDARD = LVCMOS33;
NET "GPIO<2>" LOC = "P46" | IOSTANDARD = LVCMOS33;
NET "GPIO<3>" LOC = "P47" | IOSTANDARD = LVCMOS33;
NET "GPIO<4>" LOC = "P48" | IOSTANDARD = LVCMOS33;
NET "GPIO<5>" LOC = "P50" | IOSTANDARD = LVCMOS33;
NET "GPIO<6>" LOC = "P51" | IOSTANDARD = LVCMOS33;
NET "GPIO<7>" LOC = "P55" | IOSTANDARD = LVCMOS33;

NET "ROUTE_UNDER<0>" LOC = "P93"; // JTAG_TDO
NET "ROUTE_UNDER<1>" LOC = "P92"; // JTAG_TCK


NET "ADV_LLC" TNM_NET = "ADV_LLC";
TIMESPEC "TS_ADV_LLC" = PERIOD "ADV_LLC" 6 ns HIGH 50%;
NET "ADV_P<0>" OFFSET = IN 2.7 ns VALID 3.5 ns BEFORE "ADV_LLC" RISING;
NET "ADV_P<1>" OFFSET = IN 2.7 ns VALID 3.5 ns BEFORE "ADV_LLC" RISING;
NET "ADV_P<2>" OFFSET = IN 2.7 ns VALID 3.5 ns BEFORE "ADV_LLC" RISING;
NET "ADV_P<3>" OFFSET = IN 2.7 ns VALID 3.5 ns BEFORE "ADV_LLC" RISING;
NET "ADV_P<4>" OFFSET = IN 2.7 ns VALID 3.5 ns BEFORE "ADV_LLC" RISING;
NET "ADV_P<5>" OFFSET = IN 2.7 ns VALID 3.5 ns BEFORE "ADV_LLC" RISING;
NET "ADV_P<6>" OFFSET = IN 2.7 ns VALID 3.5 ns BEFORE "ADV_LLC" RISING;
NET "ADV_P<7>" OFFSET = IN 2.7 ns VALID 3.5 ns BEFORE "ADV_LLC" RISING;
NET "ADV_P<8>" OFFSET = IN 2.7 ns VALID 3.5 ns BEFORE "ADV_LLC" RISING;
NET "ADV_P<9>" OFFSET = IN 2.7 ns VALID 3.5 ns BEFORE "ADV_LLC" RISING;
NET "ADV_P<10>" OFFSET = IN 2.7 ns VALID 3.5 ns BEFORE "ADV_LLC" RISING;
NET "ADV_P<11>" OFFSET = IN 2.7 ns VALID 3.5 ns BEFORE "ADV_LLC" RISING;
NET "ADV_P<12>" OFFSET = IN 2.7 ns VALID 3.5 ns BEFORE "ADV_LLC" RISING;
NET "ADV_P<13>" OFFSET = IN 2.7 ns VALID 3.5 ns BEFORE "ADV_LLC" RISING;
NET "ADV_P<14>" OFFSET = IN 2.7 ns VALID 3.5 ns BEFORE "ADV_LLC" RISING;
NET "ADV_P<15>" OFFSET = IN 2.7 ns VALID 3.5 ns BEFORE "ADV_LLC" RISING;
NET "ADV_P<16>" OFFSET = IN 2.7 ns VALID 3.5 ns BEFORE "ADV_LLC" RISING;
NET "ADV_P<17>" OFFSET = IN 2.7 ns VALID 3.5 ns BEFORE "ADV_LLC" RISING;
NET "ADV_P<18>" OFFSET = IN 2.7 ns VALID 3.5 ns BEFORE "ADV_LLC" RISING;
NET "ADV_P<19>" OFFSET = IN 2.7 ns VALID 3.5 ns BEFORE "ADV_LLC" RISING;
NET "ADV_P<20>" OFFSET = IN 2.7 ns VALID 3.5 ns BEFORE "ADV_LLC" RISING;
NET "ADV_P<21>" OFFSET = IN 2.7 ns VALID 3.5 ns BEFORE "ADV_LLC" RISING;
NET "ADV_P<22>" OFFSET = IN 2.7 ns VALID 3.5 ns BEFORE "ADV_LLC" RISING;
NET "ADV_P<23>" OFFSET = IN 2.7 ns VALID 3.5 ns BEFORE "ADV_LLC" RISING;
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

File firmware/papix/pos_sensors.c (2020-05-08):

#include <stdint.h>
#include <stddef.h>
#include <stm32f303xe.h>
#include <core_cm4.h>
#include "printf.h"
#include "pos_sensors.h"



#define M_PI    3.14159265358979323846264338327950288

#define PULSE_TYPE_SYNC    0x00
#define PULSE_TYPE_SWEEP   0x10
#define PULSE_TYPE_INVALID 0xf0
#define PULSE_HAS_DATA(x)  (((x) & 0xf0) == 0)
#define PULSE_DATA_AXIS(x) ((x) & 1)
#define PULSE_DATA_DATA(x) (((x) >> 1) & 1)
#define PULSE_DATA_SKIP(x) (((x) >> 2) & 1)

#define ANGLE_INVALID      0xff

#define TICKS_PER_MICROSECOND    (7000000 / 1000000)
#define MICROSECONDS_IN_TICKS(x)  ((x) * TICKS_PER_MICROSECOND)

#define SWEEP_CENTER_IN_MICROSEC  4000
#define SWEEP_180_IN_MICROSEC     8333
#define SWEEP_CENTER_IN_TICKS     MICROSECONDS_IN_TICKS(SWEEP_CENTER_IN_MICROSEC)
#define SWEEP_180_IN_TICKS        MICROSECONDS_IN_TICKS(SWEEP_180_IN_MICROSEC)

#define NUM_SENSOR_ANGLE_SETS    2

static uint8_t g_angleCount = 0;
static volatile sensor_t g_sensors[NUM_SENSORS];
static lighthouse_solution_t g_solution;
static ootx_msg_t   g_lighthouseOotx[NUM_LIGHTHOUSES];

static uint8_t g_lastReadSensorAngleSet = 1;
static uint8_t g_currentSensorAngleSet = 0;
static sensor_angle_set_t g_sensorAngles[NUM_SENSOR_ANGLE_SETS];


// decodePulseWidth returns:
//     PULSE_TYPE_SWEEP (0x10)   for short sweep pulses
//     0x00 -> 0x07              for data from valid sync pulses
//     PULSE_TYPE_INVALID (0xf0) for pulses that are too long
//
// Pulse encoding info originally from: 
// https://github.com/nairol/LighthouseRedox/blob/master/docs/Light%20Emissions.md
//
// skip | data | axis |  length uS
// -----+------+------+-----------
//    0 |    0 |    0 |       62.5
//    0 |    0 |    1 |       72.9
//    0 |    1 |    0 |       83.3
//    0 |    1 |    1 |       93.8
//    1 |    0 |    0 |      104.0
//    1 |    0 |    1 |      115.0
//    1 |    1 |    0 |      125.0
//    1 |    1 |    1 |      135.0
//
// 10.4 uS between centers
//
uint8_t decodePulseWidth(int32_t width)
{
	uint8_t result;

	width = width - (uint16_t)((62.5 - (10.4/2)) * TICKS_PER_MICROSECOND);
	if(width < 0)
		return PULSE_TYPE_SWEEP;
	result = width / (uint16_t)(10.4 * TICKS_PER_MICROSECOND);
	if(result > 7)
		result = PULSE_TYPE_INVALID;
	return result;
}

void ootxAddBit(ootx_t* ootx, uint8_t bit)
{
	if((bit & 1) && ootx->shiftRegister == 0 && ootx->frameBit == 0)
	{
		// got preamble
		ootx->pos = 0;
		ootx->length = 0;
		ootx->shiftCount = 0;
	}
	else if(ootx->shiftCount == 17)
	{
		ootx->shiftCount = 0;
		if((bit & 1) == 0)// || ootx->frameBit == 0)
			ootx->length = 0xff;  // abort

		// end of word
		if(ootx->length == 0)
		{
			ootx->length = (ootx->shiftRegister << 8) | (ootx->shiftRegister >> 8);
			ootx->length += 2;  // add checksum to length
		}
		else if(ootx->length != 0xff)
		{
			if(ootx->pos < ootx->length && ootx->pos < sizeof(ootx->data))
			{
				ootx->data[ootx->pos++] = ootx->shiftRegister >> 8;
				ootx->data[ootx->pos++] = ootx->shiftRegister & 0xFF;
			}
			else
			{
				// TODO: validate checksum
				ootx->validLength = ootx->length;
				ootx->length = 0xff;
			}
		}
	}

	ootx->frameBit = ootx->shiftRegister >> 15;
	ootx->shiftRegister = (ootx->shiftRegister << 1) | ((bit & 1));
	ootx->shiftCount = (ootx->shiftCount + 1);
}

void sensorIrqHandler(volatile sensor_t* sensor, uint16_t riseTime, uint16_t fallTime)
{
	uint16_t width = fallTime - riseTime;
	uint8_t data = decodePulseWidth(width);


uint32_t index = ((uint32_t)sensor - (uint32_t)g_sensors) / sizeof(sensor_t);
	if(data == PULSE_TYPE_INVALID)
	{
		printf("LRG %u: %u %u %d\r\n", index, riseTime, fallTime, (int16_t)width);
		return;
	}

	if(data == PULSE_TYPE_SWEEP)
	{
//if(index == 1)
//	printf("SWP %u: %u %u %d\r\n", index, riseTime, fallTime, (int16_t)width);
		if(sensor->currentAngle == 0 && g_angleCount > NUM_SENSORS)
			g_angleCount = 1;
		else
			g_angleCount += 1;

		if(sensor->currentAngle < NUM_ANGLES)
		{
			uint16_t delta = riseTime - sensor->startTime;
			sensor->angleTicks[sensor->currentAngle >> 1][sensor->currentAngle & 1] += delta;
			sensor->angleTicks[sensor->currentAngle >> 1][sensor->currentAngle & 1] >>= 1;
			sensor->angleRadians[sensor->currentAngle >> 1][sensor->currentAngle & 1] = ((scalar_t)delta - SWEEP_CENTER_IN_TICKS) * (M_PI / SWEEP_180_IN_TICKS);
			sensor->currentAngle = ANGLE_INVALID;
		}


		if(g_angleCount == 16)
		{
			int i, j, k;
			for(i = 0; i < NUM_SENSORS; ++i)
				for(j = 0; j < NUM_LIGHTHOUSES; ++j)
					for(k = 0; k < NUM_AXES; ++k)
						g_sensorAngles[g_currentSensorAngleSet][i][j][k] = g_sensors[i].angleRadians[j][k];
			g_currentSensorAngleSet = (g_currentSensorAngleSet + 1) % NUM_SENSOR_ANGLE_SETS;
		}
	}
	else
	{
		uint16_t ticksSinceFirstPulse = riseTime - sensor->firstPulseTime;
		uint8_t lighthouse;

		if(ticksSinceFirstPulse >= MICROSECONDS_IN_TICKS(300) &&
		   ticksSinceFirstPulse <= MICROSECONDS_IN_TICKS(500))
		{
			lighthouse = 1;
			sensor->firstPulseTime = riseTime - MICROSECONDS_IN_TICKS(400);
		}
		else
		{
			// Doesn't fit timing of second lighthouse, so it's either the first
			// or we're out of sync and might as well consider it the first
			lighthouse = 0;
			sensor->firstPulseTime = riseTime;
		}

		if(!PULSE_DATA_SKIP(data))
		{
			sensor->currentAngle = (lighthouse << 1) | PULSE_DATA_AXIS(data);
			sensor->startTime = riseTime;
		}

		ootxAddBit(&sensor->ootx[lighthouse], PULSE_DATA_DATA(data));
	}
}

void TIM3_IRQHandler()
{
	if(TIM3->SR & TIM_SR_CC2IF)
		sensorIrqHandler(&g_sensors[0], TIM3->CCR1, TIM3->CCR2);
	if(TIM3->SR & TIM_SR_CC4IF)
		sensorIrqHandler(&g_sensors[1], TIM3->CCR3, TIM3->CCR4);
}

void TIM4_IRQHandler()
{
	if(TIM4->SR & TIM_SR_CC2IF)
		sensorIrqHandler(&g_sensors[3], TIM4->CCR1, TIM4->CCR2);
	if(TIM4->SR & TIM_SR_CC4IF)
		sensorIrqHandler(&g_sensors[2], TIM4->CCR3, TIM4->CCR4);
}

ootx_msg_t* posSensorsGetOotx()
{
	if(g_lighthouseOotx[0].isNew && g_lighthouseOotx[1].isNew)
		return g_lighthouseOotx;
	return NULL;
}

sensor_angle_set_t* posSensorsPoll()
{
	int i;
	uint16_t now = TIM3->CNT;
	static int call = 0;

	for(i = 0; i < NUM_SENSORS; ++i)
	{
		volatile sensor_t* sensor = &g_sensors[i];
		if(now - sensor->firstPulseTime > MICROSECONDS_IN_TICKS(8333 + 200))
		{
			// No pulse for more than 8333uS so move sensor->firstPulseTime
			// on by one cycle to try and stay locked while we're out of sight
			// of the lighthouses
			sensor->firstPulseTime += MICROSECONDS_IN_TICKS(8333);
		}
	}

	uint8_t sensorIndex;
	uint8_t lighthouseIndex;

	for(sensorIndex = 0; sensorIndex < NUM_SENSORS; ++sensorIndex)
	{
		for(lighthouseIndex = 0; lighthouseIndex < NUM_LIGHTHOUSES; ++lighthouseIndex)
		{
			ootx_t* ootx = &g_sensors[sensorIndex].ootx[lighthouseIndex];

			if(ootx->validLength)
			{
				g_lighthouseOotx[lighthouseIndex].length = ootx->validLength;
				memcpy(g_lighthouseOotx[lighthouseIndex].data, 
				       ootx->data, 
				       ootx->validLength);
				g_lighthouseOotx[lighthouseIndex].isNew = 1;
				ootx->validLength = 0;
			}
		}
	}
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

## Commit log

2019-11-01 Added first version of new all-in-one board
    [hdmilight-v3-fpga.sch, hdmilight-v3-hdmi.sch, hdmilight-v3-io.sch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]
2019-11-03 Updated FPGA constraints, removed embedded AVR, added SPI access to config RAM
2019-11-14 Ported firmware to ARM (STM32F303RE) using SPI interface to FPGA
    [hdmilight-v3-openocd.cfg]
2020-05-08 Fixed bugs in v3.0 board:
    * Changed FPGA GPIO to 2 row with ground to make it compatible with logic analyser plug for debugging
    * Move position sensor from PB4 to PB5
    * Connect voltage regulator center pad to ground pins
    * Add SPI CS line between FPGA and MCU
    * Move HDMI hotplug LED back from board edge
    * Move HDMI ESD chip closer to connector
    * Swap serial rx/tx
    * Fix FPGA EEPROM footprint
    * Fix reset button footprint
    * Connect ADV I2C to MCU
    * Fix missing ground to hotplug power off circuit
    * Move LED power connector to back of board
    * Move standby button to front of board
    * Only use HDMI 5v for hotplug detect
    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
    [hdmilight-v3-fpga.sch, hdmilight-v3-hdmi.sch, hdmilight-v3-io.sch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]
2020-05-08 Aded gerbers and schematic for v3.1 board
2020-05-10 Cleaned up makefiles, updated README
    [hdmilight-v3-openocd.cfg]
2020-05-12 Fixed ADV and format change interrupt support for external MCU
    [hdmilight.ucf, main.c]
2020-05-14 removed old unused silscreen labels
    [hdmilight-v3.kicad_pcb]
2020-05-14 Added v3.1 BOM
    [hdmilight-v3.1-bom.csv]
2020-05-15 Updated BOM with individual LED colours/types
    [hdmilight-v3-fpga.sch, hdmilight-v3-hdmi.sch, hdmilight-v3-usb.sch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]
2020-05-16 Fix level shifter part number 74LV245 -> 74LVC245
    [hdmilight-v3-io.sch, hdmilight-v3.1-bom.csv]
2020-05-16 Fixed overlapping silkscreen labels on back of board
    [hdmilight-v3.kicad_pcb]
2020-05-17 Update FPGA constraints for v3.1 board
2020-05-18 Fixed missing last byte when writing FPGA config via SPI
2020-05-19 BOM updates
    * Don't need EEPROM for FTDI
    * Change LED power switching transistor to the one I actually used
    * Sync CSV and interactive BOM files
    [hdmilight-v3-io.sch, hdmilight-v3-usb.sch, hdmilight-v3.1-bom.csv]
2020-05-22 Implement standby button
2020-05-23 Fix LEDs lighting blue with no signal * Change HDMI config to default to 1920x1080 so that a default ambilight config will be matched * Fix LED power enable drive, now push-pull, was open-drain * Cha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
    [power.c]
2020-05-23 Fixed interrupt related deadlocks
    Interrupt handlers use I2C and SPI comms with FPGA and ADV7611. If these occurred while other code
    was in the middle of a transaction then the I2C/SPI controller would be left in an unexpected
    state and the code could be left waiting for data to arrive that had already been flushed out
    Also, the STM32 doesn't support level triggered interrupts and it's possible to miss a rising-edge.
    Added a polling function to check for missed interrupts every 250ms. Without this there would
    be no more interrupts from the FPGA as it would wait forever for the missed one to be cleared
    [adv7611.c, fpga.c, main.c]

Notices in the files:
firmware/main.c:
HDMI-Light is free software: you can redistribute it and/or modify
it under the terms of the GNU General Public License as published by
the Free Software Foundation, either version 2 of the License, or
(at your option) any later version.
